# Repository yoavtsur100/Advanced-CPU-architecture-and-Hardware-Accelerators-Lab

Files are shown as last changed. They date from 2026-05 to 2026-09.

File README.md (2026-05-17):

 Advanced CPU Architecture & Hardware Accelerators - VHDL Labs

Welcome to my hardware development repository. This project covers the end-to-end design process of digital systems and processors, from the physical layer to the application layer, implemented in VHDL and validated on FPGA.

## Project Overview
These labs focus on professional hardware design methodologies, emphasizing the full development cycle:
* **Design & Optimization:** Combinational, Synchronous, and Integrated digital systems designed under **PPA (Power, Performance, and Area)** constraints.
* **Verification:** Functional verification, Timing verification, and hardware validation on **FPGA** chips.
* **Computer Architecture:** Deep dive into ISA and Microarchitecture, with a strict separation between **Control Unit** and **Datapath**.

## Development Milestones

## Phase 1: Digital Logic Fundamentals
Implementation of foundational digital systems using VHDL, focusing on synthesis-friendly coding styles and comprehensive Testbench verification.

## Phase 2: CPU Core Development
* **Multicycle Processor:** Designing a separate Control and Datapath architecture.
* **Single-Cycle Processor:** Full implementation and FPGA deployment.
* **V-RISC Pipelined Core:** Development of an N-stage single-threaded pipelined RISC-V processor.

### Phase 3: Final Project - Full MCU System
Design and integration of a complete **Microcontroller Unit (MCU)** on an FPGA, based on a pipelined core. The system features:
* **Peripheral Modules** (IO, Timers, etc.).
* **Interrupt Controller.**
* **Hardware Accelerators (HW Accelerators)** – optimized from the physical layer up to the application software.

---
*Developed as part of the Electrical and Computer Engineering curriculum at Ben-Gurion University.*

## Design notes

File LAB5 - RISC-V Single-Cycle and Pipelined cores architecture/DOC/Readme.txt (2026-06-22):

LAB5 – RISC-V RV32IM Processor Implementation

Advanced CPU Architecture and Hardware Accelerators Lab – 361-1-4693
This project implements a fully functional RV32IM RISC-V processor on a Cyclone V FPGA board (DE10-Lite), in two separate implementations:

-Task 1 – Single-Cycle: Each instruction completes in exactly one clock cycle.
- Task 2 – Pipelined: A classic 5-stage pipeline (IF → ID → EX → MEM → WB) with full hazard detection and resolution.

Both implementations are verified against a RARS golden reference model across four benchmark test programs.

Created by **Yoav Tsur and Elad Lavi**.

Input and Output Description

CLOCK_50_iInput-50 MHz system master clock
KEY0_i-Input  Active-low push-button for synchronous reset (first press releases the CPU from power-up hold) 
SW_i[7:0]- Input -Switches for Signal-Tap trigger address (word address of breakpoint PC) 

clkcnt_o[15:0]` -Output -16-bit clock cycle counter (resets on KEY0, counts from start of execution) 
IFpc_o- Output -Program Counter at the Fetch (IF) stage 
IFinstruction_o- Output -Instruction word at the Fetch (IF) stage 
IDpc_o IDinstruction_o -Output - PC and instruction at the Decode (ID) stage 
EXpc_o EXinstruction_o- Output -PC and instruction at the Execute (EX) stage 
MEMpc_o MEMinstruction_o=Output -PC and instruction at the Memory (MEM) stage 
WBpc_o WBinstruction_o- Output- PC and instruction at the Write-Back (WB) stage 
STRIGGER_o-Output -Signal-Tap trigger: goes HIGH when IFpc[9:2] = SW[7:0] 
FHCNT_o[7:0]- Output - 8-bit flush event counter (counts pipeline flushes due to taken branches) 
STCNT_o[7:0] Output - 8-bit stall cycle counter (counts Load-Use hazard stall cycles) 

Task 1 – Single-Cycle Implementation

All five datapath stages (Fetch, Decode, Execute, Memory, Write-Back) are completed within a single clock cycle. There are no pipeline registers between stages and no hazard handling is required.

VHD Files

cond_compilation_package.vhd
Defines all conditional compilation constants that control the memory configuration and simulation/synthesis mode:
-G_MODELSIM – Selects between ModelSim (1) and Quartus/FPGA (0) mode.
- G_WORD_GRANULARITY` – Selects word-addressed (True) or byte-addressed (False) memory.

const_package.vhd
Defines all instruction-level constants: opcode values, ALU operation codes, and RISC-V instruction format fields used throughout the datapath and control unit.

aux_package.vhd
A VHDL package declaring all component interfaces used across the project (IFETCH, IDECODE, EXECUTE, DMEMORY, etc.), enabling structural instantiation in the core top-level file.

IFETCH.VHD
Implements the Instruction Fetch stage. Contains the Instruction Tightly Coupled Memory (ITCM) instantiated as an Altera altsyncram ROM, pre-initialized from a .hex file. Computes PC+4 via a combinational adder and selects the next PC value using two multiplexers: one for branch/JAL targets and one for JALR targets. The PC register updates synchronously on the rising clock edge.

IDECODE.VHD
Implements the Instruction Decode stage. Contains the 32×32-bit Register File with two asynchronous read ports and one synchronous write port (clocked on the falling edge to enable same-cycle read-after-write). Performs sign-extension of immediate fields for all RISC-V instruction formats (I, S, B, U, J types).

CONTROL.VHD
Implements the combinational Control Unit. Decodes the 7-bit opcode and generates all control signals: RegWrite, MemWrite, MemRead, MemtoReg, ALUSrc, Branch, Jal, Jalr, UpperIm, ALUOp, MULop, and WBSrc. Supports all RV32IM instruction types (R, I, S, B, U, J) including the MUL instruction extension.

EXECUTE.VHD
Implements the Execute stage. Contains the main ALU that performs arithmetic (ADD, SUB, SLT, SLTU), logical (AND, OR, XOR), shift (SLL, SRL, SRA), and comparison operations based on the 5-bit ALUOp control signal. Also computes the branch/JAL target address by adding the sign-extended immediate to the PC. The branch condition (brTaken) is resolved combinationally here. Integrates the multiplier_16bit sub-module for MUL operations.

multiplier_16bit.vhd
Implements a combinational 16-bit×16-bit multiplier supporting the RV32M MUL instruction extension. Uses a two-stage decomposition: splits the 16-bit operands into 8-bit halves, computes four 16-bit partial products (P0–P3), sums the cross-terms (P1+P2), and accumulates all partial products with appropriate bit-shifts to produce a 32-bit result.

DMEMORY.VHD
Implements the Memory stage. Contains the Data Tightly Coupled Memory (DTCM) instantiated as an Altera altsyncram in single-port mode, pre-initialized from a .hex file. Supports synchronous write (on the inverted clock edge) and combinational read. Also selects between the ALU result and the multiplier result based on WBSrc.

RV32I_CORE.vhd
The structural top-level of the single-cycle processor. Instantiates and interconnects all five stage modules (IFETCH, IDECODE, CONTROL, EXECUTE, DMEMORY) using internal signals. Manages the PLL instantiation (active when G_MODELSIM=0) or direct clock bypass (when G_MODELSIM=1). Includes a free-running 16-bit clock counter that resets synchronously and counts cycles from reset release.

FPGA_Top_SingleCycle.vhd
The FPGA top-level wrapper for the single-cycle implementation. Directly maps physical board signals (CLOCK_50, SW0 for reset) to the RV32I_CORE ports. Exposes all internal signals as outputs for Signal-Tap probing and hardware verification.

PLL.vhd
An Altera altpll megafunction-generated component. Takes the 50 MHz board oscillator and divides it to produce a stable lower-frequency internal clock for the processor core. Active only when G_MODELSIM=0 (FPGA synthesis mode).

 Task 2 – Pipelined Implementation

A classic 5-stage in-order pipeline: IF → ID → EX → MEM → WB. Pipeline registers separate each stage. The design includes:
- Load-Use Hazard Detection – inserts one stall cycle (bubble into ID/EX register).
- Control Hazard Resolution – flushes the three instructions after a taken branch (resolved in MEM stage).
- Data Forwarding – forwards EX→EX and MEM→EX paths to eliminate most RAW hazards without stalling.
- Power-Up Reset Latch – holds the CPU in reset until KEY0 is pressed at least once after FPGA configuration.

cond_compilation_package_pipeline.vhd
Same role as in the single-cycle design but for the pipelined version. Key parameters:
- G_MODELSIM – 0 for FPGA synthesis (enables PLL), 1 for ModelSim simulation (bypasses PLL).
- G_ADDRWIDTH / `G_DATA_WORDSNUM` – Must match the depth of the .hex 

const_package_pipeline.vhd
Defines all RISC-V opcode and ALU operation code constants for use throughout the pipeline stages.

aux_package_pipeline.vhd
Declares all pipelined component interfaces for structural instantiation in the core.

IFETCH_pipeline.vhd
Implements the Instruction Fetch (IF) pipeline stage. Contains the ITCM (altsyncram ROM) pre-initialized from a .hex file. Computes PC+4 combinationally and selects the next PC through two multiplexers controlled by Branch_or_jal and Jalr_ctrl. The PC register updates synchronously with stall support via the PCwrite_i enable signal.

IDECODE_pipeline.vhd
Implements the Instruction Decode (ID) pipeline stage. Contains the 32×32-bit Register File with asynchronous reads and a synchronous write port (falling-edge clocked). Performs sign-extension of all immediate formats. Outputs register values and sign-extended immediate to the ID/EX pipeline register.

CONTROL_pipeline.vhd
Implements the combinational Control Unit for the pipeline. Decodes opcode and funct3/funct7 fields to generate all pipeline control signals. When a stall is inserted, control signals are zeroed (NOP bubble).

EXECUTE_pipeline.vhd
Implements the Execute (EX) pipeline stage. Contains the main ALU performing all RV32IM arithmetic, logical, shift, and comparison operations. Selects ALU operands through forwarding multiplexers. Computes the branch/JAL target address. Instantiates the 16-bit multiplier sub-module for MUL support.
DMEMORY_pipeline.vhd
Implements the Memory (MEM) pipeline stage. Contains the DTCM (altsyncram single-port) pre-initialized from a .hex file, with synchronous write and asynchronous read. Generates the Flush_o signal when a taken branch is detected, triggering a 3-cycle flush of the IF/ID/EX pipeline registers.

WriteBack_pipeline.vhd
Implements the Write-Back (WB) pipeline stage. Selects between the DTCM read data and the ALU/multiplier result using multiplexers controlled by MemtoReg and WBSrc. Outputs the final write-back data to the register file.

Forwarding_unit.vhd
Implements the Data Forwarding Unit. Compares the source register addresses (rs1, rs2) of the EX-stage instruction with the destination register addresses (rd) of the MEM-stage and WB-stage instructions. Generates 2-bit forwarding select signals (ForwardA, ForwardB) to route the correct data to the ALU inputs, eliminating most RAW data hazards without stalling.

Stall_cond_unit.vhd
Implements the Hazard Detection / Stall Condition Unit. Detects Load-Use hazards: when the EX-stage instruction is a load (MemRead=1) and its destination register matches a source register of the immediately following ID-stage instruction. When detected, de-asserts PCwrite and IFID_write (freezing IF and ID stages) and inserts a NOP bubble into EX for one cycle.

RV32I_CORE_pipeline.vhd
The structural top-level of the pipelined processor. Instantiates and interconnects all five pipeline stage modules and the two hazard-handling units. Contains all five inter-stage pipeline registers as synchronous processes with synchronous reset. Includes three free-running counters:
- `mclk_cnt_q` – Total clock cycle counter.
- `stl_cnt_q` – Stall cycle counter (increments when stall=1).
- `fhl_cnt_q` – Flush cycle counter (increments when MEM_flush=1).

Also generates STRIGGER_w: goes HIGH when IFpc[9:2] = SW[7:0], used as the Signal-Tap hardware trigger for breakpoint-based verification.

FPGA_Top_pipeline.vhd
The FPGA top-level wrapper for the pipelined implementation. Key features:
- **Power-Up Reset Latch:** A flip-flop that initializes to '0' and latches to '1' upon the first press of KEY0, preventing the CPU from executing on uninitialized memories immediately after FPGA configuration.
- Routes SW_i[7:0] to BPADDR_i for Signal-Tap trigger address selection.

PLL_pipeline.vhd
An Altera altpll megafunction-generated component. Uses a ×1/÷2 configuration to produce a stable 25 MHz internal clock from the 50 MHz board oscillator. Active only when G_MODELSIM=0.

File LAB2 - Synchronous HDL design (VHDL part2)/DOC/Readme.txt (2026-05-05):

Project Overview:
In this laboratory, we will design a synchronous digital system that detects valid sub-series for a given conditional value. We have designed the system top module by using Adder sub-module. The system’s primary goal is to identify sequences where the difference between two consecutive N-bit samples (x[j-1] - x[j-2]) remains constant and matches a specific value determined by the Detection code input. 
Input and Output Description:
* Data Inputs (x): The system samples the value of x (An n-bit wide vector representing the incoming data stream) at every rising edge of clk, provided that ena is high. These samples are stored in a two-stage pipeline to calculate the arithmetic difference.
* clk(clock): The system's primary timing signal. All operations are synchronized to the rising edge of this signal.
* rst (Reset): An active-high control signal. When asserted, it initializes the system by clearing the sampling registers and sequence counter, forcing the Detector output to 0.
* ena (enable): A control signal that governs system operation. If de-asserted ('0'), the system enters a "frozen" state where it ignores new samples and pauses the counter.
* DetectionCode: A selection input that defines the required arithmetic difference for detection. It maps values (0–3) to the expected differences (1–4) according to the project specifications.
* Detection Flag - OUTPUT: This logical signal is 1 only when the system identifies a valid sub-series that meets the difference criteria. It returns to 0 immediately if the sequence is broken or the system is reset.

The VHD file:
AuxPackage.VHD:
* This file contains in the form of a package all the components that we would like to use throughout the laboratory.
Adder.VHD:
* This module implements a generic ripple adder.
Top.VHD:
* This module wraps the entire system and implements a structural and behavioral design hierarchy. We were asked to separate the task into 3 processes:
1. Sampling Process: Responsible for sampling the input data stream x. It uses a two-stage pipeline to store the current and previous samples.
2. Logic & Calculation Process: This stage performs the arithmetic operation using a structural Ripple Carry Adder. It calculates the difference between the samples and compares it against the expected value. A valid signal is asserted if matches.
3. Counting & Detection Process: This process manages a synchronous counter. Only when the enable is '1' and the valid signal is asserted, the counter increments. If the valid signal drops or a reset occurs, the counter is cleared to 0. Once the counter reaches the threshold , the detector output is asserted to 1.

Created by Yoav Tsur and Elad Lavi.

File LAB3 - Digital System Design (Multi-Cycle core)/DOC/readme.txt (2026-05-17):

Multi-Cycle Processor Core in VHDL

This project implements a multi-cycle processor core in VHDL.
The processor is organized around a Control Unit and Datapath architecture, supporting arithmetic, logical, memory access, and branching instructions.

Input and Output Description:
* clk – system clock .
* rst – processor reset.
* ena – processor enable signal.
* done – indicates completion of program execution.(Output) 
* Testbench Interfaces
Additional testbench ports are included for simulation support, allowing:
* Program memory (ITCM) initialization
* Data memory (DTCM) initialization
* Memory read/write access during verification
* Testbench-controlled execution flow. 

Top.vhd 
Top-level integration module connecting the Control Unit (FSM), Datapath.
From the datapath we get the status registers of which instruction we need to perform, and the FSM will output the control data for the datapath to perform the needed task.

Control.vhd 
 FSM-based control unit its purpose is to receive the op code the system needs to perform.
The right control flags will turn on to the datapath and dictating the needed operation.

Datapath.vhd   
Main datapath implementation responsible for data movement between processor components, including register transfers, ALU execution, and memory access operations.  
Implements a shared bus architecture with tri-state buffers for controlled data transfer between modules.

ALU.vhd 
Arithmetic Logic Unit implementing arithmetic and logical operations such as add, sub, OR, AND, and XOR.  
Additionally, generates processor status flags: Negative (N), Zero (Z), and Carry (C).

Adder.vhd
This module implements a generic ripple adder.

OpcodeDecoder.vhd  
Decodes the opcode from IR[15:12] and outputs the corresponding instruction signals to the Control Unit.

RF.vhd 
Register File implementation for general-purpose registers, supporting read and write operations for processor instruction execution.

RegisterA.vhd  
Temporary operand register used in the datapath to store ALU input operands during instruction execution.

RegisterC.vhd
Temporary result register used in the datapath to store ALU output values during instruction execution. Implemented as a master-slave register for synchronized sequential operation.

IR.vhd  
Instruction Register (IR) module responsible for latching instructions fetched from program memory when IRin = '1', and providing decoded instruction fields such as opcode, offset, and immediate values for execution.

ProgamCounter.vhd
Program Counter (PC) module responsible for tracking instruction execution flow by storing the current instruction address and updating it for sequential execution or jump operations.

DFlop.vhd 
Generic D Flip-Flop module providing synchronous data storage with clock and reset control, used throughout the processor’s sequential logic.

progMem.vhd 
Program memory module responsible for storing assembly instructions and supplying the appropriate instruction to the processor according to the current Program Counter (PC) address.

dataMem.vhd  
Data memory module used for processor data storage, supporting read and write access for load and store instructions.

BidirPin.vhd 
Bidirectional interface module implementing tri-state bus connectivity for controlled data transfer between shared processor modules.

aux_package.vhd 
This file contains in the form of a package all the components that we would like to use throughout the laboratory.

Created by Yoav Tsur and Elad Lavi.

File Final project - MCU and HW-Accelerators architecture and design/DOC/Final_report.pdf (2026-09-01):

## FINAL REPORT FOR FINAL PROJECT

## ADVANCED CPU ARCHITECTURE AND HARDWARE

## ACCELERATORS LAB

361.1.4693

## Yoav Tsur 211903406 Elad Lavi 211626551

## 2026 Semester B

## תוכן עניינים

מבוא למערכת הכוללת 3
חלק ראשון - הליבה Core V-RISC 5 תוספת המחלק לליבה כמאיץ חומרתי 9 ולידציה עבור פעולת המחלק 13 חלק שני - Peripherals GPIO 15 ולידציה עבור רכיבי הGPIO 18 חלק שלישי - פסיקות - Interrupts 20 ולידציה עבור רכיבי :Interrupt 26 חלק רביעי - הטמעת המערכת בכרטיס 10DE FPGA 29 חלק חמישי - ניתוח ביצועים 31

## מבוא למערכת הכוללת

במעבדה זו נממש מערכת מורכבת המתבססת על ליבת מעבד הסינגל סייקל ממעבדה מספר 5 ונרחיב אותה למערכת שלמה המבצעת גם חלוקה ושארית, ובנוסף התמודדות עם בקשות פסיקה תוך כדי שגרה שוטפת, תקשורת שוטפת לGPIO וסנכרון בין שעונים בתדרים שונים )CDC). להלן ליבת המעבד לאחר ההרחבה:

ליבה זו מרחיבה את ליבת המעבד סינגל סייקל לתמיכה בפעולת חילוק בין שני מספרים UNSIGNED הדורשת הוספת מאיץ חומרתי ייעודי לשם כך והוספת לוגיקה. בנוסף כפי שניתן לראות מן התמונה, מודול המחלק מוזן משעון שונה divclk ולשם כך נדרש סנכרון בין פעילות המעבד השוטפת המוזנת מן השעון mclk לבין שעון המחלק.
כעת נציג את המערכת הכוללת:

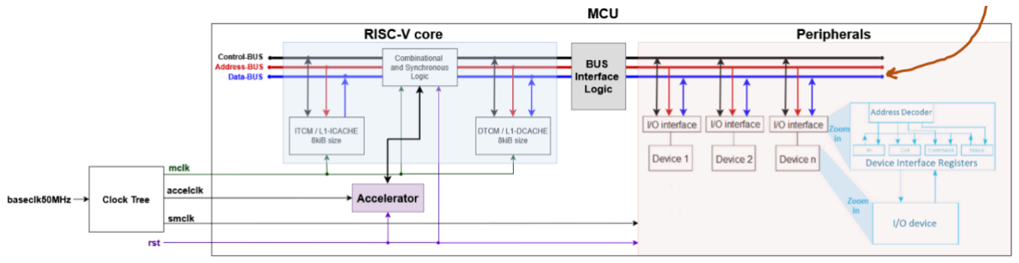
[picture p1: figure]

Figure 1: MCU System uArch

כפי שניתן לראות באיור, המערכת כולה מתוכננת כמיקרו-בקר שלם הכולל הפרדה פיזית בין זיכרון התוכנית לבין זיכרון הנתונים. הקישוריות בין הליבה לבין שאר חלקי המערכת מתבצעת דרך מערכת באסים הכוללת את באס הכתובות, באס הנתונים ובאס הבקרה. דרך קווים אלו, המעבד מנהל את התקשורת מול הזיכרון ומול הלוגיקה המקשרת לרכיבים הפריפריאליים.

אפיק הנתונים הפנימי של הליבה מקושר באמצעות באס נתונים דו-כיווני משותף ברוחב 32 ביט. בנוסף נעשה שימוש ב-buffers state-Tri, באמצעות רכיב BidirPin כאשר אנחנו מווסתים את היציאות של כתיבת נתוני המעבד וקריאת נתוני ה-DTCM אל הבאס, ובכך מונעים Contention Bus.

התקשורת מול רכיבי קלט/פלט )interface O/I )מתבצעת בשיטת O/I Mapped Memory, שבה הרכיבים החיצוניים ממופים כחלק ממרחב הכתובות של זיכרון הנתונים. מרחב כתובות זה מחולק לשני אזורים לוגיים עיקריים: החלק התחתון מוקצה לזיכרון הנתונים הפיזי, ואילו החלק העליון שמור לאוגרים ייעודיים )- SFR Registers Function Special )המשמשים את רכיבי הפריפריה השונים. הגישה לרכיבי ה-GPIO ולזיכרון עצמו נעשית על ידי מפענח כתובות חומרתי, אשר מנתח את הכתובת בת 14 הביטים שמייצר המעבד וקובע בזמן אמת איזה רכיב מופעל.חלוקת מרחב כתובות זה מוצג באיור הבא:

Figure 2: Data Address Space Map

בנוסף לממשק הO/I, המערכת מורחבת על ידי הוספת רכיבים פריפריאליים מתקדמים התומכים בפסיקות, ביניהם טיימר בסיסי בעל יכולות השוואה והפקת אותות PWM, ובקר פסיקות. מנגנון הפסיקות מאפשר למעבד להשהות את שגרת הביצוע השוטפת שלו על מנת להגיב לאירועים חיצוניים בזמן אמת. כאשר מתקבלת דרישת פסיקה מאחד ממקורות הפריפריה, בקר הפסיקות שולח אות בקשה )INTR )למעבד. בתגובה, המעבד משיב באות אישור )INTA )וקופץ לטפל באירוע בהתאם לרמת העדיפות המוגדרת עבורו בטבלת הפסיקות.

לשם ניהול זמנים והפעלה תקינה של כלל תתי-המערכות, מיושם במערכת עץ שעונים. עץ השעונים מקבל שעון בסיס של MHz50 ומפיק ממנו מספר תחומי תדר שונים הנדרשים למודולים השונים: שעון ה-mclk המזין את ליבת המעבד המרכזית, שעון ה-smclk עבור רכיבי הפריפריה, ושעון ה-accelclk המזין את המאיץ החומרתי. חלוקה זו של שעונים בתדרים שונים מחייבת יישום מנגנוני סנכרון על מנת להבטיח העברת נתונים אמינה ולמנוע מצבי מטא-סטביליות.

## חלק ראשון - הליבה Core V-RISC

ארכיטקטורת הליבה הכוללת )IMscMCU32RV): ליבת המעבד ממומשת כמודל VHDL מבני בקובץ vhd.IMscMCU32RV. הליבה משלבת ארכיטקטורת זיכרון מסוג הארוורד. הליבה פועלת כולה בארכיטקטורת מחזור-יחיד למעט הרחבת מאיץ החילוק הרב-מחזורי. כל פקודה רגילה נשלפת, מפוענחת, מבוצעת, ותוצאותיה נכתבות חזרה לFile Register או לזיכרון ה-DTCM בתוך מחזור שעון אחד. נשים לב כי קובץ הבקרה )vhd.control )כולל בתוכו גם את מכונת המצבים לטיפול בפסיקות והתאמת הבקרה והלוגיקה הנדרשת למערכת כולה, כמו כן בוצעו התאמות לשאר חלקי המעבד על מנת לתמוך בזרימה כוללת תקינה כנדרש.

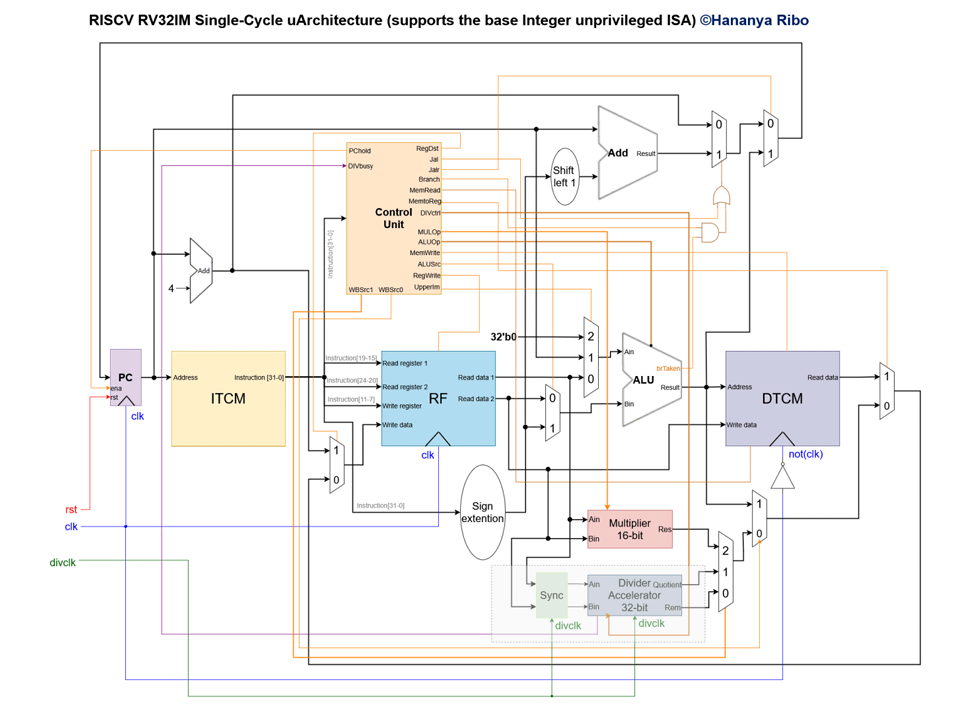
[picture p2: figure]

Figure 3: RISCV RV32IM uArch

קבצי VHD בסיסיים המרכיבים את הליבה:

IFETCH.VHD .1
שלב זה אחראי על יצירת הכתובת הבאה של מונה התוכנית )PC )ושליפת הפקודה )32 ביט( מזיכרון ה-ITCM. בשלב זה ישנם מספר רכיבי חומרה הנמצאים בשימוש: מונה התוכנית )PC): בגודל 32 ביט השומר את כתובת הפקודה הנוכחית. מתעדכן בעליית השעון, אלא אם כן דגל ההשהיה PChold פעיל.
Adder Sequential מחשב את הכתובת הבאה )+4PC )במקביל לביצוע הפקודה הנוכחית, ומכין את כתובת ברירת המחדל לפקודה העוקבת. Multiplexers Address Target בוררים את מקור הכתובת הבאה של ה-PC בהתאם לאותות הבקרה משלב Execute ומיחידת הבקרה.
פסיקה )Target Interrupt): כאשר האות i_ctrl_IntJump פעיל )בזמן קפיצה לשגרת טיפול בפסיקה(, ה-PC מדלג לכתובת הווקטור הנקראת מתוך טבלת הפסיקות )IVT). באמצעות ה ITCM מזהים את ה Instruction שיש לבצע.

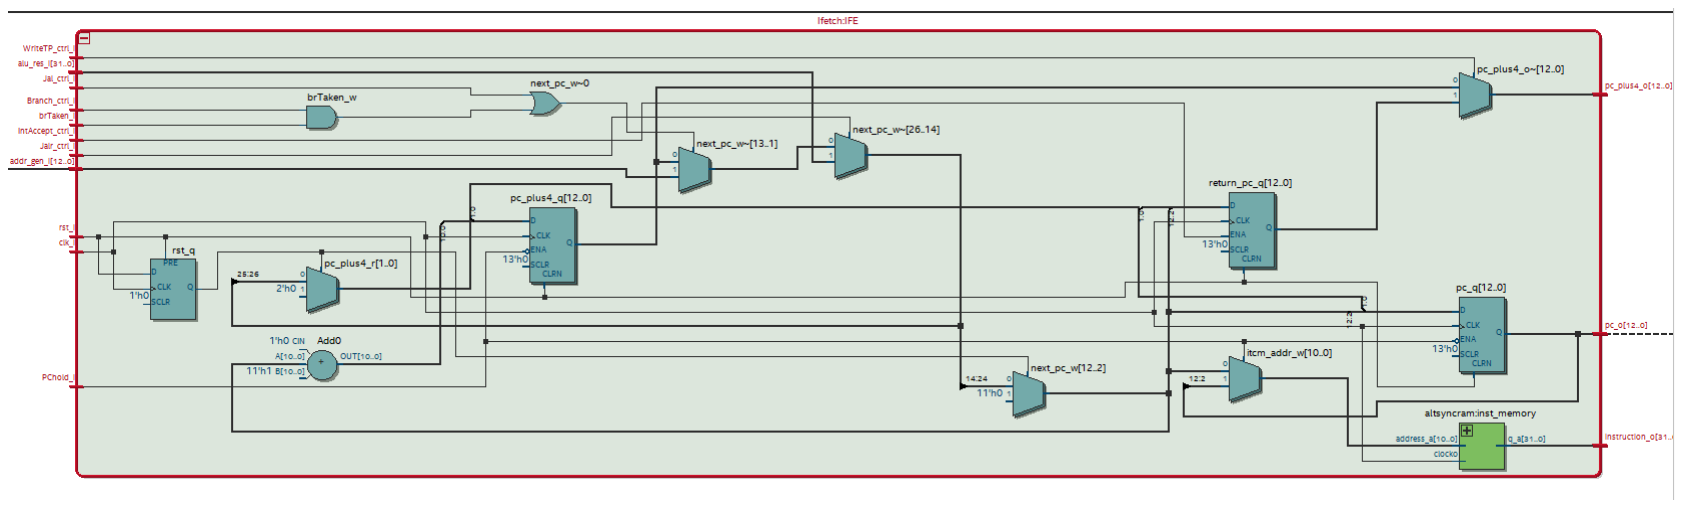
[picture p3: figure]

Figure 4: RV32IM Fetch Unit RTL

IDECODE.VHD .2
שלב זה אחראי על פירוק הפקודה שנשלפה והעברת השדות ליחידת הבקרה )שנמצאת בשימוש בשלב הדיקוד גם כן(, קריאת האופרנדים מתוך ה־File Register והפקת ערך ה־Immediate בהתאם לפורמט הפקודה.
File Register: מכיל 32 אוגרים כלליים בגודל 32 ביט )31x–0x). הקריאה מתבצעת דרך שני פורטי קריאה בהתאם לשדות 1rs ו־2rs של הפקודה. כתיבה לאוגר היעד rd מתבצעת בעליית השעון כאשר Reg ctrl_Write פעיל. האוגר 0x נשאר קבוע בערך .0 Extension Sign / Immediate: המודול מחלץ את שדה ה־Immediate בהתאם לסוג הפקודה ,U ,B ,S ,I J ומרחיב אותו ל־32 ביט תוך שמירה על הסימן. MUX Back-Write: הנתון הנכתב ל־RF נבחר בין תוצאת ה־ALU, נתון שנקרא מה־DTCM או כתובת החזרה +4PC, בהתאם לאותות הבקרה. בקרת פסיקות: הביט 0 באוגר 3x משמש כ־GIE Enable Interrupt Global. בעת כניסה לטיפול בפסיקה הביט מאופס, ובחזרה מהפסיקה הוא נקבע מחדש ל־.1 בנוסף, בעת כניסה לפסיקה ניתן לכפות את 4x כאוגר היעד לצורך שמירת כתובת החזרה.

Figure 5: RV32IM Decode Unit RTL

EXECUTE.VHD .3
שלב זה אחראי על ביצוע הפעולות האריתמטיות, הלוגיות ופעולות ההזזה על האופרנדים. בנוסף, הוא מעריך תנאי קפיצה ומחשב את כתובות היעד.
.ALUה־ | ליחידת | bin_wו־ ain_w | הכניסות | את | בוררים | :Operand Source MUXs
w_ain בורר בין ערך האוגר 1data_read לבין כתובת ה־PC הנוכחית, ו־w_bin בורר בין 2data_read לבין .sign_extend
יחידת ALU: מבצעת את הפעולות בהתאם לאות ctrl ALUOp, כולל פעולות אריתמטיות, לוגיות, הזזה והשוואה.
בין | בוחר | WBSrc1 | האות | ,REMו־ MUL, DIV | בפקודות | תמיכה | לצורך | :M-extension Result MUXs
RESIDUE עבור REM, QUOTIENT עבור DIV, ותוצאת המכפל w_resmul עבור MUL. לאחר מכן, 0WBSrc בוחר בין תוצאת ה־extension-M לבין תוצאת ה־ALU הרגילה )r_res_alu), והתוצאה הנבחרת מועברת דרך o_res_alu להמשך ה־datapath.

Figure 6: RV32IM Execute Unit RTL DMEMORY.VHD .4
מודול זה מממש את זיכרון הנתונים DTCM, שבו מאוחסנים משתני הנתונים של התוכנית. שעון הזיכרון: שעון הכתיבה לזיכרון הוא השעון ההפוך של שעון המעבד )i_clk not <= w_wrclk). לכן פעולת הכתיבה מתבצעת בחזית הנגדית לזו שבה מתעדכנים רכיבי המעבד, וכך ניתנת לכתובת ולנתוני הכתיבה אפשרות להתייצב לפני הכתיבה לזיכרון כיוון שאנחנו "מחלקים את המחזור" לשני חלקים. נתיב כתיבה: כאשר ctrl MemWrite פעיל, הערך wr_data_dtcm נכתב לתא הזיכרון הנבחר על ידי .dtcm_addr
נתיב קריאה: הערך שנמצא בכתובת addr_dtcm מתקבל ישירות ביציאה o_rd_data_dtcm. בהמשך המערכת, אותות הבקרה קובעים מתי נתון זה משמש את המעבד או מועבר ל־DataBUS.

Figure 7: RV32IM Memory Unit RTL

multiplier_16bit.vhd.5
מודול זה מממש מכפל קומבינטורי בגודל 16×16 ביט, והוא משולב בשלב ה־EXECUTE לצורך ביצוע פעולת כפל. המכפיל מקבל את 16 הביטים הנמוכים של שני האופרנדים ומפיק תוצאה בגודל 32 ביט. מכיוון שמדובר במימוש קומבינטורי, החישוב אינו דורש מכונת מצבים או מספר מחזורי שעון. אלגוריתם הכפל: כל אחד מהאופרנדים מחולק לחלק עליון ותחתון של 8 ביט. לאחר מכן מתבצעים ארבעה כפליים מקבילים בגודל 8×8 ביט:
P0=AlowBlow | P1=AlowBhigh, | P2=AhighBlow, | P3=AhighBhigh
התוצאה הסופית מתקבלת מחיבור המכפלות החלקיות לאחר הזזה למקומן המתאים. האות mulOP קובע האם תוצאת המכפל תועבר למוצא rd. כאשר לא מתבצעת פעולת כפל, המוצא מאופס.

Figure 8: RV32IM Multiplier Unit RTL

CONTROL.VHD .6
מודול זה משמש כיחידת הבקרה המרכזית של המעבד. הוא מפענח את הפקודה הנוכחית ומייצר את אותות הבקרה הדרושים לשאר יחידות ה־Datapath, בהתאם לסוג הפקודה ולפעולה הנדרשת. Decode Instruction: הפקודה מפוענחת לפי שדות ה־Opcode וה־Function לצורך זיהוי פעולות
.REMו־ MUL, DIV | פקודות | וכן Jump ,Load/Store, Branch , | ולוגיות | אריתמטיות
Signals Control: בהתאם לפקודה, המודול מייצר את אותות הבקרה כגון ,MemRead ,RegWrite
ואת | הנתונים | מסלול | את | הקובעים | ,ALUOpו־ MemWrite, ALUSrc, MemtoReg, Branch, Jal, Jalr
האותות הנדרשים למוקסים ולכתיבה/קריאה.
,WBSrc1ו־ WBSrc0 ,MULop, DIVctrl | האותות | נוצרים | REMו־ MUL, DIV | עבור | :M-Extension | בקרת
המפעילים את יחידת הכפל או החילוק ובוחרים את התוצאה המתאימה להמשך ה־Datapath. השהיית המעבד בזמן חילוק: פעולת החילוק היא פעולה רב־מחזורית, ולכן ctrl_PChold משמש לעצירת התקדמות ה־PC בזמן שהמחלק פעיל. בנוסף, q_started_div עוקב אחר תחילת פעולת החילוק ומאפשר לבצע Stall כבר במחזור הראשון, לפני ש־DIVbusy עולה, וכן מונע הפעלה חוזרת של המחלק בזמן שהפקודה מוחזקת.
המודול כולל גם את לוגיקת הבקרה הנדרשת לטיפול בפסיקות ולפרוטוקול INTA/INTR, אשר תפורט בנפרד בפרק העוסק במערכת הפסיקות.

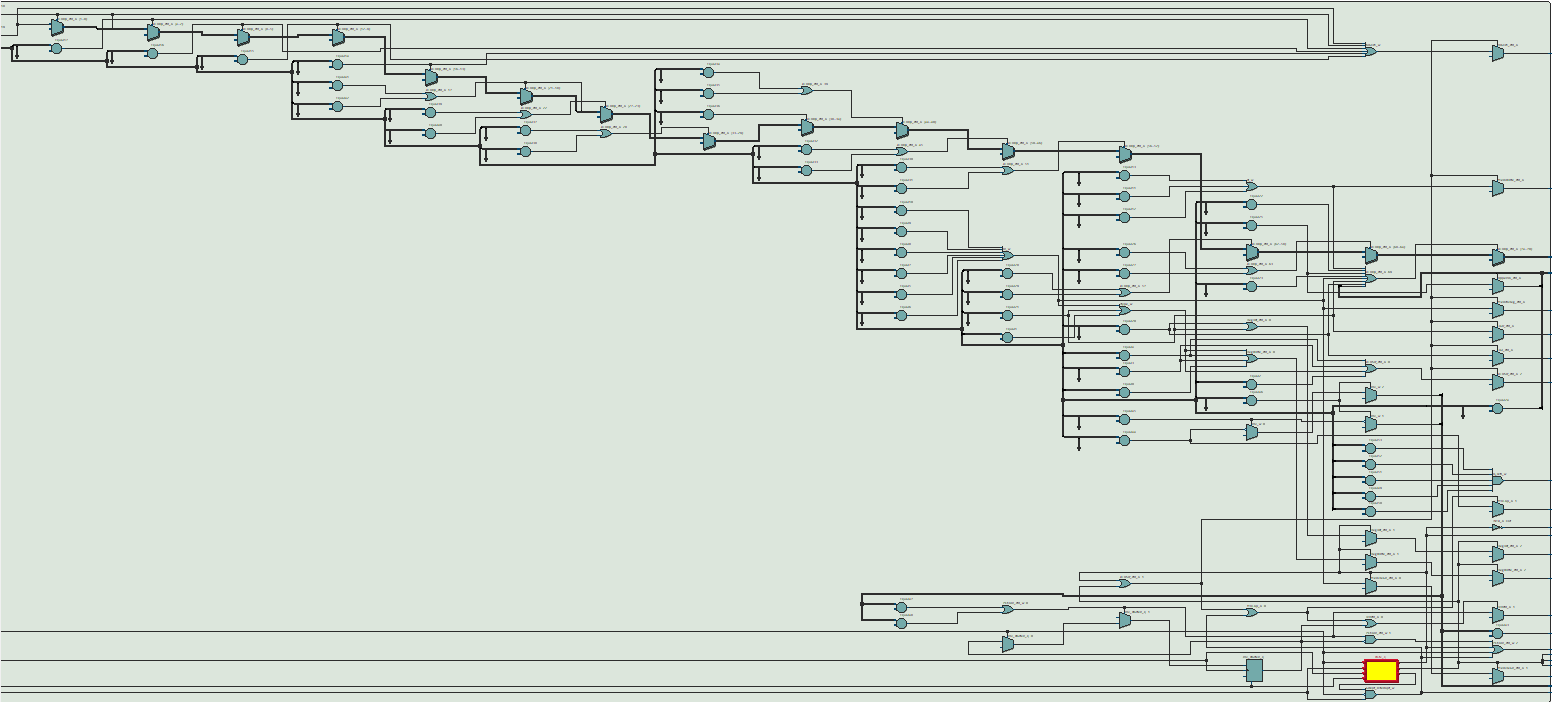
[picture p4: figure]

Figure 9: RV32IM Control Unit RTL

ובנוסף מצורף RTL כללי של הליבה המכיל את כל הרכיבים אשר פירטנו עליהם. כפי שציינו ליבה זאת מתחברת לממשק הTOP באמצעות TriState לצורך מניעת התנגשות על הBUS.

Figure 10: RV32IM Unit RTL

## תוספת המחלק לליבה כמאיץ חומרתי

:divider_32bit.vhd | המחלק | מימוש
בחלק הראשון של הפרויקט נדרשנו לממש מאיץ חומרה לביצוע פעולות חילוק ושארית )DIV ו־REM )עבור מספרים Unsigned, כחלק מהרחבת ליבת ה־IM32RV. המחלק ממומש כ־Accelerator Division Cycle Multi המחובר לליבת המעבד ופועל בתחום שעון נפרד משעון המערכת. עובר אופרנדים בגודל 32 ביט )32=N), פעולת החילוק מתבצעת באופן איטרטיבי לאורך 32 מחזורי DIVCLK.
קלטי המחלק:
Dividend – המספר המחולק.
Divisor – המספר המחלק.
DIVCLK – שעון המאיץ.
Reset – איפוס המודול.
DIVENA – אות Enable המתחיל פעולת חילוק. מוצאי המחלק:
Quotient – מנת החילוק.
Residue – שארית החילוק.
DIVBUSY – אות המציין שהמחלק נמצא במהלך ביצוע פעולה ומשמש את יחידת הבקרה לצורך עיכוב המעבד עד לסיום החישוב
אלגוריתם המחלק:
המחלק מממש אלגוריתם חילוק בינארי איטרטיבי עבור מספרים Unsigned, כאשר בפרויקט זה 32=N. כאשר אות הבקרה DIVENA עולה בזמן שהמחלק פנוי, נטענים אופרנדי ה-Dividend וה-Divisor לרגיסטרים הפנימיים, רגיסטר המנה מתאפס, המונה מתחיל מ0- ואות ה-DIVBUSY עולה ל1- כדי לאותת שהיחידה עסוקה. המימוש החומרתי עושה שימוש ברגיסטר הזזה בגודל N2 ביטים, כאשר מחציתו העליונה מחזיקה את השארית החלקית ומחציתו התחתונה מחזיקה את ביטי ה-Dividend שטרם עובדו. בכל מחזור של שעון ה-DIVCLK מתבצעת איטרציה אחת שבה השארית החלקית מוזזת שמאלה ומצורף אליה הביט הבא של ה-Dividend. הערך המתקבל מושווה ל-Divisor: אם הוא גדול או שווה לו, מתבצע חיסור )התוצאה אינה שלילית( ונוסף הביט 1 למנה, ואחרת לא מתבצע חיסור ונוסף הביט 0 למנה. התהליך חוזר על עצמו במשך 32 איטרציות, ולאחר מכן DIVBUSY יורד ל0- והתוצאות הסופיות זמינות במוצאי ה-QUOTIENT )מנת החילוק( וה-RESIDUE( שארית החילוק(. לאורך התהליך, האות DIVBUSY משמש את יחידת הבקרה של המעבד כדי להשהות את התקדמותו כל עוד פעולת החילוק הרב-מחזורית טרם הסתיימה.

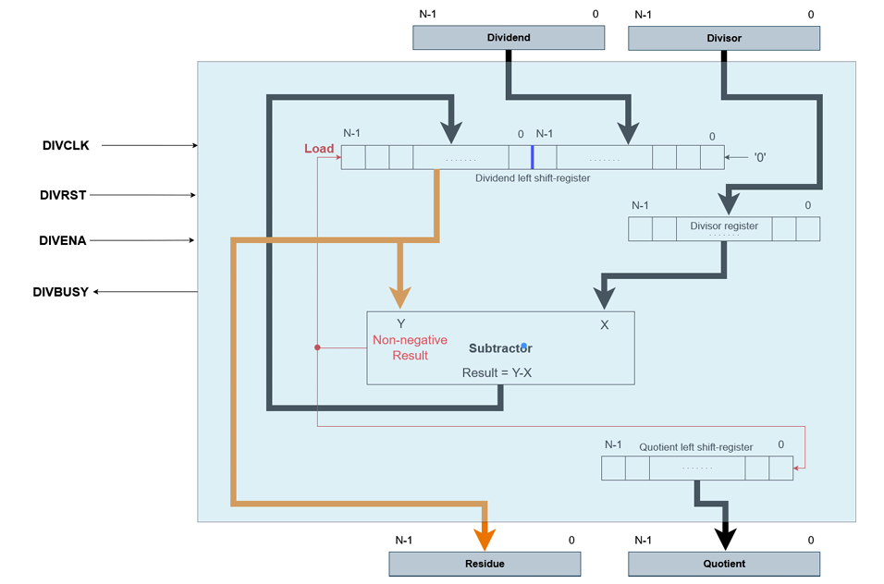
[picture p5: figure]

Figure 11: Multicycle-based architecture of Unsigned Divisor accelerator

מצורף צילום של הRTL עבור מודול ה- bit32Divider:

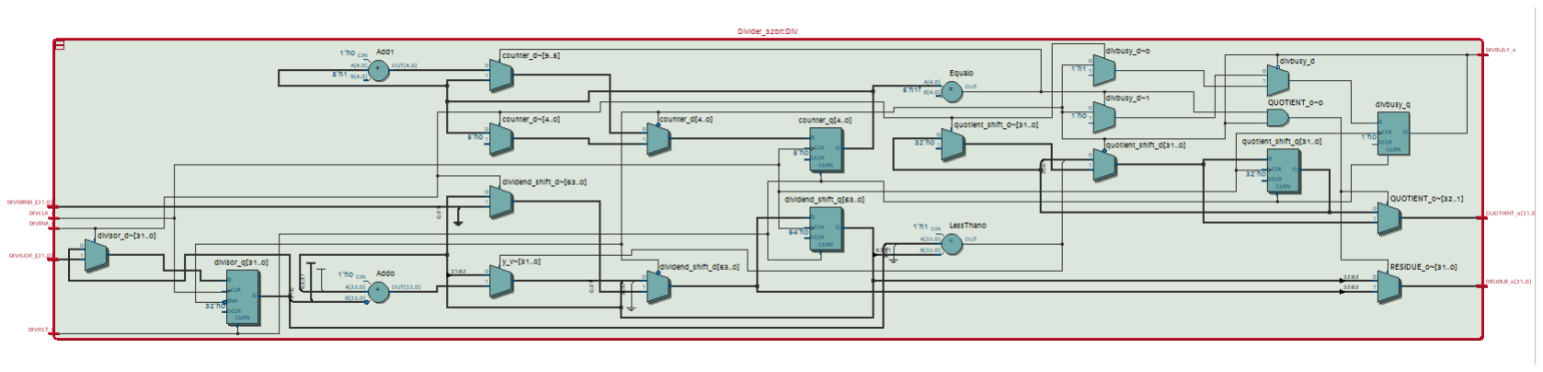
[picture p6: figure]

Figure 12: RV32IM Divider Unit RTL

:sync.vhd מסנכרן
המחלק פועל באמצעות DIVCLK, בתדר שונה משעון המערכת של המעבד. לעומת זאת, האופרנדים המועברים למחלק )Dividend ו־Divisor )מגיעים מליבת המעבד ולכן שייכים ל־Clock Domain של שעון המערכת.
כתוצאה מכך נוצר CDC Crossing Domain Clock. ללא סנכרון, שינוי באחד האופרנדים עלול להתרחש בסמוך לחזית העולה של DIVCLK, ובכך להפר את זמני ה־hold/setup של רגיסטר במחלק ולגרום למצב של Metastability. לכן לפני העברת האופרנדים למחלק הם מועברים דרך מודול Synchronizer.

אופן פעולת המסנכרן
במימוש שלנו כל אחד משני האופרנדים עובר דרך שתי דרגות של רגיסטרים, הפועלות לפי :DIVCLK
Ain_i → Ain_q1 → Ain_q2 → Ain_o Bin_i → Bin_q1 → Bin_q2 → Bin_o הדרגה הראשונה קולטת את האות המגיע מתחום השעון של המעבד ועלולה להיכנס לזמן קצר למצב metastable, ואילו הדרגה השנייה דוגמת את הערך לאחר שניתן לו זמן להתייצב. כך קטן משמעותית הסיכון להעברת ערך לא יציב אל המחלק. המסנכרן מטפל בבעיה של מעבר בין שעונים: CPU clock domain → Synchronizer → DIVCLK domain לעומת זאת, DIVBUSY מטפל בכך שהחילוק לוקח 32 מחזורי DIVCLK. בזמן 1=DIVBUSY יחידת הבקרה משהה את התקדמות המעבד, כדי שה־CPU לא יעבור לפקודה הבאה לפני שתוצאת
. | מוכנה | DIV/REM

Figure 13: CDC (clock domain crossing) synchronizer

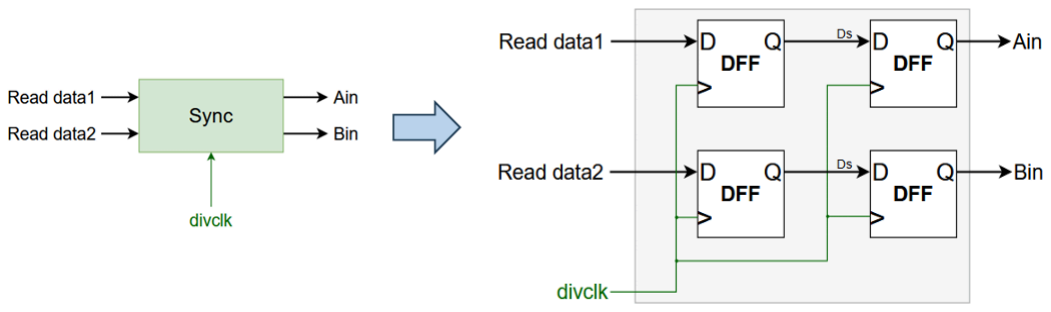
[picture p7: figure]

Figure 14: Synchronizer architecture

מצורף צילום של הRTL עבור מודול ה- Sync:

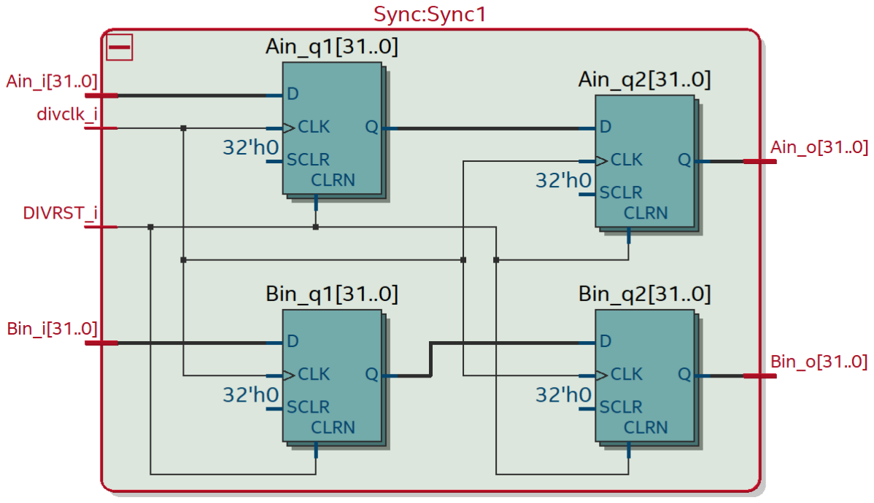
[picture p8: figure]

Figure 15: RV32IM synchronizer Unit RTL

ולדיציה עבור פעולת המחלק
על מנת לבדוק שהמחלק פועל כמו שצריך נדרשנו לבדוק התאמה ופעילות נכונה של המעבד באמצעות טסט שניתן לנו מראש.
הטסט מכיל 131 הוראות מתוכן 11 הוראות הן עבור טעינת הנתונים. שאר ההוראות בנויות מלולאה באורך 8 כך שכל סיבוב של הלולאה מונה כ15 פקודות - 13 פקודות רגילות, פקודת חילוק ופקודת שארית.

Figure 16: Divisor test instruction distribution להלן תוצאות הWaveform במודל סים:

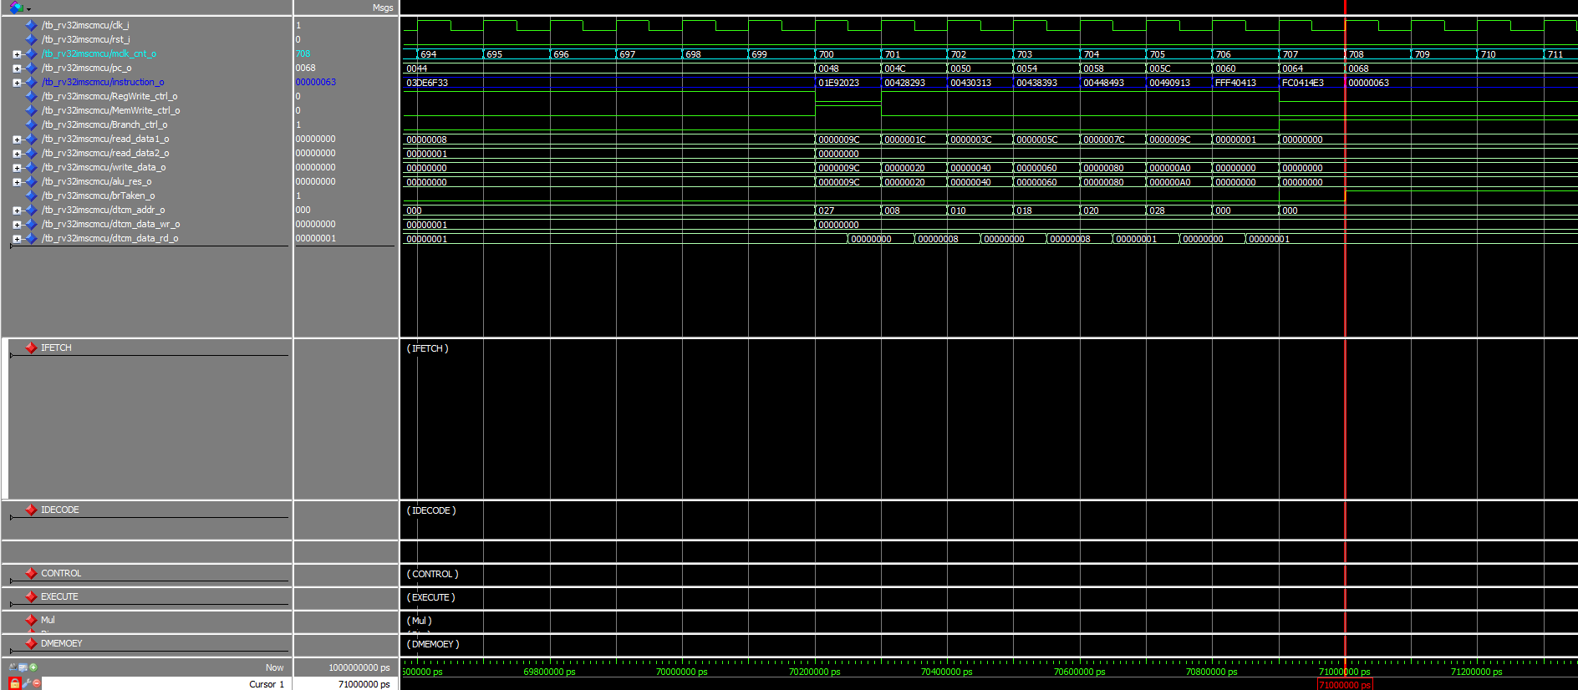
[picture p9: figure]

Figure 17: ModelSim Verification of the Division Accelerator זמן ריצה זה תואם במדויק את המצופה ממבנה הקוד: התוכנית נפתחת ב11- פקודות של טעינת נתונים, אשר כל אחת מהן מתבצעת במחזור שעון יחיד )Cycle Single). לאחר מכן, מתבצעת לולאה החוזרת על עצמה במשך 8 איטרציות. בכל איטרציה של הלולאה ישנן 15 פקודות: 13 פקודות רגילות )הדורשות מחזור שעון אחד כל אחת(, פקודת חילוק ופקודת שארית. מכיוון שפעולות החילוק והשארית מבוצעות על ידי המאיץ הרב-מחזורי, כל אחת מהן עוצרת את המעבד ואורכת 37 מחזורי שעון. מכאן נובע כי כל איטרציה בלולאה דורשת 87 מחזורי שעון )13 + 37 + 37(. סך מחזורי השעון של התוכנית כולה מורכב מ11- מחזורי הטעינה ההתחלתיים בתוספת 8 איטרציות של 87 מחזורים מה שמוביל בדיוק ל707- מחזורי שעון. התאמה מלאה זו מאשרת כי מנגנון הסנכרון וההשהיה של המעבד מול המאיץ פועל כנדרש.

IPC = Instruction/Cycles —-> 131/707 = 0.185
הדבר הגיוני כי אמנם למדנו וראינו במעבדה 5 כי בCycle Single צריך לצאת IPC של ,1 אך מכיוון והוספנו מאיץ חלוקה רב מחזורי הגיוני כי הIPC יצא קטן מ1 מאחר ואנו ממתינים זמן רב.

להלן תוצאות הTap Signal :

Figure 18: STP Validation of the Division Accelerator

ניתן לראות כי גם בבדיקת זמן אמת על FPGA באמצעות TAP Signal קיבלנו תוצאות זהות. נציין כמובן כי הן במודל סים והן בQUARTUS תחת ISMCE נבדקו הזכרונות DTCM לאחר הרצת התוכנית ובוצע השוואה בMoudel Golden מול הRARS לצורך ביצוע נכון ומדוייק של תוצאות הטסט.

## חלק שני - הPeripherals GPIO

בעוד שה־CPU אחראי על שליפה, פענוח וביצוע פקודות, ה־MCU משלב את ליבת המעבד יחד עם זיכרונות והתקנים היקפיים המאפשרים תקשורת עם רכיבי הקלט והפלט של המערכת. במימוש שלנו, הקובץ vhd.SingleCycle_Top_FPGA מהווה את הרמה העליונה של המערכת ומחבר את ליבת IMscMCU32RV לרכיבים הפיזיים בלוח ה־FPGA, כגון המתגים, הלחצנים, הלדים ותצוגות הSeven Segment על גבי ששת צגי הHEX בכרטיס. בפרויקט זה נשתמש ב0Key בתור ריסט המערכת , 1-3Key כבקשות פסיקה ו0-9SW כקלטים. מוצאי המערכת יהיו ב0-9 LED ו 5-0HEX. .Expansion Header GPIO of 2x20 pins יש בנוסף הנחיות מימוש ממשק הGPIO:

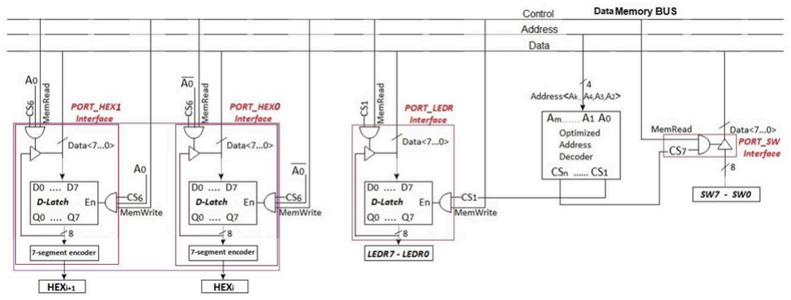
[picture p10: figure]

Figure 19: Basic GPIO peripheral connection using Memory Mapped I/O
בנוסף, ישנו צורך בשימוש של Decoder Address מכיוון שרכיבי ה-GPIO ממומשים בשיטת O/I Mapped-Memory. כלומר, מבחינת ה-CPU, גישה ל-LEDs, ל-HEX או ל-Switches נראית כמו גישה שגרתית לכתובת בזיכרון. לכן נדרש רכיב חומרתי שמקבל את הכתובת שהמעבד מוציא אל הבאס, מנתח אותה, וקובע לאיזה התקן בדיוק הגישה מיועדת. בפועל, המפענח בוחן את ביטי הכתובת ומפיק אות בחירת רכיב )CS - Select Chip )ייעודי עבור ההתקן המבוקש. אות זה, בשילוב עם אותות הבקרה לקריאה )MemRead )או לכתיבה )MemWrite), מבטיח שרק הרכיב הרלוונטי יגיב לפקודת המעבד בעוד שאר הרכיבים בנתק. להלן מיפוי הכתובות לפי רכיבים:

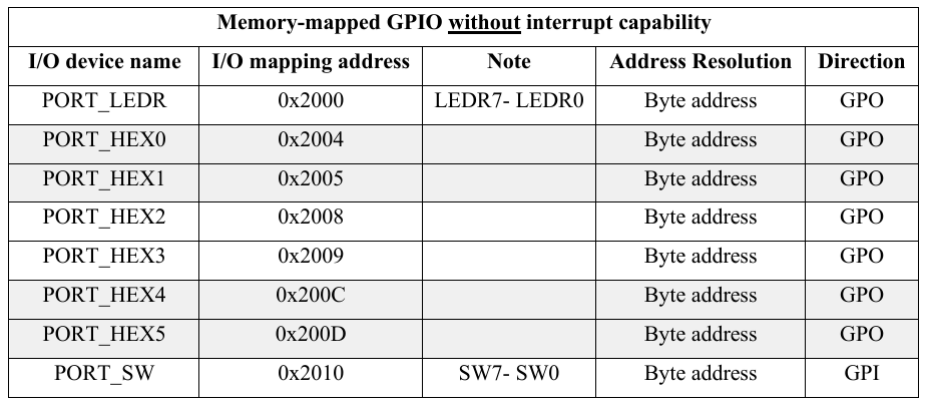
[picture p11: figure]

Table 20: Memory-Mapped Addresses for GPIO Peripherals

קבצי VHD המרכיבים את Peripherals GPIO:

GPIO_peripherals.vhd.1
מודול זה משמש כחוזה בין ליבת המעבד להתקני הקלט והפלט של הלוח באמצעות O/I Mapped-Memory. הוא אחראי על פענוח הכתובות, שמירת ערכי הפלט והעברת ערכי הקלט אל ה־DataBUS. Decoder Address: המודול בודק האם הכתובת נמצאת בתחום ה־F201x0–2000x0 GPIO ומייצר אות Select Chip עבור ההתקן המתאים. הכתובת 2000x0 ממופה ל־LEDR, הכתובות D200x0–2004x0 ממופות לתצוגות 5HEX–0HEX, ו־2010x0 ממופה למתגים SW. עבור זוגות ה־HEX נעשה שימוש גם בביט הכתובת הנמוך )0) i_addr כדי לבחור את התצוגה הספציפית. פעולת כתיבה: כאשר write_mem פעיל, שמונת הביטים הנמוכים של DataBUS נשמרים ברגיסטר הפלט שנבחר על ידי ה־Decoder Address. כך ערכי ה־LEDs וה־HEX נשמרים גם לאחר סיום פעולת הכתיבה. פעולת קריאה: כאשר המעבד קורא מכתובת המתגים, ערך i_pins_SW מורחב ל־32 ביט ומועבר ל־DataBUS. לאחר סיום הקריאה המודול מפסיק לנהוג על ה־bus כדי למנוע התנגשות עם רכיבים אחרים.

Figure 21: GPIO Unit RTL

BidirPin.vhd.2
מודול זה מממש חוצץ דו־כיווני מסוג State-Tri עבור ה־DataBUS המשותף. מטרתו לאפשר למספר רכיבים במערכת להשתמש באותו bus מבלי ליצור התנגשות בין מקורות נתונים שונים. נתיב קריאה: האות Din מחובר ישירות ל־IOpin, ולכן המודול יכול לקרוא באופן רציף את הערך הקיים על ה־bus.
נתיב כתיבה: כאשר 1'=en', הערך Dout מועבר אל IOpin והמודל נוהג על ה־bus. כאשר 0'=en', המוצא עובר למצב Impedance-High, וכך המודול מתנתק מה־bus ומאפשר לרכיב אחר לנהוג עליו. באמצעות מנגנון זה נמנעת Contention Bus, כלומר מצב שבו שני רכיבים מנסים לכתוב בו־זמנית ערכים שונים על אותו קו נתונים.
נציין בנוסף כי יש שימוש במודל זה גם בתוך הליבה וגם ב Controller Interrupt, כלומר כל רכיב אשר מחובר לTOP משתמש במודל זה כדי למנוע התנגשות על הBUS ויצירת CDB.

Figure 22: BidirPin Unit RTL

SevenSegDecoder.vhd .3
מודול זה משמש כמפענח קומבינטורי לתצוגת -7Segment, הממיר ערך הקסדצימלי בגודל 4 ביט )0–F) לתבנית ההדלקה המתאימה של שבעת הסגמנטים. התצוגה פועלת בשיטת Low-Active, כלומר ערך '0' מדליק סגמנט וערך '1' מכבה אותו. בהתאם לערך הקלט, המודול בוחר באמצעות CASE את תבנית ה־seg המתאימה להצגת הספרה או האות ההקסדצימלית.

Figure 23: HEX mapping from Binary vector to Hex digit

Figure 24: Seven Segment Display RTL

ולדיציה עבור רכיבי הGPIO
על מנת לבדוק שרכיבי הGPIO פועלים ומגיבים בהתאם לתוכנית ביצענו בדיקות שלושת הטסטים שקיבלנו. טסט :0
טסט זה בודק את פעולת התקני הפלט של ה־GPIO. התוכנית מבצעת ספירה עולה ב־1 בצורה מחזורית, ומציגה את ערך המונה בנפרד על כל התקני הפלט: LEDR ו־5HEX–0HEX. כלומר כולם מציגים את אותה התוצאה בו זמנית.
כפתור 0KEY משמש לביצוע Reset למערכת והוא גם משמש כטריגר וציר האפס בולידציה.

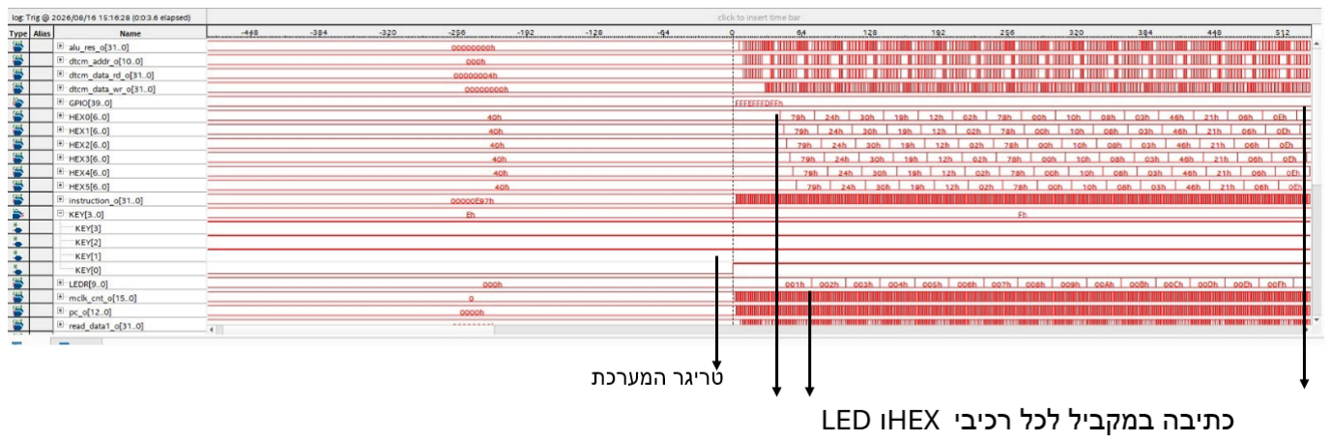
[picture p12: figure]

Figure 25: STP Validation of test0 GPIO

טסט :1
טסט זה בודק את פעולת ה־GPIO גם כקלט וגם כפלט. לפי מצב המתגים SW, התוכנית משנה את כיוון הספירה ומציגה את הערך על LEDR ועל 5HEX–0HEX. הטריגר לטסט זה היה שינוי במצב הSW כאשר 01x0=SW מתבצעת ספירה עולה ב־,1 כאשר 02x0=SW מתבצעת ספירה יורדת ב־,1 ובכל ערך אחר הספירה נעצרת והערך האחרון נשמר בתצוגות. 0KEY משמש ל־Reset של המערכת.

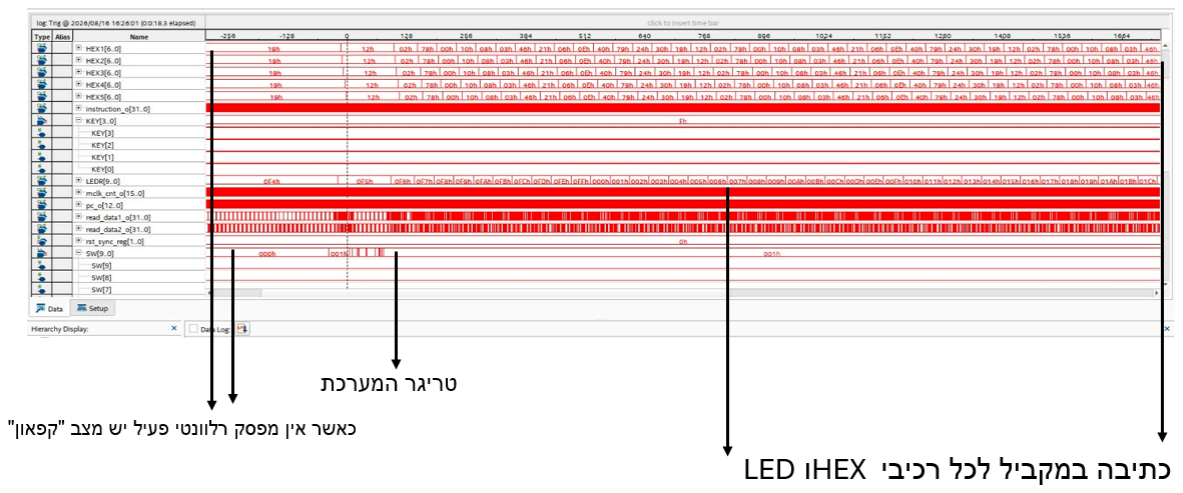
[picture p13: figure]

Figure 26: STP Validation of test1 GPIO

טסט :2
טסט זה בודק את פעולת הקלט והפלט של ה־GPIO באמצעות המתגים והתצוגות. כאשר 01x0=SW מתבצעת ספירה עולה ב־,1 וכאשר 02x0=SW מתבצעת ספירה יורדת ב־.1 ערך המונה מוצג כמספר בן שש ספרות על מערך 0HEX–5HEX ובמקביל גם על 7:0 LEDR. בכל ערך אחר של המתגים הספירה נעצרת והערך האחרון נשמר.
0KEY משמש ל־Reset של המערכת.

Figure 27: STP Validation of test2 GPIO

## חלק שלישי - פסיקות - Interrupts

מערכת הפסיקות מאפשרת להתקנים היקפיים לעצור באופן זמני את רצף הביצוע הרגיל של המעבד ולגרום למעבר ל־Routine Service Interrupt המתאים. במימוש שלנו קיימים ארבעה מקורות פסיקה: ה־Basic Timer ושלושת הלחצנים 3KEY–1KEY. כל מקור מחובר ל־Controller Interrupt, האחראי על שמירת בקשות פסיקה ממתינות, אפשור מקורות הפסיקה, קביעת סדרי עדיפויות ושליחת אות INTR למעבד.

Figure 28: Memory-Mapped I/O addresses of interrupt-capable peripherals
כלל רכיבי הפסיקה וה־Timer Basic ממופים למרחב ה־O/I Mapped-Memory של המעבד. הטבלה מציגה את כתובות הרגיסטרים וההתקנים הרלוונטיים, באמצעות מיפוי זה המעבד יכול לקרוא ולכתוב לרכיבי הבקרה באמצעות פקודות Store/Load רגילות. שורות ה־USART המופיעות בטבלה אינן בשימוש במימוש שלנו, מאחר שבחרנו שלא לממש את בונוס ה־UART.

:Interrupt Vector Table – IVT ה־ IVT הינה טבלה בזיכרון המכילה עבור כל מקור פסיקה את כתובת פונקציית השירות המתאימה )ISR). לכל מקור פסיקה מוגדר ערך TYPE קבוע, המשמש ככתובת הכניסה שלו בטבלת הווקטורים. לפי הגדרת הפרויקט, למקורות שבהם אנו משתמשים קיימים הערכים: 10x0 עבור ה־Timer Basic, 14x0 עבור 1KEY,
.KEY3 | עבור | 0x1Cו־ KEY2 | עבור | 0x18

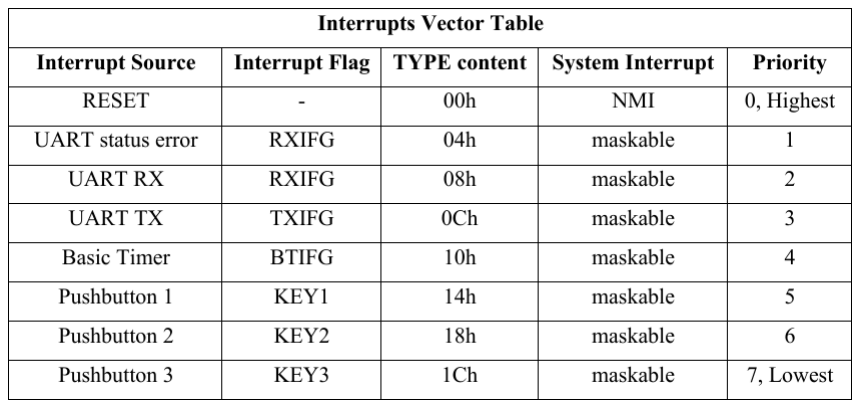
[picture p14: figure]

Figure 29: Interrupts Vector Table חשוב להדגיש כי ה־TYPE אינו כתובת ה־ISR עצמה. ה־TYPE מצביע לכניסה המתאימה ב־IVT, ובאותה כניסה שמורה כתובת ה־ISR:
TYPE = 0x10 → Mem[0x10] → Timer ISR address
TYPE = 0x14 → Mem[0x14] → KEY1 ISR address
TYPE = 0x18 → Mem[0x18] → KEY2 ISR address
TYPE = 0x1C → Mem[0x1C] → KEY3 ISR address
בעת קבלת פסיקה, ה־Controller Interrupt מעביר את ערך ה־TYPE למעבד דרך ה־DataBUS. הערך נשמר ברגיסטר פנימי q_type, ובמחזור הטיפול הבא הוא משמש ככתובת גישה ל־DTCM במקום הכתובת הרגילה שמגיעה מה־ALU. הערך שנקרא הוא כתובת ה־ISR, והוא משמש לביצוע הקפיצה של פונקציית השירות.

קבצי VHD המרכיבים את חלק ה-Interrupts:

InterruptController.vhd.1
מודול זה מממש את בקר הפסיקות )INTC )של המערכת. מטרתו לנהל באופן ריכוזי את בקשות הפסיקה החומרתיות, לסנן אותן, לתעדף אותן ולתקשר מול הליבה לייצור פסיקה מאוחדת )INTR). המודול כולל בתוכו מנגנון Detection Edge: המודול קולט דרישות חומרתיות משלושת לחצני המשתמש )1KEY 2,KEY 3,KEY )ומ-דגל הפסיקה של הטיימר הבסיסי )BTIFG). הלחצנים מזוהים ב-edge Falling, ואילו פסיקת הטיימר מזוהה ב -edge Rising. ניהול רגיסטרים וסינון חומרתי: אוגר ה-IE ממופה לכתובת C202x0 ואוגר ה-IFG לכתובת D202x.0 בהתאם להגדרות הארכיטקטורה המודול מבצע חסימה חומרתית בכתיבה כך שרק ביטים 5:2 ניתנים לעדכון מה-bus, בעוד שביטים 7:6 ו1:0- מקובעים ל-'0' )מיועדים לUART ). בנוסף, מיושם סינון המבטיח כי בקריאת האוגר יתקיים כי דגלי פסיקה ממתינים שאינם מאופשרים יוחזרו תמיד כ-'0'.

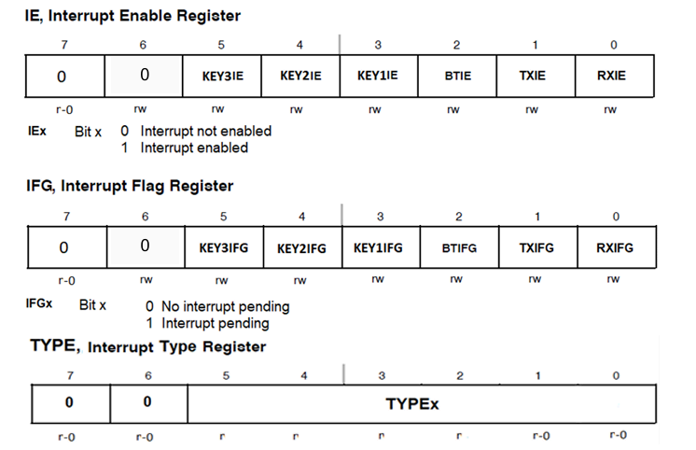
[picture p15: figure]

Figure 30: Interrupt Registers Structure

בהתאם לדרישות הפרויקט קובץ זה אחראי גם על יישום Encoder Priority: תהליך קומבינטורי הבוחן את הדגלים הפעילים לאחר הסינון וקובע את הפסיקה בעלת העדיפות הגבוהה ביותר להגשה )ניתן לראות את פירוט עדיפויות המלא ב29- Table). מבין הפסיקות שאינן NMI, פסיקת טיימר מוגדרת כעדיפות העליונה, ואחריה הלחצנים 1KEY עד 3KEY לפי סדר עולה. במידה וקיימת פסיקה פעילה, ובכפוף לאות האפשור הגלובלי המגיע מהליבה )GIE )שמגיע מהמעבד מועלה אות ה-INTR.

Figure 31: Hardware Logic for Handling Multiple Interrupt Sources

מענה לפסיקה )INTA )ושליטה על ערוץ הנתונים: פרוטוקול אישור הפסיקה נשלט באמצעות האות INTA. כאשר INTA יורד ל-'0', המודול נועל את וקטור סוג הפסיקה הפעיל אל אוגר q_type. במקביל, המודול משתלט על ה-DataBUS הדו-כיווני ודוחף את הוקטור למעבד, תוך עקיפת פעולת קריאת זיכרון סטנדרטית. איפוס אוטומטי: על מנת למנוע כניסה חוזרת לשגרת הISR, המודול דוגם את קו ה-INTA לזיהוי עליית מתח. ברגע סיום המעבר של INTA חזרה ל-'1', מתבצע איפוס חומרתי סינכרוני לדגל הפסיקה הספציפי.

Figure 32: CPU and INTC Handshake and Bus Connections

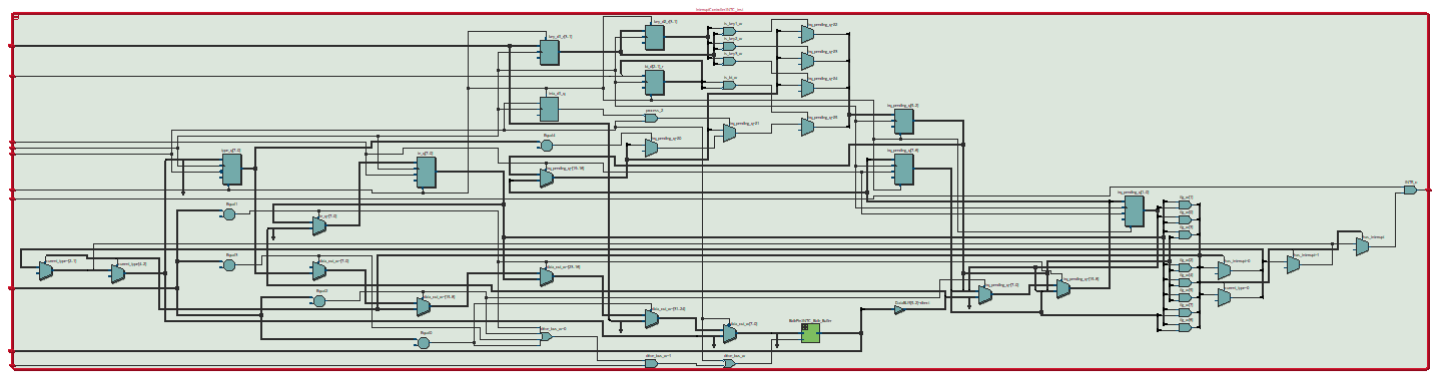
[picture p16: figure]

Figure 33: RTL Interrupt Controller Unit control.vhd.2
ה־FSM שנמצא ביחידת הבקרה מנהל את רצף הכניסה לפסיקה והמעבר ל־ISR. הוא כולל שלושה מצבים: .IntCycle2ו־ IntCycle1 ,Normal Normal: מצב העבודה הרגיל של המעבד. פסיקה מתקבלת כאשר 1 =INTR והמחלק אינו עסוק )0=DIVbusy). במקרה זה interrupt accept עולה, ה־PC נעצר, כתובת החזרה נשמרת וה־FSM עובר ל־1IntCycle.
1IntCycle: במצב זה INTA יורד ל־0 ובכך מאותת ל־Controller Interrupt שהפסיקה התקבלה. במקביל ClearGIE מאפס את GIE כדי למנוע קבלת פסיקות נוספות, וה־Controller Interrupt מציב את ערך ה־TYPE על ה־DataBUS, ממנו הוא נשמר ב־q_type. 2IntCycle: ערך ה־TYPE משמש לגישה ל־Table Vector Interrupt. האות Addr Type Select בוחר את TYPE ככתובת ל־DTCM, והערך הנקרא מ־] TYPE[Mem הוא כתובת ה־ISR. במקביל WriteTP שומר את כתובת החזרה ב־4x, ו־IntJump מבצע את הקפיצה ל־ISR. לאחר מכן ה־FSM חוזר ל־Normal. בסיום ה־ISR מתבצעת הפקודה ) tp(0 0,x jalr. ה־CONTROL מזהה אותה כ־RETI, מפעיל SetGIE ומאפשר מחדש קבלת פסיקות, תוך חזרה לכתובת שנשמרה ב־tp לטובת המשך ריצת התוכנית המקורית במעבד.

Figure 34: Interrupt Handler FSM and Condition Table

BasicTimer.vhd.3
מודול ה־BasicTimer מממש טיימר -32bit המאפשר יצירת אירועים מחזוריים, פסיקות, אות PWM ולכידת ערך המונה בעקבות אירוע חיצוני )Capture). המודול נשלט באמצעות רגיסטרי בקרה הממופים למרחב ה־O/I Mapped-Memory, ולכן המעבד יכול להגדיר את אופן פעולת הטיימר ולקרוא את תוצאותיו באמצעות פקודות Store/Load. המודול מקבל שני קלטי Capture, 1CAPIN ו־2CAPIN, ומוציא את האותות BTIFG המהווה דגל פסיקה אל הController Interrupt ואות PWMout עבור יציאת ה־PWM.

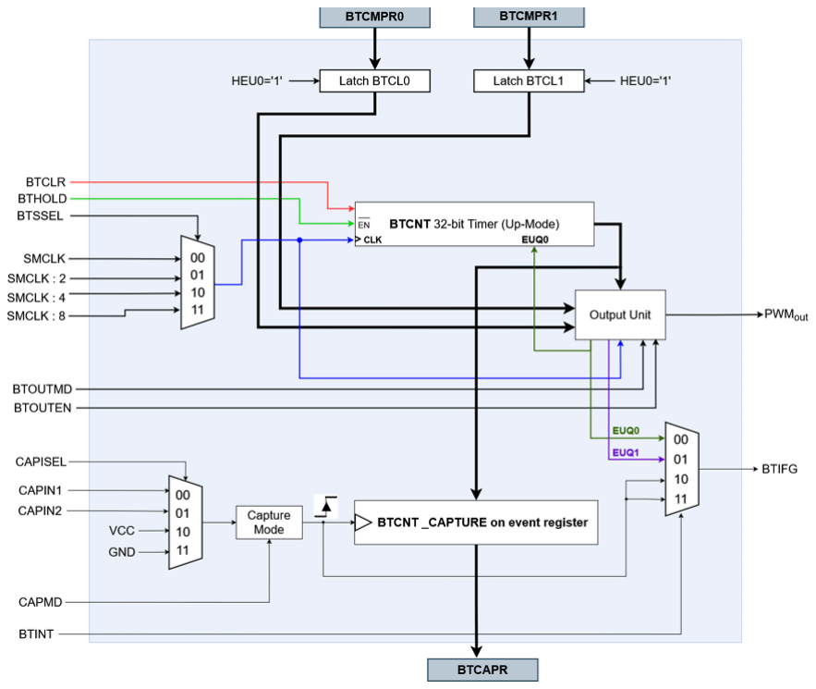
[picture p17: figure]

Figure 35: Basic Timer Functional Diagram

רגיסטרי ה־Timer Basic:
פעולת הטיימר נשלטת באמצעות מספר רגיסטרים. 1BTCTL ו־2BTCTL מכילים את ביטי הבקרה, 0BTCMPR ו־1BTCMPR מחזיקים ערכי Compare ו־BTCAPR שומר את ערך המונה שנלכד במצב Capture. בתוך המודול קיים גם המונה הפנימי BTCNT ושני רגיסטרים פנימיים 0BTCL ו־1BTCL, המשמשים כערכי ההשוואה בפועל.

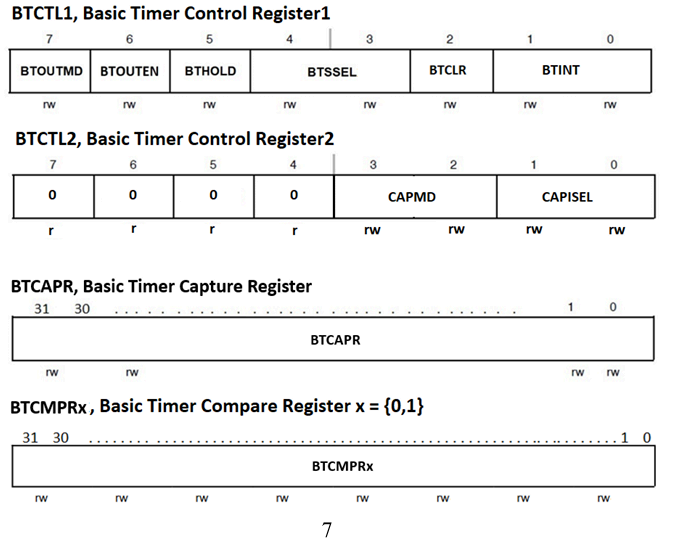
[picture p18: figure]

Figure 36: Bit-level Structure of the Basic Timer Registers

BTCNT הוא מונה -32bit המהווה את ליבת ה־Timer Basic. קצב ההתקדמות שלו נקבע על ידי השדה BTSSEL מתוך 1BTCTL. המודול כולל Prescaler המבצע מניה מחזורית מ־0 עד 7 ומאפשר לבחור בין
timer_tick | מתקבל | SMCLK | עבור | .SMCLK/8ו־ SMCLK/4 ,SMCLK/2 ,SMCLK : | ספירה | קצבי | ארבעה
בכל מחזור שעון, עבור /2SMCLK כאשר ביט ה־LSB של ה־Prescaler הוא ,1 עבור /4SMCLK כאשר שני ביטי ה־LSB הם ,11 ועבור /8SMCLK כאשר ערך המונה הוא .111 בנוסף, BTHOLD מאפשר לעצור את המונה ולשמור את ערכו הנוכחי, ו־BTCLR מאפס את BTCNT ומתאפס בעצמו לאחר ביצוע פעולת האיפוס.

ה־Timer Basic כולל שני רגיסטרי Compare: 0BTCMPR ו־1BTCMPR. הערכים הנכתבים אליהם מועברים לרגיסטרים פנימיים 0BTCL ו־1BTCL, המשמשים להשוואה מול BTCNT. במימוש שלנו ערכי ה־Compare נטענים ל־0/1BTCL כאשר המונה נמצא בערך אפס או לאחר פעולת BTCLR. כאשר BTCNT מגיע לערך ההשוואה המתאים, נוצר אירוע Compare. שני אירועים אלו, 0Compare ו־1Compare, יכולים לשמש הן ליצירת פסיקת Timer והן כחלק ממנגנון יצירת ה־PWM. כאשר מצב Capture אינו פעיל ו־0BTCL מוגדר, 0BTCMPR משמש גם להגדרת מחזור הספירה: לאחר שהמונה מגיע לסוף המחזור הוא חוזר ל־0 ומתחיל מחזור חדש.

יצירת פסיקת :השדה BTINT בתוך 1BTCTL קובע איזה אירוע של הטיימר ייצר את אות הפסיקה BTIFG. ניתן לבחור בין אירוע Compare של 0BTCMPR, אירוע Compare של 1BTCMPR או אירוע Capture. כאשר האירוע שנבחר מתרחש, המודול מייצר פולס BTIFG. פולס זה מועבר ל־Controller Interrupt, אשר שומר אותו כבקשת פסיקה ממתינה ומטפל בו בהתאם לערכי IE, GIE וסדר העדיפויות.

:PWM – Output Compare Mode אחד מתפקידי ה־Timer Basic הוא יצירת אות PWM. במצב זה 0BTCMPR מגדיר את מחזור הספירה, בעוד 1BTCMPR קובע את נקודת שינוי רמת המוצא בתוך המחזור. כך שינוי היחס בין שני ערכי ה־Compare מאפשר לשלוט ב־Cycle Duty של אות ה־PWM. לפי דרישות הפרויקט, השדה BTOUTMD בוחר בין שני מצבי יציאה, ו־BTOUTEN קובע האם ערך PWMout מתעדכן. במימוש קיימים שני מצבים הנקבעים לפי הערכים 1BTCL 0,BTCL:

Figure 37: PWM Signal Generation using Output Compare Mode

:Capture Mode
מצב Capture מאפשר לשמור את ערך BTCNT בדיוק בזמן שמתרחש אירוע חיצוני. השדה CAPISEL מתוך 2BTCTL בוחר את מקור האירוע: 1CAPIN, 2CAPIN, קבוע '1' או קבוע '0'. השדה CAPMD קובע האם לזהות Edge Falling או Edge Rising או Disable עבור מצב ה־Capture. במימוש הקלט הנבחר נדגם באמצעות שני רגיסטרים עוקבים, ועל סמך הערך הנוכחי והקודם מזוהה החזית. כאשר מזוהה האירוע שנבחר, הערך הנוכחי של BTCNT נשמר בתוך BTCAPR. BTINT מוגדר לבחור ב־Capture כמקור הפסיקה, אותו אירוע גם גורם ליצירת BTIFG, ולכן ניתן להפעיל ISR בעקבות אירוע ה־Capture.

ה־Timer Basic מחובר ל־DataBUS המשותף באמצעות ממשק דו־כיווני. בזמן כתיבה המעבד מעדכן את רגיסטרי הבקרה או ה־Compare בהתאם לכתובת שנבחרה. בזמן קריאה, המודל מחזיר את תוכן הרגיסטר המבוקש ורק כאשר read mem פעיל והכתובת שייכת ל־Timer Basic הוא מקבל הרשאה להניע את ה־DataBUS. בכך נמנע Contention Bus מול שאר רכיבי ה־MMIO.

Figure 38:RTL Basic Timer Unit

ולדיציה עבור רכיבי הInterrupt:
על מנת לבדוק שרכיב ה Interrupt פועלים ומגיבים בהתאם לתוכנית ביצענו בדיקות לפי ארבעת הטסטים. שקיבלנו.
טסט :1
טסט זה בודק ביצוע פעולות מתמטיות על מערכים. בלחיצה על 1KEY מוצג איבר ממערך 1 על 0-1 HEX, בלחיצה על 2KEY מוצג איבר ממערך 2 על 2-3 HEX, ובלחיצה על 3KEY מתבצעת ריצה מחזורית המציגה את איברי המערכים ואת תוצאת החילוק )מנה ושארית( ביניהם כך שהתוצאה על 4-5 HEX והשארית מוצגת על שמונת הלדים הימניים בערכה באמצעות בקידוד בינארי.

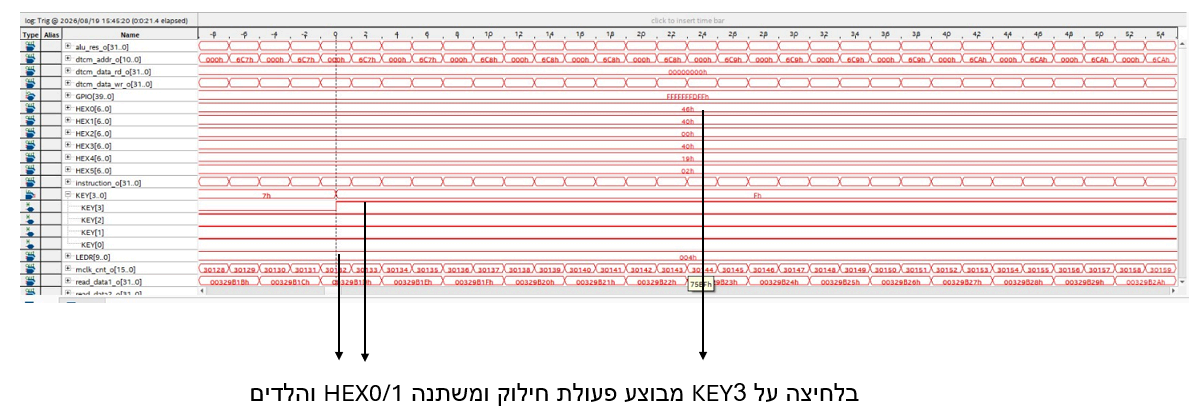
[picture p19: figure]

Figure 39: Signal Tap Validation for Test1

טסט :2
טסט זה בודק פסיקות טיימר קבועות המקדמות מונה כל שנייה. בלחיצה על 1KEY המונה מוצג על צמד ה-HEX הראשון, בלחיצה על 2KEY הוא מוצג על הצמד השני, ובלחיצה על 3KEY על הצמד השלישי.

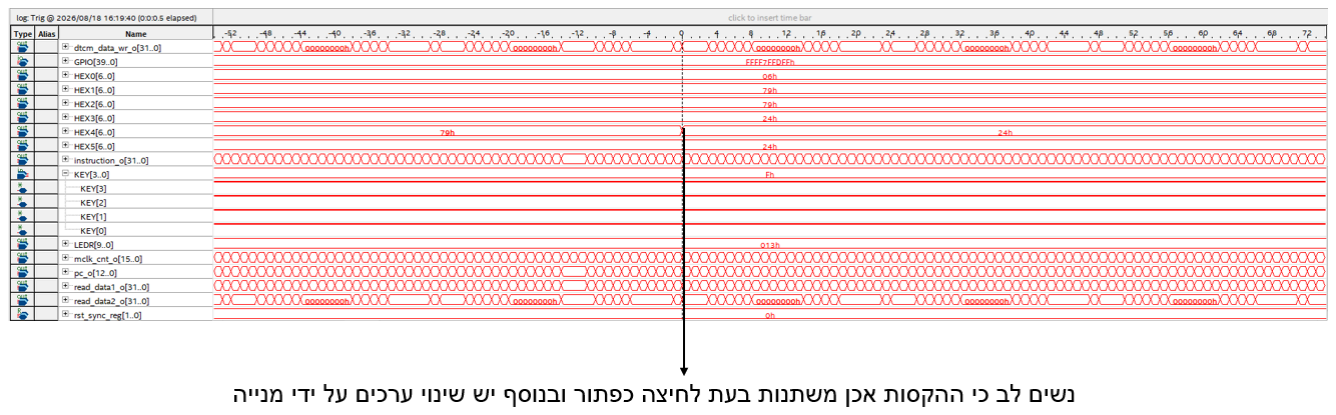
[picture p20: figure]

Figure 40: Signal Tap Validation for Test2

טסט :3
טסט זה בודק שינוי דינמי של תדר פסיקות הטיימר. בלחיצה על 1KEY קצב הפסיקות משתנה ל0.5- שניות, בלחיצה על 2KEY קצב הפסיקות משתנה ל0.25- שניות, ובלחיצה על 3KEY ל0.125- שניות )בכל לחיצה המונה גם מוצג במיקום שונה(.

Figure 41: Signal Tap Validation for Test3

טסט :4
טסט 4 בודק מצבי עבודה שונים ומתקדמים של הטיימר: בלחיצה על 1KEY כל לחיצה מעדכנת ברצף את מרווח הזמן בין פעימות התקדמות המונה)1 שנייה, ,0.5 ,0.25 ו0.125- שניות(. המונה מתקדם ב1- כל הזמן ומוצג על גבי 0-1 HEX. דוגמה ללחיצה על 1KEY וקצב הספירה קטן פי 2

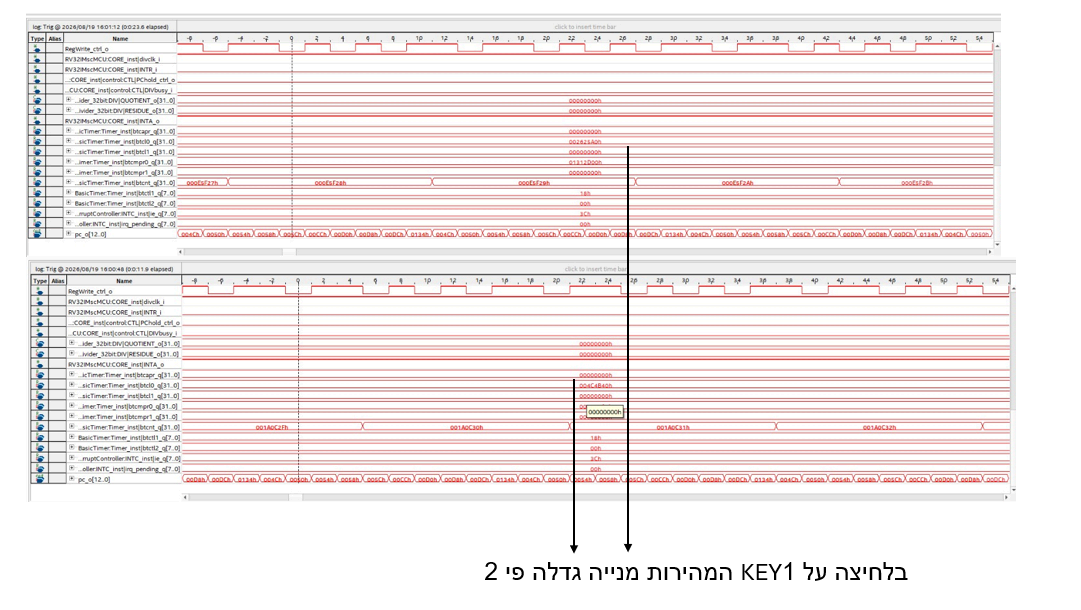
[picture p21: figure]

Figure 42: Signal Tap Validation for Test4 Key1

בלחיצה על 2KEY( מצב יצירת PWM): הטיימר מוגדר למצב השוואה המפיק אות PWM בתדר קבוע של kHz.5 כל לחיצה משנה ברצף את מחזור העבודה )Cycle Duty )של האות בין הערכים: ,50% ,75% ,87.5% ו.93.75%-

דוגמה ללחיצה על 2 KEY בתוכנת הMODELSIM

Figure 43: WaveForm Verification for Test4 Key2 כעת נראה את 4 מצבי הDutyCycle אשר בדקנו במעבדה:

Figure 44:Duty Cycle Verification performed with Oscilloscope

בלחיצה על 3KEY הטיימר מוגדר למצב לכידה למטרת מדידת זמני ריצה של קוד. לחיצות זוגיות מודדות את הזמן שלוקח לבצע פעולת חילוק )Division )בין שני מערכים איבר-באיבר, ולחיצות אי-זוגיות מודדות את הזמן שלוקחת פעולת שארית )Modulo )בין המערכים. בנוסף כמובן אנחנו כותבים את תוצאות הפעולות למערכי הפלט בזיכרון.

Figure 45:ISMCE Verification of Test4 Key3

## חלק רביעי - הטמעת המערכת בכרטיס 10DE FPGA

בשלב זה, לאחר תיאור המודולים המרכזיים המרכיבים את המערכת, ניתן לבחון את אופן שילובם במימוש המלא על גבי ה־FPGA. כלל רכיבי ה־MCU, ובהם ליבת ה־IM32RV, הזיכרונות, רכיבי ה־GPIO, מערכת הפסיקות, ה־Timer Basic ומאיץ המחלק, מחוברים יחד למערכת אחת באמצעות אותות בקרה, Address Bus ו־DataBUS משותף. בנוסף, המימוש כולל מערכת שעונים המפיצה שעונים נפרדים לרכיבי המערכת וחיבור ישיר למשאבי הקלט והפלט הפיזיים של לוח ה־FPGA.

קבצי VHD המרכיבים את המערכת :

FPGA_Top_SingleCycle.vhd.1 מודול ה־Level Top של המערכת ואחראי על שילוב כלל הרכיבים לכדי מערכת אחת הממומשת על גבי לוח ה־FPGA. המודול מבצע Instantiation של ליבת IMscMCU32RV, רכיב ה־GPIO, ה־Interrupt Controller, ה־Timer Basic ורכיבי ה־PLL, ומחבר ביניהם באמצעות אותות הכתובת, אותות MemWrite/MemRead, אותות הפסיקה וה־DataBUS המשותף. בנוסף, המודול מהווה את שכבת החיבור בין המערכת הלוגית לבין רכיבי הלוח הפיזיים. הקלטים SW ו־KEY מחוברים לרכיבי הקלט המתאימים, בעוד LEDR ו־5HEX–0HEX משמשים להצגת תוצאות. קווי GPIO משמשים בין היתר עבור כניסות ה־Capture של ה־Timer Basic ועבור יציאת אות ה־PWM.

נציין כי השתמשנו במנגון אשר מסנכרן את ה Reset לשעון.בעת הפעלת הלוח המערכת נשארת ב־Reset עד ללחיצה הראשונה על 0KEY, ובכך ניתן זמן להתייצבות מערכת השעונים. לאחר מכן, כל לחיצה על
.rst_req_w אות | את | יוצרת | KEY0
מכיוון ש־0KEY הוא קלט אסינכרוני, w_req_rst מועבר דרך שני Flops-Flip עוקבים )reg_sync_rst) המסונכרנים ל־50_CLOCK. המוצא w_rst מתקבל מהשלב השני ומשמש כ־Reset המשותף לרכיבי המערכת. כך שחרור ה־Reset מתבצע בצורה מסונכרנת ומפחית את הסיכון ל־Metastability.

Figure 46: RTL Schematic of the Top-Level FPGA Module

PLL.vhd.2
משמש ליצירת שעוני העבודה של המערכת מתוך שעון הכניסה 50_CLOCK. תדר המוצא נקבע באמצעות הפרמטרים MUL_PLL_G ו־DIV_PLL_G. את ערכי הפרמטרים קבענו כך שתדר העבודה יהיה גבוה ככל האפשר תוך עמידה בדרישות התזמון של המערכת. לצורך כך בוצע Analysis Timing ב־Quartus ונבחן ה־Slack Setup Case-Worst. כל עוד ה־Slack חיובי המערכת עומדת בדרישות התזמון, כאשר ערך חיובי הקרוב ל־0 מצביע על עבודה בסמוך לגבול התדר של המימוש. ב־SingleCycle_Top_FPGA נעשה שימוש בשלושה מופעים של רכיב ה־PLL, היוצרים שלושה מסלולי שעון: MCLK עבור ליבת המעבד, SMCLK עבור ההתקנים ההיקפיים ו־DIVCLK עבור יחידת החילוק.

Figure 47: RTL Schematic of the System PLL Module

## חלק חמישי - ניתוח ביצועים

AREA:
| Logic Elements | Registers | I/O pins | Embedd ed Memory bits | Embedded 9-bit Multipliers | PLL’s
MCU with GPIO | 1696 | 1691 | 107 | 131,072 | 3 | 1
MCU with GPIO and Interrrupt Capability | 2169 | 2059 | 107 | 131,072 | 3 | 1

PERFORMENCE:

| F max | Critical Path | F mclk
MCU with GPIO | mclk:29.29 MHz accclk: 179.6 MHz | ITCM → Decode/Execute logic → DTCM | 29.29 MHz
MCU with GPIO and Interrrupt Capability | mclk:26.96 MHz accclk: 169.72 MHz | ITCM → Decode/Control → Execute (Multiplier/ALU) → Timer → Interrupt Controller → Data Bus → DTCM | 26.96 MHz

POWER:

| Total power consumption | Static power consumption | Dynamic power consumption | I/O power consumption
MCU with GPIO | 442.68 mW | 415.28 mW | 13.77 mW | 13.63 mW
MCU with GPIO and Interrrupt Capability | 442.81 mW | 415.28 mW | 13.92 mW | 13.62 mW

כעת נצרף תמונות מתוכנת הQuartus המוכיחות נתונים אלו:

Figure 48: Area report MCU with Interrupt

Figure 49: Area report MCU without Interrupt

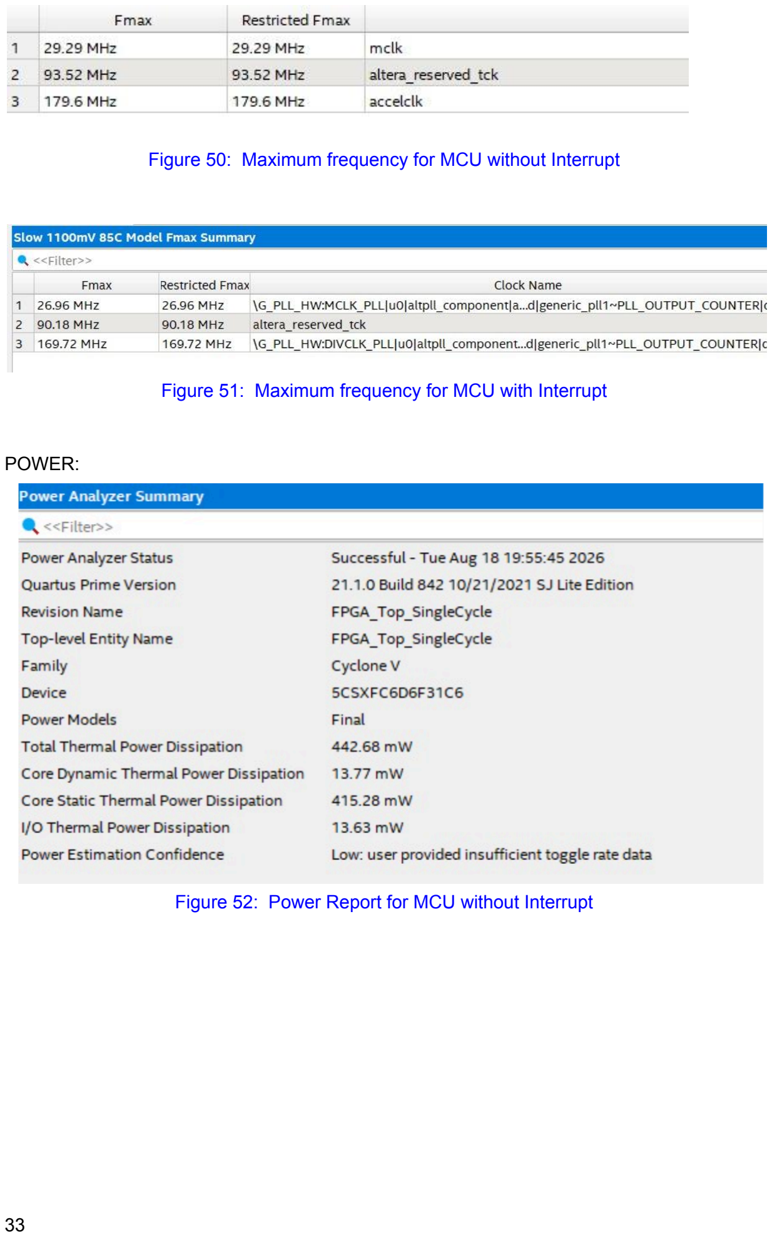
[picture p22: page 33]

Figure 50: Maximum frequency for MCU without Interrupt

Figure 51: Maximum frequency for MCU with Interrupt

POWER:

Figure 52: Power Report for MCU without Interrupt

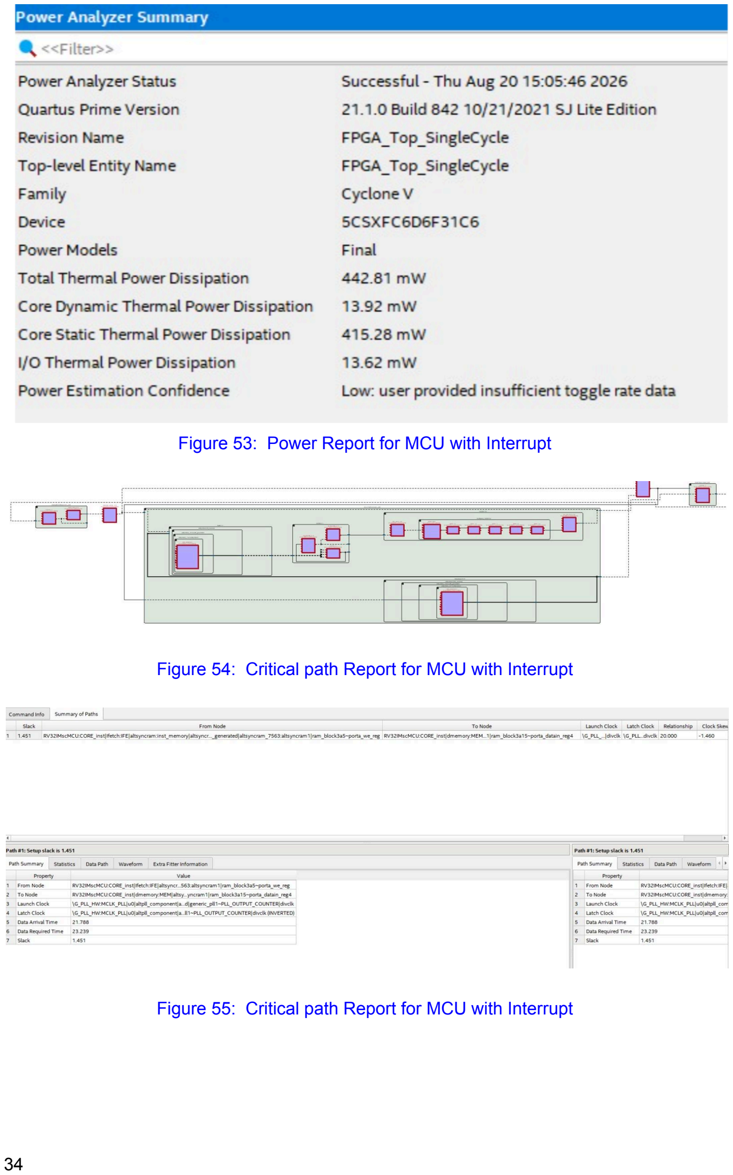
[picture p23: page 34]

Figure 53: Power Report for MCU with Interrupt

Figure 54: Critical path Report for MCU with Interrupt

Figure 55: Critical path Report for MCU with Interrupt

Figure 56: Critical path Report for MCU without Interrupt

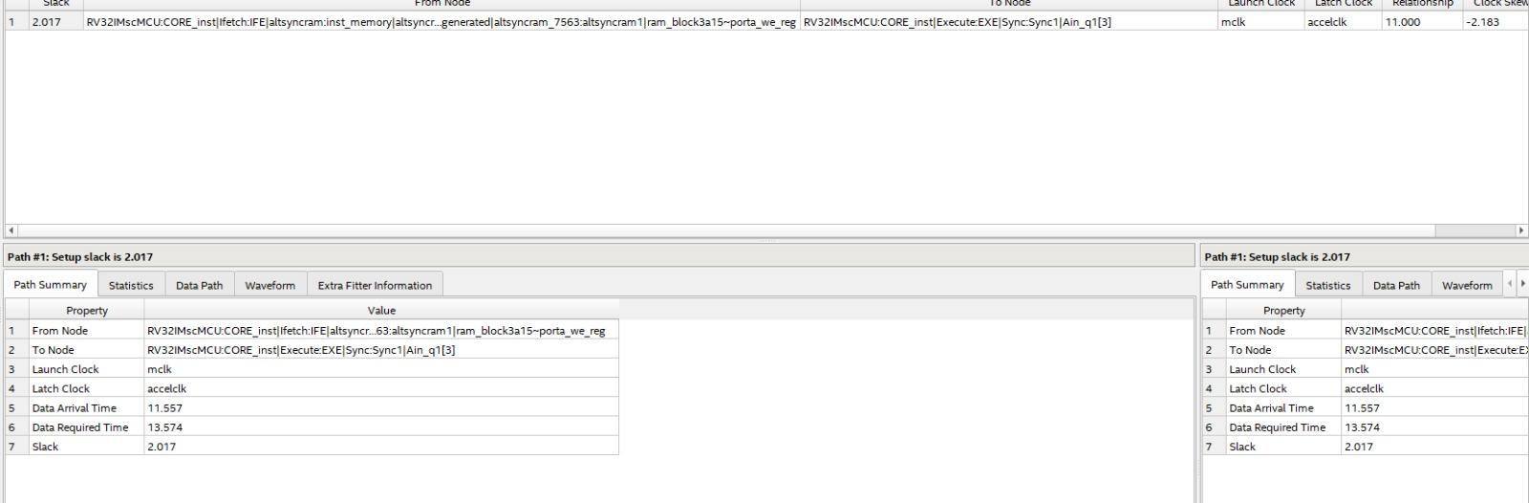
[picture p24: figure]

Figure 57: Critical path Report for MCU without Interrupt

סיכום ביצועים וניתוח השוואתי )Analysis Timing & Performance) הוספת מנגנון הפסיקות )Capability Interrupt )והטיימר למערכת מציגה off-Trade הנדסי בין הרחבת הפונקציונליות לבין ביצועי התזמון, ניצול המשאבים וצריכת ההספק. שילוב התמיכה בפסיקות הוביל לירידה של כ־8% בתדר השעון המקסימלי של ה־MCLK, מ־29.29 MHz ל־26.96 MHz. ניתוח ה־Path Critical ב־TimeQuest מראה כי בגרסה התומכת בפסיקות הנתיב הקריטי עובר דרך שרשרת קומבינטורית ארוכה הכוללת Execute → Control/Decode → ITCM
הלוגיקה | שלבי | ריבוי | .)ALU/Multiplier) → Timer → Interrupt Controller → Data Bus → DTCM
וה־routing לאורך מסלול זה מגדיל את ה־Delay Propagation ולכן מגביל את תדר העבודה המקסימלי. בנוסף, התמיכה בפסיקות ובטיימר הגדילה את ניצול המשאבים ב־473 Elements Logic וב־368 Registers, כתוצאה מהוספת בקר הפסיקות, הטיימר ולוגיקת הבקרה וה־Bus Data הנלווית. בהתאם, נרשמה עלייה קלה בהספק הדינמי מ־13.77 mW ל־13.92 mW, בעוד שההספק הסטטי נותר ללא שינוי בדוח Quartus.

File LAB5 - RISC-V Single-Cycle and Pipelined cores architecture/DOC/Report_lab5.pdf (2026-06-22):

## PREPARATION REPORT LAB5

## ADVANCED CPU ARCHITECTURE AND HARDWARE

## ACCELERATORS LAB

361.1.4693

## Yoav Tsur 211903406 Elad Lavi 211626551

## 2026 Semester B

## תוכן עניינים

חלק ראשון - מעבד הסינגל סייקל 3 ולידציה עבור מעבד IM32RV סינגל סייקל: 5 בדיקת ביצועים עבור מעבד הסינגל סייקל :IM32RV 10 בדיקת ביצועים - סינגלטאפ: 12 חלק שני - מעבד הפייפליין: 13 ולידציה עבור מעבד IM32RV פייפליין: 15 בדיקת ביצועים עבור מעבד הפייפליין :IM32RV 17 בדיקת ביצועים עבור מעבד הפייפליין - סיגנלטאפ: 20

## חלק ראשון - מעבד הסינגל סייקל

בחלק הראשון של מטלה הרחבנו את מעבד הסינגל סייקל הנתון בתמונה הבאה:

figure 1: basic RV32I Single-Cycle uArchitecture זהו מעבד מארכיטקטורת I32 RV-RISCV. בשלב הראשון ביצענו הרחבות על מנת לתמוך בארכיטקטורת מעבד IM32RV הכולל הוספה של פעולת כפל בשלב הEXECUTE וקווי בקרה נוספים ליחידת הבקרה, עפי שמתואר בתמונה הבאה )המעבד סינגל סייקל המורחב(:

figure 2: basic RV32IM Single-Cycle uArchitecture

הוספת יחידת הכפל בוצעה לפי סדר הפעולות הבא, כאשר 1 STAGE וגם 2 STAGE מבוצעים באותו המודול. ניתן לראות את מימוש פעולת ההכפלה בין A לבין B כאשר כל אחד מהם 16 ביט אל רגיסטר 32 ביט בשם RESULT. מצורף החישוב בתמונה הבאה:


figure 3: Multiplication process A*B=RESULT

הארכיטקטורה כשלעצמה מורכבת מחמשת השלבים לביצוע פקודה: ,EXECUTE ,DECODE ,FETCH WB ,MEM. בסינגל סייקל כל פקודה עוברת את כל השרשרת במחזור אחד ולכן 1= CPI =IPC לכל הוראה, ובנוסף אנחנו לא נתקלים במצבי תלות כתוצאה מכך שהמעבד מטפל רק בפקודה אחת בכל עת ולכן אנחנו חוסכים בחומרה. מצד שני הדבר כמובן גורר מסלול קריטי ארוך וכתוצאה מכך תדר השעון יהיה קטן יותר בהשוואה למעבד בעל ארכיטקטורת פייפליין. הממשק לFPGA מתבצע על ידי חיבור של סוויץ' 0 כRST למערכת ושימוש בPLL על מנת לייצר שעון בתדר 25 מגה-הרץ. כפי שמתואר בתמונה הבאה:


figure 4: FPGA User Interface

## ולידציה עבור מעבד IM32RV סינגל סייקל:

על מנת לבדוק את ביצועי המעבד נעבוד עם סימולטור RARS המקמפל ומריץ את התוכנית להפקת דוח ביצועים אל מול השוואה בתוכנת MODELSIM ע"י הרצת TESTBENCH אל מול הפעלה אמיתית על ערכת הFPGA. ביצענו 4 תוכניות לבדיקה שכללה שני מרכיבים: הראשון - התוכן של הזיכרון לאחר ההרצה תוך שימוש בTEXTDIFF. השני - בדיקת הביצועים ע"י השוואת IPC שבחלק הסינגלסייקל נצפה שיצא .1

figure 5: IPC Computation formula עבורנו CPI תמיד יהיה 1 כיוון שבמעבד סינגלסייקל מהגדרתו כל פקודה מבוצעת במחזור שעון בודד. נתחיל בניתוח התוצאות:

TEST1:
דוח ביצועי הRARS:


figure 6: RARS Report for test1 הרצת התוכנית הראשונה לוקחת 133 הוראות. נצרף תיעוד מהמודלסים:


figure 7: ModelSim Report for test1 singlecycle


נשים לב כי התוכנית מסתיימת בכתובת 00000063 ומונה מחזורי השעון גם מצביע על 134 וזאת כי המחזור הראשון הוא עבור אתחול - לכן סך כל הריצה הוא 133 מחזורי שעון. נצרף את התמונה המראה כי התוכנית מסתיימת בהוראה זו:

figure 8: RARS Report for Instruction test1 נשים לב כי הפקודה 00000063 היא בדיוק פקודת הסיום של התוכנית ולכן וידאנו כי התוצאה נכונה. השוואת תוכן:

figure 9: RARS VS ModelSim test1 singlecycle ניתן לראות כי בחלק הזיכרון הרלוונטי ישנה התאמה מוחלטת. TEST2:
בצורה זהה לחלוטין נציג את תוצאות 2TEST:

figure 10: RARS Report for test2


נשים לב כי תוכנית זו דרשה הרצה של 1513 הוראות נצרף את התמונה מהמודלסים:

figure 11: ModelSim Report for test2 singlecycle נשים לב כי גם כאן יצא 1514 מחזורי שעון )1 יותר מהRARS בשל האתחול( כך שהתוצאה תקינה.

figure 12: RARS Report for Instruction test2 ניתן לראות כי התוכנית כמובן מסתיימת בפקודה .00000063 השוואת תוכן: ניתן לראות כי קיימת התאמה מלאה.

figure 13: RARS VS ModelSim test2 singlecycle

TEST3:

בצורה זהה לחלוטין נציג את תוצאות 3TEST:


figure 14: RARS Report for test3 נשים לב כי תוכנית זו דרשה הרצה של 2724 הוראות. נצרף את התמונה מהמודלסים:


figure 15: ModelSim Report for test3 singlecycle נשים לב כי גם כאן יצא 2725 מחזורי שעון )1 יותר מהRARS בשל האתחול( כך שהתוצאה תקינה. ניתן לראות כי התוכנית כמובן מסתיימת בפקודה .00000063 השוואת תוכן: ניתן לראות כי קיימת התאמה מלאה.


figure 16: RARS VS ModelSim test3 singlecycle

TEST4:
בצורה זהה לחלוטין נציג את תוצאות 4TEST:


figure 17: RARS Report for test4 נשים לב כי תוכנית זו דרשה הרצה של 2739 הוראות. נצרף את התמונה מהמודלסים:


figure 18: ModelSim Report for test4 singlecycle נשים לב כי גם כאן יצא 2740 מחזורי שעון )1 יותר מהRARS בשל האתחול( כך שהתוצאה תקינה. ניתן לראות כי התוכנית כמובן מסתיימת בפקודה .00000063 השוואת תוכן: ניתן לראות כי קיימת התאמה מלאה.


figure 19: RARS VS ModelSim test4 singlecycle

## בדיקת ביצועים עבור מעבד הסינגל סייקל IM32RV:

ראשית נציג את הRTL של המעבד:

figure 20: RV32IM singlecycle RTL

ניתן לראות לפי דיאגרמת הRTL כיצד המעבד מבצע שימוש ביחידות הביצוע כמפורט בתחילת הדוח. נציג את הבלוק שהוספנו למעבד - המכפל:

figure 21: RV32IM singlecycle MUL unit
כעת נציג את הדוחות מהQUARTUS עבור נתוני הPPA של מעבד הסינגלסייקל:

figure 22: RV32IM Power report singlecycle


figure 23: RV32IM singlecycle Area report

figure 24: RV32IM singlecycle Performance report ניתן לראות כי יצא תדר מקסימלי של 25.25 מגה-הרץ.

## בדיקת ביצועים - סינגלטאפ:


נראה את ההשוואה באמצעות ISMCE עבור 4TEST:

figure 28: QUARTUS VS RARS test4 singlecycle ניתן לראות כי קייימת התאמה מלאה.

figure 29: SIGNAL TAP on Test 4 singlecycle ניתן לראות כי המונה של השעון נעצר ב4AB0 בהקסאדצימלי שזה 2740 בדצימלי - לכן קיימת התאמה מלאה לRARS.

## חלק שני - מעבד הפייפליין:

בחלק זה של המשימה נרחיב את מעבד הסינגלסייקל מהחלק הראשון לארכיטקטורת פייפליין, מצורף השרטוט המראה את המעבד המיועד:


figure 30: Pipeline RV32IM Architecture כפי שניתן לראות הוא מורכב יותר ממעבד הסינגלסייקל. אופן הפעולה שלו עובד כך שיש לנו את חמשת החלקים שאינם פועלים סנכרונית )למעט הזיכרון והרגיסטרפייל שפועלים בירידת שעון על מנת למקסם יעילות וCPI )ובנוסף ישנם ארבעה חוצצים - רגיסטרים המשמשים חוצצים בין חלקים שונים בעיבוד הפעולה - כך שנשאף למקסם את השימוש בהם בכך שנרצה להכניס בכל מחזור הוראה חדשה כך שכאשר הפייפליין מלא המעבד יעבוד על 5 פקודות בו זמנית. היתרון העצום של מעבד זה הוא שנוכל לעבוד בצורה מקבילית על מספר הוראות בו זמנית מה שגורם לשיפור בתדר של השעון - אם בסינגלסייקל עלינו לחכות עד שכל השלבים יבוצעו ורק לאחר מכן נתחיל הוראה חדשה, כעת התדר נקבע על פי המסלול הקריטי של החלק בביצוע הפקודה הארוך ביותר. החסרון של מעבד זה הוא תוספת חומרה ובקרה - בין עם על ידי הוספת החוצצים ובין על ידי טיפול בHAZARDS.
בעוד שבמעבד סינגל סייקל תמיד 1= IPC, במעבד פייפליין המצב שונה כיוון שלפעמים ישנם מצבי תלות המאלצים אותנו עלינו לטפל בהם על מנת להוציא תוצאות נכונות. במעבד הפייפליין הנ"ל התמודדות עם מצבי התלות בוצעה על ידי מספר מנגנונים: מנגנון FORWARDING - העברת נתון מפקודה מוקדמת לפקודה מאוחרת וזאת עוד לפני כתיבה לזיכרון -כאשר מתאפשר הדבר מתבצע ללא שריפת מחזורי שעון. דוגמה לכך היא מצב שבו אנחנו רוצים לכתוב לרגיסטר מסוים ערך כלשהו והפקודה הבאה רוצה להשתמש בערך של אותו רגיסטר אך הנתון אינו הגיע לזיכרון ולכן מבוצע המעקף.
מנגנון STALL - כאשר ישנה פקודת LOAD כלומר אנחנו רוצים לקרוא מהזיכרון )מבוצע בשלב הרביעי( ופקודה אחריה רוצה להשתמש בנתון הזה, לא נוכל לבצע את המעקף כיוון שיקח סייקל נוסף עד שהערך יהיה מוכן עבור הפקודה החדשה. לכן במקרה כזה נעשה STALL בכך שנעקב את הפקודה הנמצאת ברגיסטר IF ובID ע"י הזרקת אפסים לשלב הEXECUTE הגורמת לביצוע פעולת NOP, בעוד ערכי הרגיסטרים הקודמים נשמרים.

מנגנון FLUSH - מתבצע כאשר קפיצה נלקחת. אם מתברר שפקודת הסתעפות נלקחת עלינו לבטל את הפקודות הקודמות. בארכיטקטורה של מעבד זה העונש עבור חיזוי שגוי הוא 3 מחזורי שעון וזאת כיוון שאנו מגלים את תוצאת ההסתעפות רק בשלב הרביעי - ולכן יש למחוק את שלושת השלבים הקודמים. מצבים אלה גורמים לכך שIPC במעבד פייפליין יהיה נמוך מ.1 ככל שנתקרב ל1 )חסם עליון וזאת אם אין HAZADRS )אזי התכנון של התוכנית ושל הארכיטקטורה שבנינו תהיה טובה יותר.

חישוב הIPC מתבצע ע"י הנוסחה באיור .5 כאשר ההסבר לכך הוא שיש להוריד: 4 עבור מילוי הפייפליין )הפקודה הראשונה תסתיים רק במחזור 5(, מספר הפעמים שבהם היה STALL( שריפת מחזור שעון אחד( ומספר הפעמים בהם היה FLUSH כפול 3 )3= DEPTH).

לצורך בדיקת ההרצה על הערכה דרך הסיגנלטאפ הוגדר הטריגר הבא:

figure 31: SIGNAL TAP trigger

הכתובת שמכניסים היא 8 הביטים העליונים של רגיסטר ההוראה )בעל 10 ביטים( כיוון שפקודות באורך 32 ביט לכן הקפיצות בן ב4 בייטים )גודל מילה(. להלן איור המראה את הממשק לFPGA:


figure 32: FPGA Interface for pipelined RV32IM הממשק למשתמש כולל 8 סוויצ'ים הקובעים את 8 הביטים שישמשו כטריגר עבור הגעת לכתובת הנכונה, 0KEY המשמש כRST המומש בצורה סינכרונית בהתאם להנחיות המעבדה, ושעון מובנה שעבר דרך PLL עבור הזנת המערכת הסינכרונית. המוצאים הם מונה מחזורי השעון וערך הרגיסטרים לפני ואחרי עליית השעון עבור כל שלב של הפקודה. בנוסף מונה STALL ומונה FLUSH, וסינגל טריגר העולה ל1 כאשר סיימנו את התוכנית.

## ולידציה עבור מעבד IM32RV פייפליין:

על מנת לבדוק את נכונות הארכיטקטורה נעבוד עם סימולטור RARS המקמפל ומריץ את התוכנית להפקת דוח ביצועים אל מול השוואה בתוכנת MODELSIM ע"י הרצת TESTBENCH אל מול הפעלה אמיתית על ערכת הFPGA. ביצענו 4 תוכניות לבדיקה שכללה שני מרכיבים: הראשון - התוכן של הזיכרון לאחר ההרצה תוך שימוש בTEXTDIFF. השני - בדיקת הביצועים ע"י השוואת הCOUNTER INSTRUCTION לחישוב הCLKCOUNTER פחות מחזורי השעון המבוזבזים כפי שפורט לעיל. התוכניות זהות לתוכנות עבור מעבד הסינגל סייקל ולכן דוח הסימולטור לא ישתנה. נזכיר כי עבור טסט 1 יצא כי התוכנית מונה 133 הוראות. להלן התוצאה מהMODELSIM עבור טסט :1


figure 33: Test1 for pipelined RV32IM נשים לב כי IFPC מגיע לכתובת הסיום במחזור 166 )6A00 בהקסה( כאשר היה על המעבד לבצע קפיצה מC007 ל0070 ולכן עליו לנקות באמצעות FLUSH( ניתן לראות כי עולה ל1 במחזור 166(. כפי שהוסבר לעיל ה"עונש" הוא 3 מחזורים ולכן נסיים ב169 מחזורים. חישוב: -169)4+8+8*3( = .133 כאשר מונה הFLUSH ומונה הSTALL שניהם שווים .8 להלן התוצאה מהMODELSIM עבור טסט 2 )הסימולטור כזכור 1513 הוראות(:


figure 34: Test2 for pipelined RV32IM נשים לב כי IFPC מגיע לכתובת הסיום במחזור 1914 כאשר היה על המעבד לבצע קפיצה מC007 ל0070 ולכן עליו לנקות באמצעות FLUSH( ניתן לראות כי עולה ל1 במחזור 1914(. כפי שהוסבר לעיל ה"עונש" הוא 3 מחזורים ולכן נסיים ב1917 מחזורים. חישוב: -1917)4+100+100*3( = .1513 כאשר מונה הFLUSH ומונה הSTALL שניהם שווים .100

להלן התוצאה מהMODELSIM עבור טסט 3 )הסימולטור כזכור 2724 הוראות(:


figure 35: Test3 for pipelined RV32IM נשים לב כי IFPC מגיע לכתובת הסיום במחזור 3619 כאשר היה על המעבד לבצע קפיצה לCC00 ולכן עליו לנקות באמצעות FLUSH( ניתן לראות כי עולה ל1 במחזור 1914(. כפי שהוסבר לעיל ה"עונש" הוא 3 מחזורים ולכן נסיים ב1917 מחזורים. חישוב: -3622)4+0+298*3( = .2724 כאשר מונה הFLUSH ושווה 298 ומונה STALL שווה ל.0 להלן התוצאה מהMODELSIM עבור טסט 4 )הסימולטור כזכור 2734 הוראות(:


figure 36: Test4 for pipelined RV32IM שים לב כי IFPC מגיע לכתובת הסיום במחזור 3643 כאשר היה על המעבד לבצע קפיצה לC004 ולכן עליו לנקות באמצעות FLUSH( ניתן לראות כי עולה ל1 במחזור 3643(. כפי שהוסבר לעיל ה"עונש" הוא 3 מחזורים ולכן נסיים ב3646 מחזורים. חישוב: -3639)4+0+303*3( = .2734 כאשר מונה הFLUSH ושווה 303 ומונה STALL שווה ל.0

## בדיקת ביצועים עבור מעבד הפייפליין IM32RV:


ראשית נציג את הRTL של מעבד הפייפליין:

figure 37: RV32IM pipeline RTL
ניתן לראות כי הוא משתמש במודולים של כל חמשת השלבים המחוברים זה לזה. נציג את דוח הAREA:

figure 38: RV32IM pipeline AREA summary כעת נציג את ביצועי הPERFORMANCE ונשים לב כי קבלנו תדר מקסימלי הגדול כמעט פי 3 לעומת מעבד הסינגל סייקל!

figure 39: RV32IM pipeline maximun frequency


נציג את הRTL של המערכת ממבט על:

figure 40: RV32IM pipeline FPGA RTL נשים לב כי דיאגרמת הRTL הזו מייצגת במדויק את הממשק של המשתמש אל מול ערכת הפיתוח העושה שימוש בתכנון המעבד, כמו כן ניתן לראות כיצד אות האיפוס החיצוני והאסינכרוני )הלחיצה על הכפתור( עובר תהליך של דגימה וסנכרון דו-שלבי לשעון המערכת הראשי. סנכרון זה מבטיח כי אות הריסט שיגיע לליבת המעבד יהיה סינכרוני לחלוטין.

נציג את דוח הPOWER:

figure 41: RV32IM pipeline power summary

SINGLECYCLE VS PIPELINE | ביצועים | השוואת

מצורפת טבלה המשווה בין ביצועי המעבדים )PPA):


figure 42: RV32IM pipeline VS singlecycle

שטח )Area): המעבר לפייפליין הגדיל את כמות הרכיבים הלוגיים ב3%- בלבד )מ1533- ל1579-( בשל הוספת יחידות הבקרה והמעקפים. מנגד, נרשם גידול של כ45%- בכמות הרשמים )מ1321- ל1924-( עקב הוספת 603 רשמי חוצץ )Registers Pipeline )הנחוצים להפרדת חמשת שלבי העיבוד.

ביצועים )Performance): התדר המקסימלי זינק פי .2.9 שיפור דרמטי זה נובע מקיצור המסלול הקריטי; במקום לעבור דרך כל המעבד במחזור יחיד, המסלול מוגבל כעת בין חוצץ לחוצץ, כאשר המסלול האיטי ביותר נקבע מעליית השעון באוגר WB/MEM ועד לכתיבה ב-File Register בירידת השעון.

הספק )Power): ההספק הסטטי נותר זהה כי הוא תלוי בסיליקון של ה-FPGA. לעומת זאת, ההספק הדינמי עלה ב31%- בשל תדר העבודה הגבוה יותר.

## בדיקת ביצועים עבור מעבד הפייפליין - סיגנלטאפ:

טסט :1

figure 43: SIGNAL TAP on Test1 pipeline ניתן לראות כי סיגנל הטריגר עולה ל1 כאשר מונה השעון מגיע ל169 מה שמתאים במדויק לבדיקה שהרצנו בMODELSIM עם אותו חישוב מול הRARS. טסט :2

figure 44: SIGNAL TAP on Test2 pipeline שוב רואים כי הטריגר עולה ב1913 באופן תואם. טסט :3

figure 45: SIGNAL TAP on Test3 pipeline ניתן לראות כי הטריגר עולה במקום במחזור .3622 טסט :4


figure 46: SIGNAL TAP on Test4 pipeline

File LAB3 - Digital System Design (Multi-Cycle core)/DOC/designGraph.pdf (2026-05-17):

# FSM Design Graph of the Control Unit:


- לריסט ניתן להגיע רק כאשר קו ריסט עולה ל.1
- מצב done_S מצב אינסופי, כאשר מגיעים אליו נשארים בו תמיד.

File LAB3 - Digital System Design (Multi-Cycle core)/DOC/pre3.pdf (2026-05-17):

## PREPARATION REPORT LAB3

## ADVANCED CPU ARCHITECTURE AND HARDWARE

## ACCELERATORS LAB

361.1.4693

## Yoav Tsur 211903406 Elad Lavi 211626551

## 2026 Semester B

## מבוא

במעבדה זו מימשנו מעבד רב־מחזורי בשפת VHDL, המבוסס על הפרדה בין יחידת בקרה )Unit Control )לבין מסלול נתונים )Datapath). מטרת המעבדה הייתה לתכנן מערכת המסוגלת להריץ קוד Assembly נתון, לבצע פקודות אריתמטיות ולוגיות, גישות לזיכרון, ו-פקודות קפיצה מותנות ולא מותנות.

המערכת בנויה ממספר רכיבים עיקריים: יחידת בקרה המבוססת על FSM, מסלול נתונים הכולל
פקודות | עבור | וזיכרונות | ,ALU, Register File, Program Counter, Instruction Register
ונתונים. יחידת הבקרה מקבלת מה־Datapath חיווי לגבי סוג הפקודה והדגלים הרלוונטיים, ובהתאם לכך מפיקה את אותות הבקרה הדרושים לביצוע כל שלב במחזור הפקודה.

בנוסף למימוש המעבד, נדרשנו לבצע סימולציה מבוססת קבצים. בתחילת הסימולציה ה־Testbench טוען את תוכן זיכרון הפקודות ואת תוכן זיכרון הנתונים מקבצים בינאריים שנוצרו מקוד אסמבלי. לאחר סיום ריצת התוכנית, כאשר אות ה־done עולה, ה־Testbench קורא את תוכן זיכרון הנתונים וכותב אותו לקובץ פלט. קובץ זה משמש להשוואה מול הפלט הצפוי.

במסגרת העבודה נבדקה תקינות המערכת באמצעות מספר תוכניות Assembly שונות, שכל אחת מהן בוחנת פעולות שונות של המעבד, כגון חיבור, חיסור, פעולות לוגיות, גישה לזיכרון, וקפיצות מותנות. תהליך האימות בוצע באמצעות ModelSim, תוך שימוש בגלים, מעקב אחר מצבי ה־FSM, בדיקת ערכי רגיסטרים וזיכרון.

בנוסף להרצת תוכניות בדיקה שסופקו במסגרת המעבדה, חלק מהמשימות דרשו כתיבה ופיתוח של תוכניות אסמבלי ייעודיות לצורך בדיקת תקינות המעבד ומימוש פקודות שונות.

המעבד שמומש בפרויקט זה מבוסס על ארכיטקטורת סט הפקודות )ISA )שהוגדרה במסגרת המעבדה. הטבלה הבאה מציגה את הפקודות הנתמכות, פורמט הפקודות, ואופן פעולתן.


מימוש יחידת הבקרה התבצע באמצעות FSM מסוג Mealy, יחידה זו אחראית על הפקת אותות הבקרה בהתאם למצב הנוכחי של המכונה ולקלטים הרלוונטיים, כגון סוג הפקודה ודגלי המצב.

יחידת ה־Datapath ממומשת בצורה מקבילית, כך שבהינתן אותות הבקרה המתקבלים מיחידת הבקרה, מתבצעות הפעולות הנדרשות עבור מחזור הביצוע הנוכחי של הפקודה.

להלן המערכת:


המערכת מקבלת שני קבצי טקסט לצורך אתחול הזיכרונות:
- קובץ בשם txt.ITCMinit – מכיל את הוראות התכנית )instructions )שברצוננו להריץ, ומשמש לאתחול זיכרון הפקודות )ITCM / Memory Program).
- קובץ בשם txt.DTCMinit – מכיל את הנתונים הראשוניים הנטענים לזיכרון הנתונים, לפי סדר כתובות הזיכרון, ומשמש לאתחול זיכרון הנתונים )Data .)Memory / DTCM

בנוסף, המערכת מקבלת אותות בקרה הכוללים: clk – אות השעון של המערכת
rst – אות איפוס המערכת
ena – אות הפעלה המאפשר את ריצת המעבד

בסיום הרצת התוכנית, המערכת מעלה את הדגל done, המעיד על סיום הביצוע. לאחר מכן, תוכן זיכרון הנתונים )DTCM / Memory Data )נכתב לקובץ טקסט txt.DTCMcontent .

## Control Unit:

מהווה את הרכיב האחראי על ניהול רצף הביצוע של הפקודות במעבד ועל תיאום הפעולות בין רכיבי המערכת השונים. תפקידה המרכזי הוא לפרש את סוג הפקודה המתקבלת מה־Datapath, לעקוב אחר מצב הביצוע הנוכחי, ובהתאם לכך להפיק את אותות הבקרה הדרושים להפעלת רכיבי המעבד. המימוש של יחידת הבקרה התבצע באמצעות מכונת מצבים סופית )FSM )מסוג Mealy המסונכרנת לאות השעון. בחירה זו מאפשרת לקביעת היציאות להתבסס הן על המצב הנוכחי של המכונה והן על הקלטים המתקבלים בזמן אמת, כגון סוג הפקודה ודגלי המצב )C ,Z ,N). יחידת הבקרה מקבלת מה־Datapath מידע לגבי הפקודה הנוכחית והסטטוס של פעולות קודמות, ובהתאם לכך מחליטה על מעבר בין המצבים השונים )כגון ,Fetch WriteBack ,Memory ,ALU ,Decode ו־Done), תוך הפקת אותות הבקרה המתאימים לכל שלב במחזור הביצוע של הפקודה.


הקווים
האדומים הם היציאות מ-CONTROL אל ה- DATAPATH ואילו הכחולים הם הפוך.
קווי הTB הם בצבע ירוק.

הFSM מכיל מספר סוגי פקודות בין היתר כתוצאה מהסוגים השונים של ההוראות המצורפות Rtype,Jtype,Itype

להלן הFSM:


להלן שמונה המצבים:
.1 מצב Reset- מצב האתחול של המערכת, אליו מגיעים כאשר אות הבקרה rst עולה ל־.1 במצב זה המערכת מאופסת ומוכנה להתחלת ריצת התוכנית. .2 מצב Fetch - במצב זה מחושבת כתובת הפקודה הבאה לביצוע באמצעות ה־Program Counter, ומתבצעת קריאת הפקודה המתאימה מזיכרון הפקודות. .3 מצב Decode- פיענוח הפקודה ב Datapath ושליחה ליחידת הבקרה ש-בהתאם לכך יודעת איזו הוראה לבצע וכך איזה דגלים לעלות. עבור מצבי Rtype ו- st,ld מעבירים מידע מ-Bus אל רגיסטר A. עבור פעולת Move כותבים ל-File Register וחוזרים אל מצב Fetch. עבור מצבי Jtype מעדכנים את הPC בהתאמה וחוזרים לFetch. .4 מצב Alu- במצב זה מתבצע החישוב הנדרש ביחידת ה־ALU בהתאם לסוג הפקודה, תוצאת הפעולה נשמרת ברגיסטר C.
.5 מצב C- במצב זה עבור פעולה מסוג Rtype כותבים ל - File Register וממשיכים למצב Fetch , עבור פעולת Ld, הולכים למצב Back Write ועבור פעולת st הולכים אל מצב .Memory
.6 מצב Memory- בבמצב זה מתבצעת כתיבה לזיכרון הנתונים )Memory Data), ולאחר מכן חזרה למצב Fetch
.7 מצב Back Write- במצב זה מתבצעת כתיבת הנתון שהתקבל מזיכרון הנתונים אל ה־File Register, בהתאם לכתובת היעד של הפקודה. .8 מצב Done- צב סופי אינסופי, אליו מגיעים עם סיום ריצת התוכנית. במצב זה המערכת מעלה את אות done, אשר מאותת ל־Testbench כי ניתן לקרוא את תוכן זיכרון הנתונים לצורך בדיקת תקינות

## Data Path:

מהווה את החלק במעבד האחראי על ביצוע הפעולות בפועל בהתאם לאותות הבקרה המתקבלים מיחידת הבקרה. יחידה זו כוללת את הרכיבים המרכזיים של המעבד, כגון ה־ALU, ה־Register File, רגיסטרים פנימיים, ה־Counter Program, זיכרון הפקודות וזיכרון הנתונים. ממומש בארכיטקטורת Bus משותף עם שימוש ב־Buffers State-Tri, המאפשרים העברת מידע מבוקרת בין רכיבי המערכת השונים. בהתאם לאותות הבקרה, היחידה מבצעת פעולות כגון טעינת פקודות, קריאה וכתיבה לרגיסטרים, ביצוע חישובים אריתמטיים ולוגיים, גישה לזיכרון, ועדכון מונה הפקודות )PC )כחלק מתהליך הרצת התוכנית.


פירוק הפעולות בIR:


כדי להמחיש את אופן פעולת ה־Datapath, נבחן את ביצוע הפקודה: rc ,rb ,ra add מחזור 1 – Fetch:
בשלב זה מתבצעת קריאת הפקודה מזיכרון הפקודות בהתאם לערך הנוכחי של ה־Program .Counter
1 = IRin → טעינת הפקודה ל־Register Instruction 1 = PCin → עדכון ה־PC לכתובת הבאה
PC + 1 | בחירת | → PCsel = 00
בסיום שלב זה הפקודה נמצאת ב־IR ומוכנה לפענוח.

מחזור 2 – Decode:
בשלב זה מתבצע פענוח הפקודה. ה־Decoder Opcode מזהה שמדובר בפקודת ADD, ויחידת הבקרה מגדירה את אותות הבקרה המתאימים.
במקביל:
קריאת rb מתוך File Register העלאתו ל־Bus טעינה ל־A Register שימוש באותות:
RFout = 1
RFaddr_rd = 01
Ain = 1

ALU Execution – 3 מחזור
בשלב זה:
rc נקרא מתוך File Register מועבר ל־Bus ה־ALU מקבל:
Register Aמ־ | ראשון | operand
operand שני מה־Bus
שימוש באותות:
Cin = 1
RFout = 1
RFaddr_rd = 10
ALUFN = ADD

:Write Back – 4 מחזור

בשלב האחרון:
תוצאת החישוב מ־C Register מועברת ל־Bus נכתבת ל־File Register בכתובת ra. שימוש באותות:
Cout = 1
RFin = 1
RFaddr_wr = 10
לאחר מכן חוזרים למצב Fetch.

## Top:

יחידת ה-TOP הינה היחידה העוטפת את המערכת כולה מקצה לקצה. ביחידה זו אנו מפעילים את שני המודולים המפעילים את המערכת כולה תחת מרכז שליטה אחד. תפקיד היחידה היא לבצע תוכניות שלמות על המעבד הכוללות שימוש מגוון בISA. הרצת התוכנית למעבד כוללת שלושה חלקי פעולה. הראשון - לקרוא את הנתונים מקובץ בינארי ולטעון את התוכנית לזיכרון התוכנית ואת המידע לקובץ הזיכרון. לאחר מכן בחלק השני המעבד לוקח את הפיקוד ומבצע את התוכנית )כלומר בשלב זה 0 = ACTIVE_TB )ולאחר סיום הרצה )המעבד מזהה את OPCODE של הפעולה DONE הנכללת בISA )אנו עוברים לשלב האחרון שהוא לכתוב את הפלט לקובץ.

יחידת הTOP מתוארת ע"י התמונה הבאה - המעטפת הסגולה וסינגלי הTB מזינים את היחידת הבקרה ואת יחידת הdatapath.


## תוצאות הסימולציה:

נחלק את תוצאות הסימולציה לשלושה: סימולציה עבור ה- Control ,סימולציה עבור ה- Datapath וסימולציה עבור המערכת כולה. סימולציה עבור ה- Control:
במהלך סימולציה זו נראה את אופן מעבר המצבים של מספר פעולות וכמות המחזורים הנדרשת לצורך ביצוע הפעולה.
פעולת Add:


ניתן לשים לב כי מרגע עליית add ל1- )מסומן בתכלת( נכנסים למצב Fetch ולוקח 4 מחזורי שעון עד סיום הפעולה, ניתן לשים לב לקווי הבקרה כמו למשל IRIN אשר עולה ל1- בשלב ביצוע הFetch לצורך טעינת הIR.

פעולת load:


ניתן לשים לב כי פעולה מסוג זה לוקחת 5 מחזורי שעון Back Write,C,Alu,Decode,Fetch ניתן לרשום למשל כי בשלב ה- WriteBack קו ה-RFIN עולה ל1- מאחר וטוענים מידע אל ה-.Register File

פעולת done:


ניתן לשים לב כי פעולה זאת לוקחת למעשה 3 מחזורי שעון Done,Decode,Fetch . ברגע Done זהו מצב סיום של המערכת ולכן קווי הבקרה אינם בשימוש. אמנם הסימולציה מבוצעת עד 4500 ns אך בעיקרון מצב זה הוא אינסופי ונשארים בו עד אשר מבצעים ריסוט למערכת.

סימולציה עבור ה-Path Data:
mov r1 4,mov r2,8,add r3 r2 r1,jnc 4 : | הפקודות | ביצוע

שלב ראשון טעינת הפקודות לפי סדר ביצועתם:

מקודד לפי ה-IR.


שלב שני ביצוע פקודה ,4 1r mov

ניתן לראות בRF כי בשורה מספר 1 נמצא הערך .4 בנוסף הPC מתקדם ב.1-שלב שלישי ביצוע פקודת 8 2r mov

ניתן לראות בRF כי בשורה מספר 2 נמצא הערך .8 בנוסף הPC מתקדם ב.1-שלב רביעי ביצוע פקודת 1r 2r 3r add

ניתן לראות בRF כי בשורה מספר 3 נמצא הערך .12 בנוסף הPC מתקדם ב.1-

שלב חמישי ביצוע פעולת 4 jnc


ניתן לראות כי PC אכן עולה ב4- מאחר וקו הבקרה jnc עלה לצורך ביצוע הפעולה, מאחר ולא היה carry בפעולה האחרונה שבוצעה.

נציין בנוסף כי ניתן לראות לאורך כל הסימולציה את הערך על ה-Bus.

סימולציה עבור המערכת כולה: ב-סימולציה זו נרצה לאתחל את קבצי ה txt המתאימים, כלומר את קובץ ה Instruction וקובץ אתחול
Mem Data. לאחר אתחול זה, נוכל להריץ סט פקודות בהתאם לקובץ ה פקודות שנכנסו מותאמות לISA.נבדוק האם הפקודות מתבצעות כראוי. אופן הבדיקה האם הבדיקות התבצעו כראוי הוא הן על ידי מבט על ההדפסות המתבצעות במהלך התוכנית והן על ידי בדיקת קובץ ה txt של הDataMem במוצא.

נדגים מתוך דיאגרת הגלים את אופן ביצוע הפעולה 7R8,R8,R ADD


נתמקד במרווח בין שני הסמנים בצד ימין. נתן לראות ראשית שהפעולה לוקחת 4 מחזורי שעון כמצופה. נראה כי בשלב הDECODE הסיגנל o_add עולה ל1- לוגי כלומר אנו מזהים פעולת חיבור. ניתן לראות כי בתחילת הפעולה F3 =7R ו0=8R. בסיום הפעולה סינגל הo_add יורד ל0-לוגי והערך F3 נטען אל 8R - כלומר פעולת החיבור עברה בהצלחה ואנו עוברים לפעולה הבאה. בנוסף ניתן לראות בקו הסגול את הPC שעולה ב1- בכל פקודה )אלא אם זו פקודת הסתעפות( כנדרש.
נעבור לפקודה הבאה -11 JNC:


שוב נתמקד באיזור בין שני הסמנים. ראשית נשים לב שפקודת הסתעפות לוקחת כ2 מחזורי שעון. בפקודה זו מה שמעניין אותנו זה להזיז את כתובת הPC קדימה או אחורה כנדרש בתוכנית אם דגל הCARRY שווה ל.0 בורוד ניתן לראות שדגל הCARRY שווה ל0 ולכן JNC שווה ל1 ואנו מבצעים הסתעפות. ניתן לראות את כתובת הPC משתנה מ13 ל08 ובצורה דצימלית השינוי הוא מ19 ל8 כלומר מינוס 11 כנדרש. בעליית השעון הבאה המעבד יתחיל אכן מפקודה .8 הפקודה האחרונה שנראה היא פקודת STORE -) 2R(0 8R ST


נשים לב כי פקודה זו לוקחת כ5- מחוזרי שעון. נרצה בפקודה זו לאחסן את ערך 8R בכתובת אותה מחזיק הערך של 2R. ניתן לראות כי 244 = 8R וE000 = 2R כלומר נרצה לאחסן בכתובת זו את .244 ניתן לראות כי הדבר אכן מצבע כצפוי - במחזור הרביעי בפקודה הBUS מעביר את הכתובת לטעינה ובמחזור החמישי הבאס מעביר את הערך הרצוי לתא הזיכרון ובעליית השעון הבאה הערך נשמר ומתחילה פקודה חדשה.

בנוסף מצורף הפלט של תוכניות מספר 5,6 אשר נמצא בקובץ DTCMcontent בכל אחת מתיקיות Output אשר בתיקיית 5/6EX.
פלט תוכנית מספר :6

ניתן לשים לב כי המעבד פועל במדויק. 14 השורות הראשונות הינן ערכי המערך. השורה ה15- הינה סכום ערכי המערך האי זוגיים והשורה האחרונה היא סכום ערכי המערך הזוגיים )בכתיב HEX).

פלט תוכנית מספר :5

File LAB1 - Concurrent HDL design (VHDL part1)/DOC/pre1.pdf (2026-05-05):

## PREPARATION REPORT LAB1

## ADVANCED CPU ARCHITECTURE AND HARDWARE

## ACCELERATORS LAB

361.1.4693

## Yoav Tsur 211903406 Elad Lavi 211626551

## 2026 Semester B

## מבוא

במעבדה זו חווינו התנסות ראשונה עם שפת תיאור החומרה VHDL.
Code Structure, Data Types,Operators and Attributes,Concurrent עם | התעסקנו
.Code,Design Hierarchy ,Packages and Components במעבדה זו, תכננו מודול המכיל את שלושת תת-המודולים הבאים:
- מודול מחבר/חיסור גנרי בין שני וקטורים Y ו-X בגודל n סיביות .
- מודול גנרי המבוסס על גודל n סיביות של Shifter-Barrel( ברירת המחדל היא 8=n).
- לוגיקה בוליאנית הפועלת על וקטורים X וY לפי סיביות. להלן המערכת שנרצה לממש:


המערכת שלנו למעשה מקבלת 3 כניסות:
- וקטור X
- וקטור Y
- ALUFN שזהו וקטור באורך 5 שקובע את סוג הפעולה שמתבצעת.

כאשר ]4:3]ALUFN שווה ל- "01" המודול הנבחר הוא מודול AdderSuber. כאשר ]4:3]ALUFN שווה ל- "11" המודול הנבחר הוא מודול Logic. כאשר ]4:3]ALUFN שווה ל- "10" המודול הנבחר הוא מודול Shifter.

בנוסף כל מודל יכול לבצע מספר פעולות שהן תלויות ב]2:0]ALUFN. המערכת שלנו מוציאה :


- וקטור ALUOUT שזהו וקטור תוצאה בין וקטור X לוקטור Y לפי הפעולה שנבחרה לעשות
- 4 דגלים , V,C,Z,N כאשר N מסמן אם התוצאה שלילית, Z אם התוצאה היא 0 , C אם יש Carry ו-V אם קיים Overflow בתוצאה )מקרה זה רלוונטי רק עבור המודול .)ADDER/SUB
בנוסף כאשר ALUFN יהיה ערך לא מוגדר נדאג שהתוצאה תהיה מיידית 0 ובהתאם לכך הדגלים.

להלן ה-ISA של המערכת:

## מודול AdderSub

הסבר תיאורטי:
מודול זה הינו אחד משלושת המודולים בשכבה התחתונה ותפקידו הוא לבצע פעולות אריתמטיות הנקבעות לפי I_ALUFN( שלושת הביטים LSB שלו(. המודול מבצע את כל חמשת הפעולות ע"י שימוש במחבר אדווה הממומש באמצעות FA בסיסי ומוציא כתוצאה את פלט הפעולה ,סיבית נשא


מצורף באיור הבא:

נשים לב כי מוגדר בכניסה למחבר האדווה גם קו בקרה CONT_SUB. מתוך הסתכלות על שלושת הסיביות LSB של I_ALUFN נראה כי עבור פעולות חיבור נרצה כי קו הבקרה יהיה 0 ועבור פעולות חיסור או משלים נרצה שקו הבקרה יהיה '1'. זה הגיוני כיוון שעבור פעולות חיסור במספרים SIGNED נבצע את הפעולה ע"י שימוש בשיטת המשלים ל.2- כך שאנו הופכים את הסיביות של הוקטור X ומוסיפים בחיבור הראשון 1 = Cin. את הקו הבקרה קבענו לפי XOR של שלושת הסיביות כיוון שעבור מספר '1' אי זוגי תוצאת ה XOR הינה 1 ועבור מספר '1' זוגי תוצאת ה XOR הינה 0 וזה מתאים במדויק עבור המקרים שלנו כפי שמצורף בתמונה הבאה מתוך ההוראות.


את מימוש כל הפעולות במודל זה ביצענו ע"י לולאה שמשתמשת בסינגל reg מסוג וקטור של ביטים באורך n עבור שמירת ערך ה Cin וה Cout בצורה גנרית לכל גודל של וקטור. מצורף, איור הממחיש את דרך פעולת מחבר האדווה עבור הפעולות האריתמטיות נרצה לבצע:


נפרט על הפעולות:
פעולת addition simple: במקרה זה אנו מחשבים את תוצאת החיבור של X+Y ולכן נשתמש במחבר האדווה בצורה ישירה ונשים לב כי קו הבקרה 0 אינו משנה את הוקטור X כיוון שXOR עם 0 משאיר וקטור כמו שהוא.
פעולת subtracting: במקרה זה אנו מבצעים חיסור ע"י X-Y. בפעולה זו קו הבקרה הינו 1 והוא משמש כמהפך ע"י שער XOR לוקטור X וגם ככניסת סיבית Cin לחיבור הראשון של מחבר האדווה וכך אנחנו
מממשים לפי הגדרה את פעולת החיסור במספרים signed. פעולת Negative: במקרה זה נרצה לקחת את וקטור הכניסה X ולהחזיר בתוצאה וקטור שערכו יהיה -X.
נממש זאת בדומה לחיסור רגיל ע"י שיטת המשלים ל2 כאשר נגדיר את וקטור הכניסה Y למחבר האדווה להיות וקטור שכולו אפסים. פעולת increment double: בפעולה זו נרצה לממש את הפעולה +2Y ונוכל לעשות זאת כמו ע"י חיבור רגיל כאשר נגדיר את הוקטור X בכניסה למחבר האדווה להיות בעל ערך '2' בצורה בינארית. פעולת decrement double: כמו בפעולת החיבור כאשר נגדיר את הוקטור X להיות בעל הערך '-2' נקבל את תוצאה -2Y.

תוצאות הסימולציה:
כעת נרצה להריץ סימולציה עבור המודול הזה שתכלול מספר מקרים בסיסיים יחד עם מקרי קצה שיכולים להתקיים כך שבכל אחד מהמקרים ביצענו השוואה בין מה שהתקבל לבין התוצאה הנכונה שחושבה על ידינו המקרים שנלקחו בחשבון הם: חיבור עם וללא carry,חיסור, היפוך, כניסה ALU לא מוגדר. להלן תוצאות הסימולציה בתצוגת DEC:


ניתן לראות היכן שהחץ הצהוב כי הALU מוגדר להיות 010 שזוהי פעולת NEG ואכן ניתן לראות כי X הוא 20 ואילו התוצאה היא .-20 מקרה נוסף לצורך הדוגמה: כאשר הALU הוא 011 הפעולה היא +2Y ואכן ניתן לראות כאשר -13=Y התוצאה היא .-11

## מודול SHIFTER:

הסבר תיאורטי:
מודול זה הינו המודול השני מתוך שלושת המודולים בשכבה התחתונה ותפקידו לבצע שתי פעולות אפשריות כתלות בשלושת סיביות ה LSB של וקטור הכניסה I_ALUFN. הפעולות האריתמטיות נרצה לבצע הינן הזזה ימינה והזזה שמאלה של וקטור הכניסה Y כאשר אנחנו בוחרים את כמות ההזזות כתלות בK הסיביות הLSB של וקטור הכניסה X. כיוון ההזזה נקבע ע"י ה LSB של וקטור הכניסה I_ALUFN כאשר '0' מסמן הזזה שמאלה ו'1' מסמן הזזה ימינה. כאשר אנחנו מזיזים את הוקטור Y שמאלה אנחנו משרשרים אפסים בצד ימין כ-כמות ההזזות. באופן סימטרי עבור הזזות ימינה. מצורף תיאור גרפי של המודול:

הסבר אופן הפעולה: על מנת לממש את השיפטר הגדרנו סיגנל D1Dx1 MATRIX בגודל +1K )המקום ה-0 זה וקטור Y לפני ההזזות( כאשר כל תא במטריצה מייצג את הוקטור Y לאחר ההזזה ה-i מתוך K הזזות.
בנוסף הגדרנו וקטור המשמש כזיכרון לתוצאת הcarry. הלולאה פועלת בצורה הבאה: בכל שלב אנחנו מזיזים את הוקטור Y שעבר -1i שלבי הזזות כמות של 2^i הזזות ימינה/ושמאלה שאליו משורשרים אפסים כ-כמות ההזזות וזאת כתלות בביט הI ה LSB של הוקטור X. אם הביט הנ"ל הוא 0 אין צורך להזיז בכלל את הוקטור ונוכל להעתיקו באופן זהה למקום הבא במטריצה. אם הביט הוא '1' אזי נבצע את ההזזות. בנוסף אנחנו כותבים לוקטור הcarry את הביט האחרון שאותו הוצאנו מתוך וקטור Y.
בסיום הלולאה נקבל את הוקטור שעבר את מספר ההזזות כתלות בערך הדצימלי של K הסיביות הLSB של X ואת הcarry.
מצורף איור הממחיש את פעולת ההזזה:


תוצאות הסימולציה:
כעת נרצה להריץ סימולציה עבור המודול הזה שתכלול מספר מקרים בסיסיים יחד עם מקרי קצה שיכולים להתקיים כך שבכל אחד מהמקרים ביצענו השוואה בין מה שהתקבל לבין התוצאה הנכונה שחושבה על ידינו המקרים שנלקחו בחשבון הם : הזזה ימינה, הזזה שמאלה וכניסה ALU לא מוגדרת. להלן תוצאות הסימולציה בתצוגה בינארית:


ניתן לראות כי במקרה הראשון למשל כי עבור 000 ALU בוצעה הזזה שמאלה לוקטור Y. הוקטור Y הינו .11111101 ואילו 3=K וX ב 3 הסיביות האלו : 101 נבצע 5 הזזות שמאלה ולכן וקטור התוצאה הינו : ,10100000 בנוסף ה-COUT עלה ל1 כי יש carry. דוגמה נוספת עבור ALU לא מוגדר ניתן לראות כי וקטור התוצאה הוא וקטור אפסים וה COUT .

## מודול LOGIC:

מודול זה הינו המודול השלישי בשכבה התחתונה ותפקידו לבצע כ7 פעולות לוגיות מובנות בשפת VHDL בין הוקטורים X וY כתלות בשלושת הביטים ה LSB של וקטור הכניסה I_ALUFN. מימשנו את המודול באמצעות MUX המשתמש ב3- ביטי הבקרה כדי לבחור אחת מתוך 7 פעולות שונות כאשר הכניסה השמינית מנוצלת למניעת מצבים לא מוגדרים וזאת ע"י איפוס המוצא.

תוצאות הסימולציה:
כעת נרצה להריץ סימולציה עבור המודול הזה שתכלול מספר מקרים בסיסיים יחד עם מקרי קצה שיכולים להתקיים כך שבכל אחד מהמקרים ביצענו השוואה בין מה שהתקבל לבין התוצאה הנכונה שחושבה על ידינו
המקרים שנלקחו בחשבון הם: כל אחת מהפעולות הקיימות ב ISA ובנוסף ALU לא תקין. להלן תוצאות הסימולציה בתצוגת בינארית:


ניתן לראות היכן שהקו הצהוב כי עבור 010=ALU מוגדרת הפעולה AND. ואכן עבור 00010100=X ו 11110111= Y התוצאה היא : .00010100 דוגמה נוספת כאשר ה000 ALU ביצענו NOT לY ואכן עבור 11111101= Y התוצאה הינה: .00000010

## מודול TOP:

הסבר תיאורטי:

מודול זה הינו המודול אשר עוטף את המערכת כולה. הוא מקבל את וקטורי הכניסה Y,X ואת וקטור הכניסה I_ALUFN ומעביר לתת-מודול המתאים את הוקטורים Y,X יחד עם שלושת הביטים ה LSB של I_ALUFN. בנוסף בחלק זה טיפלנו בעניין הדגלים שהמערכת מוציאה כתלות בתוצאה המתקבלת מ-הפעולה המתאימה. על מנת לשמור על צריכת הספק נמוכה נרצה שרק המודל המתאים יבצע את הפעולות ואילו שאר המודולים לא יבצעו פעולות ולכן השתמשנו בשערי AND על מנת להעביר את הוקטורים Y,X רק לסיגנלים הדרושים לביצוע הפעולה )כלומר למודול המתאים(. בכל אחד מהפלטים השתמשנו ב MUX ע"י שימוש בSELECT- WITH כדי להעביר את התוצאה הרלוונטית ל ALUOUT בהתאם לקוד הפעולה. הסבר עבור הדגלים:
דגל Z: דגל זה שווה ל1 עבור וקטור תוצאה שכולו אפסים, מימשנו את הלוגיקה באמצעות השוואה של וקטור התוצאה לוקטור אפסים שהגדרנו בעצמנו. דגל C: דגל זה שווה ל1 במידה ויש carry, דבר שיכול לקרות רק עבור מודולים AdderSubו-Shifterולכן במקרה שאלו היו המודלים דגל C היה שווה ל carry שהוגדר כתוצאה מתת המודול הרלוונטי.
בכל מקרה אחר דגל C שווה ל'0' כיוון שאין Carry. דגל N: דגל זה שווה ל1 במידה וביט הMSB של התוצאה שווה ל'1' לכן הגדרנו אותו כך באופן ישיר. דגל V: דגל זה מייצג האם פעולת חיבור או חיסור מייצרת "גלישה" כלומר תוצאה שאינה יכולה לקרות וקרתה כתוצאה ממספר מוגבל של ביטים. מצורף התנאים שיכולים לגרום ל-Overflow:


ע"י שימוש בלוגיקה בוליאנית , טבלת אמת הגענו למשוואות הבאות היוצרות Overflow כאשר אנחנו מנצלים את ידיעת קוד הפעולה לכך שנוכל להתחשב במקרי גלישה בפעולות חיבור וחיסור בנפרד:


תוצאות הסימולציה:
כעת נרצה להריץ את הסימולציה עבור המערכת הכוללת שניתנה לנו דרך המודל tb ref1. vhd להלן תוצאות הסימולציה:

לאחר הרצת הTB שניתן לנו מראש ייצרנו קובץ LST , את הקובץ הזה ואת הקובץ LST שניתן לנו מראש השווינו בתוכנה TextDiff לצורך מציאת הבדלים. מאחר והכל ירוק ניתן להבין כי ההרצות אכן זהות ולכן ניתן לראות כי עבור הTB שנכתב לנו מראש עבור בדיקת מקרים מסוימים הקוד שלנו עובד כנדרש. בנוסף הנה קובץ WAVE שבו ניתן לראות את תוצאות הסימולציה לTB שאותו אנחנו כתבנו, הוא מכיל
למעשה מקרים מכל המודלים האפשריים הכולל מקרי קצה.

ניתן לראות בתמונה את תוצאות הסימולציה. למשל היכן שהחץ הצהוב הALU בתצורת DEC הוא 8 שזה למעשה 01000 שזהו מודל Addsub פעולת חיבור בין הוקטורים X ו Y. לכן, עבור 00000100=X כלומר 4 ועבור 11111101=Y כלומר -3 בשיטת משלים ל 2 התוצאה הינה 1 ובצורת ביטים ניתן לראות כי הוקטור הוא .00000001 בנוסף ניתן לראות בתמונה כי הורם דגל Carry.

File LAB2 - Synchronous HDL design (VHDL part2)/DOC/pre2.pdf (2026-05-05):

## PREPARATION REPORT LAB2

## ADVANCED CPU ARCHITECTURE AND HARDWARE

## ACCELERATORS LAB

361.1.4693

## Yoav Tsur 211903406 Elad Lavi 211626551

## 2026 Semester B

## מבוא

במעבדה זו תכננו ומימשנו מערכת דיגיטלית סינכרונית בשפת תיאור חומרה VHDL לגילוי רצפים )Detector Sequence). המערכת נועדה לזהות תתי-סדרות בתוך זרם נתונים של דגימות כאשר הקריטריון לזיהוי הוא הפרש חשבוני קבוע בין דגימות עוקבות. מימוש המערכת מתבסס על שילוב בין תיאור מבני )Structural )לתיאור התנהגותי )Behavioral), תוך שימוש ברכיב Adder גנרי לביצוע חישוב ההפרשים בשיטת המשלים ל.2- המערכת דוגמת את כניסת הנתונים באמצעות שרשרת פליפ-פלופים המסונכרנת ע"י שעון CLK. המערכת מפרידה בין שלב חישוב ההפרש לבין תהליך הספירה אשר מבוצע על ידי מונה פנימי המתקדם רק כאשר קיים התנאי של Enable פעיל וההפרש בין דגימות עוקבות תואם לקוד הגילוי שנבחר. תכנון זה מבטיח כי אות הגילוי )detector) יעלה ל-'1' לוגי רק לאחר זיהוי רצף תקין. בנוסף המערכת כוללת אות איפוס )Reset )המבטיח חזרה למצב התחלתי תקין. התכנון בוצע תוך שימוש בגנריות על מנת להתאים לכל רוחב של דגימות הנתונים ולכל רצף שנבחר וזאת ללא צורך בשינוי הלוגיקה המרכזית של המערכת. להלן דיאגרמה המייצגת את מימוש המערכת:


בנוסף מצורפת טבלה המגדירה את ההפרשים המתאימים בין כל זוג דגימות בהתאם לDetction code הנכנס למערכת:


## מודול TOP

מודל זה הינו המודל אשר עוטף את המערכת כולה. הוא מקבל וקטור כניסה X ברוחב גנרי של N ביטים המייצג את זרימת הנתונים שעליהם נרצה לבצע את פעולת המערכת, מספר integer המוגדר להיות בין 0 לבין 3 שנקרא Code Detecion הנועד לקבוע את ההפרש הרצוי בין דגימות עוקבות )נשים לב כי לפי הטבלה הוא שווה תמיד להפרש בין שתי הדגימות הקודמות פחות 1( ובנוסף מקבל שלושה קווי בקרה : Enable ,Reset ,Clock. המערכת מוציאה כפלט קו Detector שמסמן האם אנחנו נמצאים במצב שבו יש לנו רצף תקין וחוקי של הפרשים עוקבים בין דגימות. בהתאם לדרישות המשימה, המודל נכתב באמצעות שלושה תהליכים )Processes )נפרדים המאפשרים מימוש מקבילי ויעיל בחומרה: להלן תיאור קצר על החלוקה לתהליכים:
.1 תהליך הדגימה: אחראי על דגימת זרם נתוני הקלט x. התהליך משתמש ב 2 FlipFlop המחוברים בטור כדי לאחסן את שתי הדגימות האחרונות מהעבר. תהליך זה הינו סינכרוני לשעון ומתבצע רק כאשר קו הבקרה ena נמצא ב'1' לוגי. .2 תהליך לוגיקה וחישוב: שלב זה מבצע את הפעולה האריתמטית של חישוב ההפרש באמצעות Adder Carry Ripple בשיטת המשלים ל.2- לאחר מכן הוא משווה את התוצאה לערך הצפוי )Code Detecion). במידה וקיימת התאמה, מופעל Signal Valid. השימוש ברכיב Adder גנרי בודד עבור כל פעולות החישוב במערכת מהווה פתרון חסכוני במיוחד. .3 תהליך ספירה: תהליך זה מנהל מונה סינכרוני. המונה מתקדם רק כאשר האות המאפשר )Enable )הוא '1' ואות התקפות )Valid )פעיל. אם אות Valid נופל או שמתבצע איפוס )Reset), המונה מתאפס מיידית ל.0- ברגע שהמונה מגיע לסף המוגדר מוצא הגלאי )Detector )משתנה ל.1-
הפרדת המערכת לשלושה תהליכים נפרדים מאפשרת מימוש מקבילי בחומרה, כך שפעולות הדגימה, החישוב והספירה מתבצעות בו-זמנית בכל מחזור שעון. בחירה זו משפרת את יעילות המערכת ומבטיחה תגובה מהירה בזמן אמת לשינויים בזרם הנתונים.

התהליך הראשון -תהליך הדגימה:


תחילה נציין כי זהו תהליך סינכרוני אשר הגדרנו לו רשימת רגישויות שכוללת Reset, Clock. ניתן לשים לב שהגדרנו 2 סיגנלים 2ff1,ff שהם למעשה שימשו לנו כרכיבי הזכרון, הFlipFlop של המערכת.
במידה והקו בקרה Reset עולה ל 1- אנחנו מאפסים את רכיבי הזכרון. דאגנו שלרכיבי הזכרון תבוצע השמה רק כאשר יש עליית שעון ובנוסף קו הבקרה Enable שווה ל.1-

התהליך השני - תהליך חישוב ההפרש והשוואה לקוד הגילוי:

בשונה מתהליכי הדגימה והספירה הסינכרוניים, תהליך זה ממומש בלוגיקה קומבינטורית ללא שימוש במילה השמורה process, מה שמאפשר חישוב מיידי של הנתונים. למעשה, בתהליך זה אנחנו מבצעים בדיקה אם ההפרש בין שתי הדגימות השמורות לנו מקיים את התנאי הרלוונטי ל Code Detection שנקלט במערכת, כפי שמצויין בתמונה למעלה של הטבלה. לצורך בדיקת ההפרש השתמשנו במודל הADDER שניתן לנו מראש. כדי לבצע חיבור דאגנו לבצע פעולה לוגית של שלילה על הוקטור b אשר הוא המספר המחסר ולהכניס 1= Cin כנשא. אחכ הגדרנו סיגנל עזר שנקרא Valid אותנו הגדרנו להיות 1 כאשר תוצאת החיסור תואמת בדיוק להפרש הנדרש.

התהליך השלישי - ניהול המונה והפקת אות הגילוי


תהליך זה למעשה פוצל לשני חלקים משלימים על מנת להבטיח ביצועים אופטימליים ותגובה מהירה של המערכת:
.1 עדכון המונה: חלק זה אחראי על ניהול המונה הפנימי בסנכרון לשעון המערכת ולקו האיפוס האסינכרוני )Reset). המונה סופר את רצף הביטים התקינים המגיעים מהסיגנל Valid. פעולת הספירה מותנית בסיגנל Enable פעיל; כאשר הוא נמוך, המונה "קופא" ושומר על ערכו. במידה וסיגנל ה-Valid יורד ל-'0' )שבירת הרצף( או שמתקבל אות איפוס, המונה חוזר מיידית ל.0-
.2 הפקת אות הגילוי: עדכון אות המוצא detector מתבצע מחוץ לתהליך הסינכרוני באמצעות פקודת select-with קומבינטורית. בחירה זו נובעת מהרצון למנוע השהיה )Delay )של מחזור שעון נוסף.אם היינו מעדכנים את ה-detector בתוך ה-process, הערך היה משתנה רק בעליית השעון הבאה לאחר הגעת המונה לערך המטרה. הוצאת התנאי אל מחוץ לתהליך מבטיחה תגובה בזמן אמת.

## תוצאות הסימולציה:


במשימה קיבלנו שלושה קבצי TB שנכתבו מראש אותם התבקשנו להריץ על הTOP אותו אנו כתבנו ולהשוות את קבצי הLIST בתוכנה TextDiff להלן התוצאות של שלושת ההרצות: ההרצה נבדקה עבור סימולציה לאורך של 4 מיקרו שניות. תוצאות הרצת 1TB:

נציין כי אמנם לעומת שאר הבדיקות לא מופיע רקע ירוק המסמן שאין טעויות אך מבדיקה קפדנית אין הבדלים בין קבצי הlist והתוצאות אכן זהות.

תוצאות הרצת 2TB:

תוצאות הרצת 3TB:

## :TB_top

בנוסף התבקשנו לכתוב TB משלנו שיבדוק את הTOP אותו כתבנו. הכללנו מקרה קצה ומיזגנו מקרים אפשרים כדי לבדוק אם מוצא המערכת אכן מתקבל כפי שצריך. למעשה בדקנו 4 מקרים שונים : .1 המקרה הראשון הוא למעשה מצב בו הכל תקין, בדיקה שאכן מוצא המערכת נהיה 1 כאשר יש רצף תקין שגדול מ-m(במקרה שלנו 7=m ו8=n אך נדגיש כי המערכת תתמוך בכל פרמטרים תקינים שנכניס(. בדקנו כי מוצא המערכת ישאר 1 מרגע קיום התנאי עד אשר הספירה תתאפס או Code Detecion ישתנה. להלן תוצאות הבדיקה בתצורת WAVE:


נשים לב כי תוצאות הסימולציה מדויקות. קיים עיכוב של שני מחזורי שעון מרגע הפעלת המערכת ועד תחילת הספירה הנובע מהצורך למלא את שרשרת הפליפ-פלופים על מנת לאפשר לרכיב הAdder לחשב הפרש תקין. לכן רק במחזור ה10- המוצא של המערכת יעלה ל.1 דבר זה מתאים במדויק לדרישות המערכת.

.2 המקרה השני שבדקנו הוא מצב בו קו ה-Enalbe" נופל" וערכו משתנה ל0- במהלך הספירה. במצב זה לפי Process מספר 3 יש השהייה ואין בדיקה עד אשר הEnable חוזר להיות .1 בנוסף אנחנו לא ממשיכים לדגום ערכים חדשים אל תוך הפליפ-פלופים. בדקנו מה קורה לאחר מכן כאשר הX ממשיך להשתנות בערכו ולגדול. למרות שEnable שווה ל0- ואיך זה ישפיע על המערכת כאשר הקו בקרה יעלה חזרה ל.1-להלן תוצאות הבדיקה בתצורת WAVE:


נשים לב כי תוצאות הסימולציה מדוייקות. ברגע שEnable יורד ל0- ישנה עצירה בבדיקת קיום התנאי וגם בתהליך הדגימה לכן המערכת "קופאת" אבל ערכי X בtestbench ממשיכים להשתנות אך למעשה לא נדגמים והמערכת אינה פועלת עליהם אלא שומרת את הערכים הישנים. כתוצאה מכך, כאשר הEnable עולה ל1- מבוצעת בדיקה בין 12= X ל 6=X. מאחר וההפרש לא מקיים את התנאי עבור Code Detecion ששווה ל1- מתאפס המונה.

.3 המקרה השלישי אותו בדקנו הוא מה קורה כאשר הX קופץ באופן פתאומי לערך אחר, התנאי נשבר לפעם אחת ולאחר מכן חוזר להיות תקין, איך זה משפיע על ספירת הרצף ומוצא המערכת.
להלן תוצאות הבדיקה בתצורת WAVE:


נשים לב כי תוצאות הסימולציה מדוייקות, ברגע שX עולה לערך 25 ההפרש בין 2 הדגימות הוא 10 ולא 3 כפי שCode Detection ציפה לראות. הספירה למעשה מתאפסת, ומתחילים לספור מחדש עד אשר הרצף יהיה גדול ממש מ-m. ניתן לשים לב כי לקראת סוף הדוגמה זה אכן קורה ונשים לב כי לאחר 8 בדיקות חדשות של הפרשים המוצא עולה ל'1' לוגי כצפוי.

.4 המקרה הרביעי והאחרון הוא מצב בו קו הבקרה "איפוס" )Reset )מופעל, נבדוק איך זה משפיע על הספירה ומוצא המערכת. להלן תוצאות הבדיקה בתצורת WAVE:


נשים לב כי תוצאות הסימולציה נכונות. אילולא קו הבקרה reset היה משתנה , היינו מקבלים רצף תקין באורך הגדול מ-m ומוצא המערכת היה משתנה ל.1-מאחר וReset עלה ל1 הספירה התאפסה והספירה החלה מחדש.

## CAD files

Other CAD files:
Final project - MCU and HW-Accelerators architecture and design/Quartus/RV32IMscMCU/stp1.stp
LAB4 - FPGA, Quartus, Timing & Power Analysis, and Validation/Quartus/stp2.stp
LAB5 - RISC-V Single-Cycle and Pipelined cores architecture/Quartus/RV32IM_sc/stpSingleCycle.stp
LAB5 - RISC-V Single-Cycle and Pipelined cores architecture/Quartus/RV32IM_pipeline/stp1.stp

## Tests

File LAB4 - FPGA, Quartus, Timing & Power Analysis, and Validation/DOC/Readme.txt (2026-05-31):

LAB4 - FPGA based Digital Design

This project implements a digital system with an I/O interface on a DE10-Lite FPGA board. The system is organized around a configurable Arithmetic Logic Unit (ALU) and a Pulse Width Modulation (PWM) controller, supporting asynchronous data loading via latches and real-time visualization on 7-segment displays. 

Input and Output Description
* CLK_50MHZ – System master clock.
* KEY –4  Pushbuttons for asynchronous data loading and system reset (Active Low).
* SW – 10 Input switches for data operands, ALUFN command selection, and multiplexer control.
* LEDR – Output LEDs displaying the current ALUFN opcode and internal processor status flags.
* HEX0 to HEX5 – 7-segment displays indicating the active input bytes and ALU computation results.
* GPIO9 – Dedicated serial output pin for the generated PWM signal.

The VHD file:
LOGIC.VHD:
* Performs bitwise logic operations (AND, OR, XOR, etc.) between X and Y based on ALUFN[2:0].

SHIFTER.VHD:
* This module performs according to the ALUFN input a barrel-shifter based shift, where if ALUFN[2:0] = 000 then we will shift to the left and if ALUFN[2:0] = 001 we will shift to the right. 
We decided to implement the module by going through all k layers (where k=log_2⁡n) and for each layer we will perform a shift accordingly so that if the bit in the relevant layer in X is 0 we will not perform a shift and then the origin of the layer will be the same as the entry and otherwise we will perform a shift according to the layer.

AdderSub.VHD: 
* This module performs Math operation between the input vectors X and Y according opcode ALUFN[2:0]. It operates by using it’s sub-module FA (full-adder) to operate ADD/SUB/NEG/DOUBLE INC/DOUBLE DEC operations.
 Note that the ADDER/SUBTRACTER is performed by Y+X or Y + (Not (X)).
 DOUBLE INC/DOUBLE DEC performed on the input Y vector only by changing X vector value for ‘2’ value in decimal and then using the same adder/subtracter. 
 NEG operation is performed on the input X vector by using Y vector as zero vector and subtracting X vector.
 
FullAdder.VHD:
* This is the basic building block used by the AdderSub module. It receives X, Y and Cin bits and outputs the Sum and Cout bits.

AuxPackage.VHD:
* This file contains in the form of a package all the components that we would like to use throughout the laboratory.

top_ALU.VHD:
* This module wraps the entire system and implements a structural design hierarchy. It receives the input vectors X, Y and the control signal ALUFN to manage the data flow between sub-modules. Based on the operation code ALUFN[4:3], the Top module selects which functional unit is active: "01" for Adder/Subtractor, "10" for Shifter, or "11" for Logic. The module is responsible for multiplexing the results from the various units into a single output vector, ALUout, and generating the status flags Z, N, C, and V based on the operation's outcome.
*  To achieve lower power consumption, the design includes logic gates at the inputs of the sub-modules. These gates ensure that signals make transitions only when the specific module is selected by ALUFN[4:3], preventing unnecessary switching activity.

PWM.vhd:
* A 16-bit timer/counter-based Pulse Width Modulation (PWM) generator. It supports dynamic mode changes (MODE) , enabling pulse generation in Set/Reset, Reset/Set, and Toggle configurations. The total PWM period is determined by the Y register value , while the duty cycle is controlled by the X register value. 
pll.vhd:
*  A hardware clock management wizard-generated component based on Altera's altpll megafunction. It takes an incoming 50 MHz oscillator clock source and divides it down to generate a stable, locked 2 MHz internal system clock for the design. 

SevenSegDecoder.vhd: 
* A combinational decoder that converts a 4-bit hexadecimal nibble into the corresponding 7-segment display code. It uses active-low logic to properly drive and illuminate the hex displays on the FPGA board. 

SystemTop.vhd:
*  The system-level structural wrapper that integrates the core functional logic of the project. Depending on the selection bits of the ALU function input (ALUFN), it routes and masks input signals to drive two main subsystems in parallel: an 8-bit Arithmetic Logic Unit (top_ALU) for data processing and a 16-bit Pulse Width Modulation (PWM) generator. 

FPGA_Top.vhd:
*  The top-level entity of the design implemented on the FPGA board. It interfaces directly with the physical hardware I/O, including switches (SW) , push-buttons (KEY) , LEDs (LEDR) , and seven-segment displays (HEX0-HEX5). It manages clock distribution via the PLL and includes an asynchronous latch process to load input data into the X and Y registers based on button and switch combinations. 
insert the data to the SystemTOP (the design of the LAB).

Created by Yoav Tsur and Elad Lavi.

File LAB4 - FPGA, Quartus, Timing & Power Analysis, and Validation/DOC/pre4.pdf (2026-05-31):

## PREPARATION REPORT LAB4

## ADVANCED CPU ARCHITECTURE AND HARDWARE

## ACCELERATORS LAB

361.1.4693

## Yoav Tsur 211903406 Elad Lavi 211626551

## 2026 Semester B

## תוכן עניינים

## Contents

# מבוא

במעבדה זו למדנו להשתמש ביכולות של תוכנת Quartus ובפרט לבצע סינתזה עבור מודלים שפיתחנו בעבר במעבדה הראשונה בבניית יחידת הALU ובנוסף לייצר סדרת פעולות שונות של PWM בעל CYCLE DUTY לבחירתנו באמצעות טיימר וחלוקת שעון וטעינת ערכים ברזולוציה של 16 ביט. את הסינתזה ביצענו על גבי
.standard 10DE | כרטיס | של FPGA V Cyclone

הDESIGN שלנו למעשה בנוי כך שהמלבן העליון )היחידה האריתמטית לוגית( מגיעה ישירות מהמעבדה הראשונה ואליו הוספנו תכנון בVHDL של בלוק נוסף - רכיב סינכרוני התומך בשלושה מצבי פעולה ליצירת אותות ריבועיים PWM.

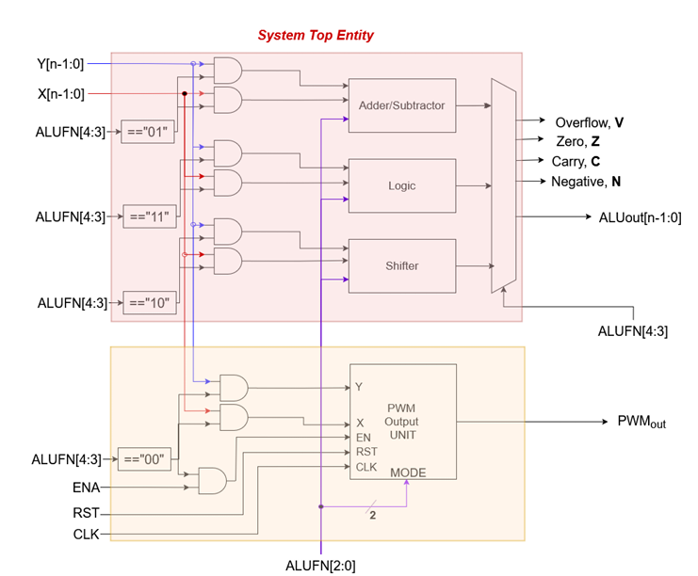
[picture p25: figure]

figure 1: System Top sketch

רכיב הUnit Output PWM בנוי כך :

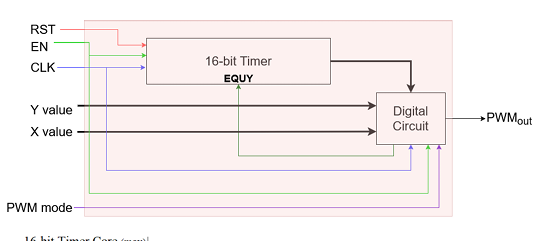
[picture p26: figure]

figure 2: Timer operation sketch

כאמור היחידה תומכת ב3 מצבי פעולה ליצירת הגלים המרובעים המוצגים בתמונה הנ"ל:

figure 3: Timer modes

האותות נוצרים למעשה ע"י טיימר הפועל בין 0 לערך של רגיסטר Y היכול להכיל עד 16 ביטים. כאשר המונה מגיע לערך של Y נדלק הסיגנל EQUY כך שאנו מאפסים את המונה ומתחילים ספירה מחדש. לצורך קביעת הדיוטי סייקל אנו משתמשים ברגיסטר X. נפרט על שלושת אופני הפעולה: מצב ראשון - reset/set: במנייה מ0 עד לערך של X המוצא הוא ,0 מX ועד Y המוצא הוא .1 כך הדיוטי סייקל הוא למעשה Y/X( כפול 100 לאחוזים(. מצב שני - set/reset: זהו המצב המשלים של המצב הראשון והדיוטי סייקל שלו יהיה 1 פחות Y/X. מצב שלישי - toggle: במצב זה אנו משנים את המוצא בכל פעם שאנו מגיעים לערך X כך שיש לנו במצב יציב מחזור שלם )מX עד לX בפעם הבאה( לעלייה ובדומה לירידה. כך שלמעשה אנו עובדים תמיד בדיוטי סייקל של 50 אחוז ללא תלות בערכי X וY והמימוש הוא מימוש של חלוקת תדר ב.2

מצורף תמונה של ה ISA הכוללת החדשה שנדרשנו כאשר נציין כי במצב PWM אנו עובדים עם וקטורים באורך 16 ואילו בשאר המצבים וקטורים באורך .8

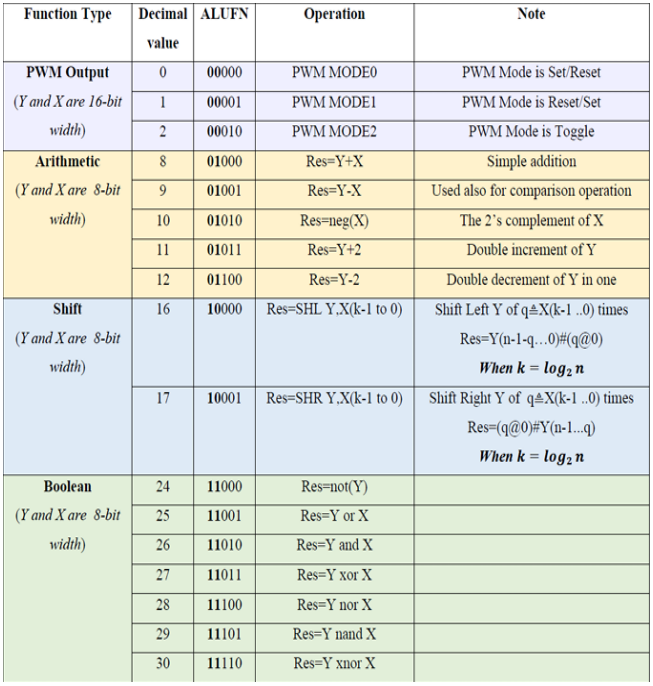
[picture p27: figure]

figure 4: System ISA - includes ALU & PWM operations

להלן המערכת כולה הצרובה על הFPGA:

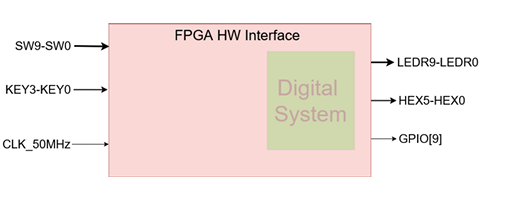
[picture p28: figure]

figure 5: FPGA Hardware user interface

באמצעות הכפתורים והמתגים אנו בוחרים את סוג הפעולה שיש לעשות. הכניסות למערכת הינן 10 סוויצ'ים ו4 כפתורי פוש LOW ACTIVE. שמונת הסוויצ'ים הנמוכים מיועדים לטעינת ערכים לX וY. הסוויץ התשיעי משמש כENA למצב PWM והסוויץ האחרון משמש כבורר עבור הPWM כיוון שנצטרך לטעון עבורם 16 ביטים כלומר 8 בכל פעם. את המוצאים של המערכת אנו רואים בשני אופנים שונים. את ערכי Y X אנו רואים בHEX - 0 HEX .3 את המוצא מהALU( עבור פעולות PWM המוצא תמיד יראה 0 כנדרש( אנו רואים בHEX - 4 HEX .5 את ששת נורות הLCD הצגנו בעזרת דיקודר שהגדרנו כיוון שעלינו לחווט את המוצא )ערך של 8 ביטים שנדרש להציג ב2 ספרות בייצוג הקסאדצימלי( באמצעות 7 ביטים המייצגים את הLCD כמצורף בתמונה הבאה:

figure 6: 7 bit decoder to led output

הכפתורי BUTTONS PUSH נועדו על מנת לאפשר ממשק עם הלוח עצמו. שני הכפתורים הנמוכים משמשים כENA לטעינת ערכים לX וY. כפתור מספר 2 הינו להעברת קוד הפעולה מתוך הISA וכפתור מספר שלוש משמש כENA לפעולות PWM. לצורך החיווטים בתוכנת QUARTUS השתמשנו ב USER MANUAL לערכת DE.10- להלן השרטוט המתאר את החיבורים:

figure 7: FPGA interface against Digital System

# בדיקות ביצועים

.1רכיב אסינכרוני ALU:
בדיקה זו נעשתה על מנת לבדוק ביצועים ראשוניים של ה ALU שפיתחנו במעבדה הראשונה אך הפעם בשילוב של סינתזה על גבי כרטיס FPGA אמיתי. מכיוון שהמערכת שפיתחנו הינה א- סינכרונית, כלומר ללא שעון, נצטרך לחבר למערכת רגיסטרים סינכרוניים בכניסה ולמוצא המערכת על מנת לבצע אנליזה בזמן.

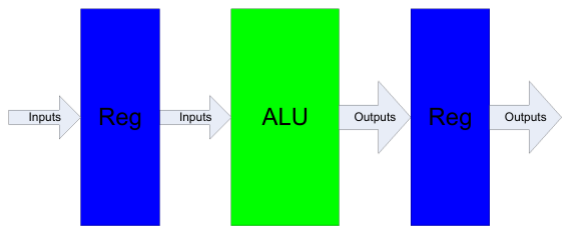
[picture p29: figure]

figure 8: ALU padded with registers for measurements לצורך כך, יצרנו קובץ חדש העוטף את המערכת ברגיסטרי כניסה ויציאה על מנת לחשב את המסלול הקריטי ואילוצי התזמון. כזכור המסלול הקריטי הקובע את התדר המקסימלי של המערכת נקבע על ידי הזמן הארוך ביותר שלוקח למידע לזרום מכניסה ליציאה, כלומר במקרה של המעגל הקומבינטורי מדובר בזמן שלוקח למידע לעבור החל מעליית השעון ועד להגעה יציבה לפני עליית השעון הבאה במסלול הארוך ביותר בתוך הALU.
להלן תוצאת החישוב של התדר המקסימלי:

figure 9: ALU maximum frequency measurement

להלן תוצאות מדוח Area של ה-ALU:

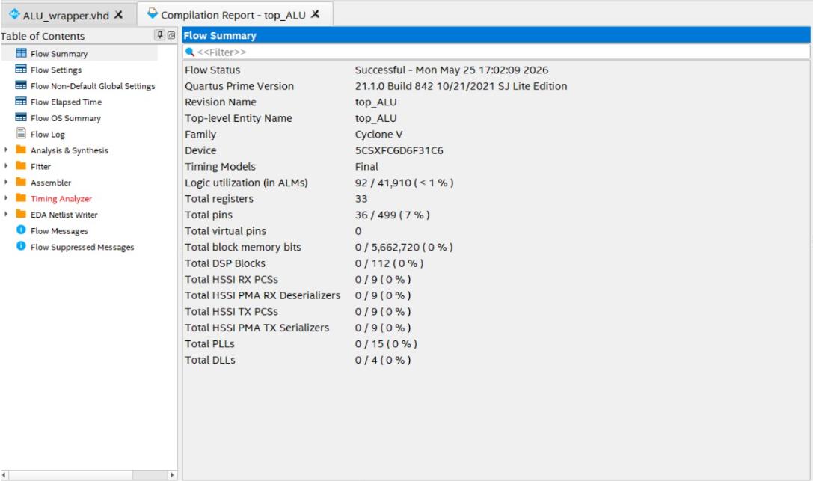
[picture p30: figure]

figure 10: ALU Area measurement

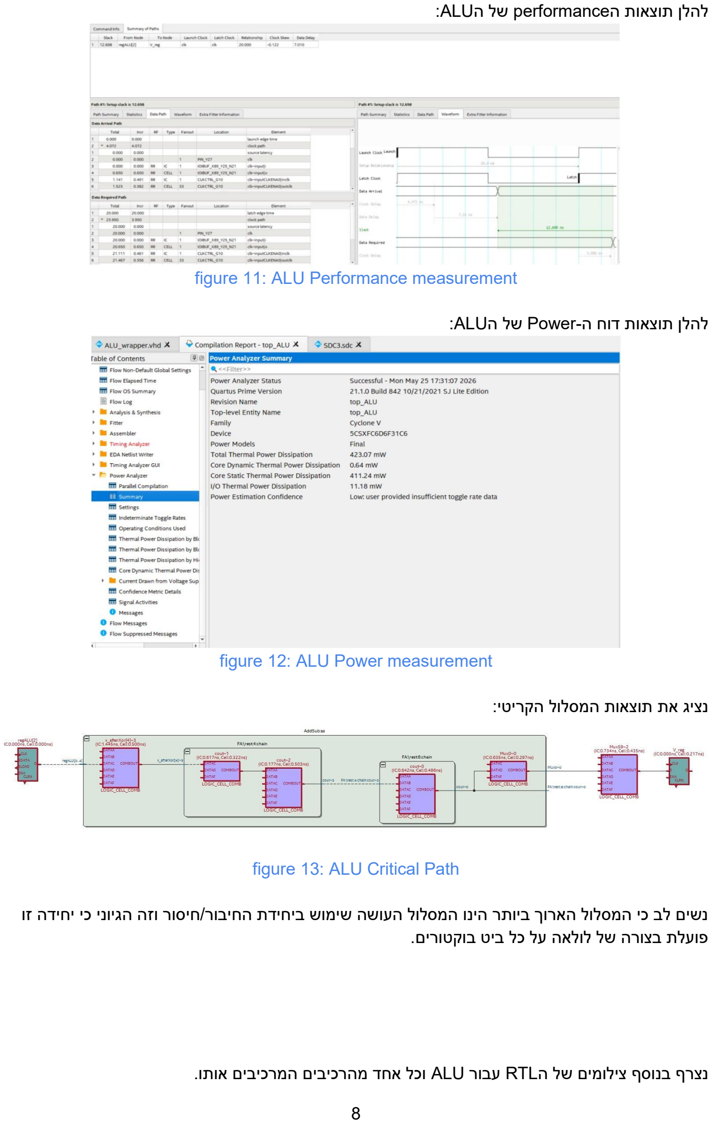
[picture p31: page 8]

להלן תוצאות הperformance של הALU:

figure 11: ALU Performance measurement

להלן תוצאות דוח ה -Power של הALU:

figure 12: ALU Power measurement

נציג את תוצאות המסלול הקריטי:

figure 13: ALU Critical Path

נשים לב כי המסלול הארוך ביותר הינו המסלול העושה שימוש ביחידת החיבור/חיסור וזה הגיוני כי יחידה זו פועלת בצורה של לולאה על כל ביט בוקטורים.

נצרף בנוסף צילומים של הRTL עבור ALU וכל אחד מהרכיבים המרכיבים אותו.

צילום של RTL של ה -TOP_ALU:

figure 14: ALU Top RTL Diagram

צילום של RTL של ה -SUB/ADDER: נשים לב כי הוא משתמש בבלוקים של רכיב הFA בתוך לולאה.

figure 15: ALU AdderSub Module RTL Diagram נשים לב כי ישנם 8 מוקסים ביציאה וזאת כתלות בקוד הפעולה נוציא רק את :Logic-של ה RTL צילום של תוצאת הפעולה התואמת לקוד

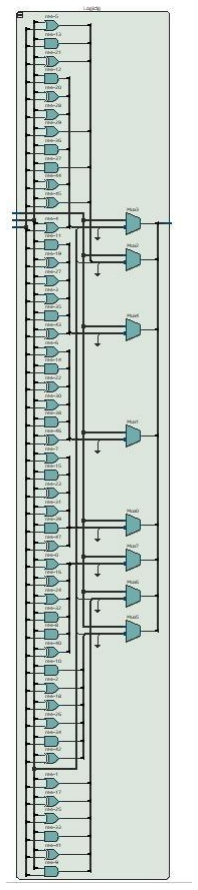
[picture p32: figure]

figure 16: ALU Logic Module RTL Diagram

צילום של RTL של ה -Shifter:

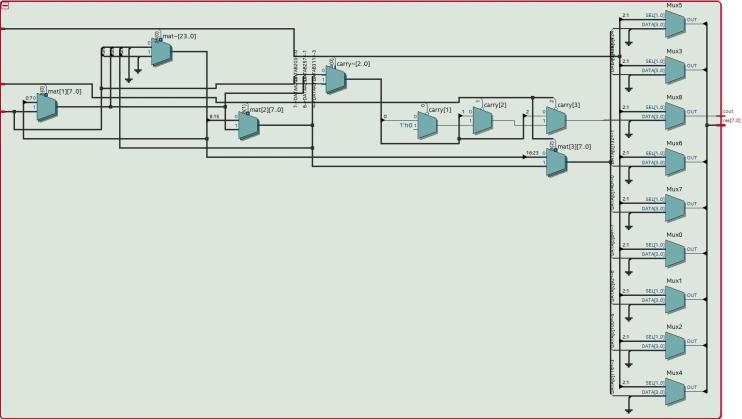
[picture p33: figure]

figure 17: ALU Shifter Module RTL Diagram

צילום של RTL של ה -FA: מממש בצורה ישירה לפי שערים לוגים את פעולת הFA.

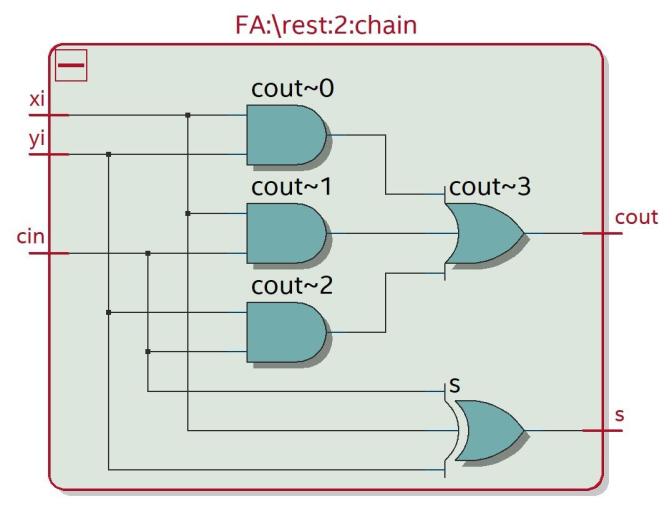
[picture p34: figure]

figure 18: FA Module RTL Diagram
.2חלק סינכרוני PWM:
כעת נציג את הביצועים של החלק הסינכרוני של המערכת - יחידת הPWM. כיוון שהטיימר הוא מעגל סינכרוני בעצמו לא נדרש לרפד ברגיסטרים את המערכת על מנת למדוד את המסלול הקריטי. להלן תוצאות עבור חלק זה:
תחילה Fmax:

figure 19: maximum frequency for PWM unit נשים לב כי תדר יחידה זו מהיר משמעותית מהחלק הקומבינטורי וזאת כי הלוגיקה הנדרשת לביצועה פשוטה בהרבה כך שהמסלול הקריטי קצר יותר וכתוצאה מכך היחידה יכולה לפעול בתדר גבוה יותר.
להלן תוצאות מדח הArea של ה- PWM:


figure 20: Area measurement for PWM unit להלן תוצאות הperformance של הPWM:


figure 21: Performance measurement for PWM unit להלן תוצאות דח ה-Power של הPWM:

figure 22: Power measurement for PWM unit

נצרף בנוסף צילום של הRTL עבור PWM:

figure 23: RTL for PWM unit

:The PPA characterization of the digital system , | הנתונים | של | סיכום | להלן


figure 24: Summary report PPA for entire System

.3דוחות של המערכת כולה :
תדר מקסימלי:

figure 25: maximum frequency for entire System

מסלול קריטי: בתמונה השנייה מופיע בכחול מודגש במסלול הקריטי

figure 26: Critical Path from node to node


figure 27: Critical Path sketch נתוני הספק:


figure 28: Power measurement for entire System

צילום של הRTL של המערכת כולה:

figure 29: RTL Diagram for entire System

# סימולצייה בSIM Model :

להלן צילומי מסך עבור הסימולציה של המערכת כולה המאחדת את החלק של ה -ALU והחלק של ה- PWM דוגמה ראשונה:
ניתן לראות כי עבור קוד ALU 00001 נוצר PWM במצב SET/RESET( הסיגנל הסגול(. ניתו לראות כי עבור y, 5=x =10 נוצר PWM עם DC של .50%


figure 30: ADD operation shown in TestBench
דוגמה שנייה:
ניתן לראות כי עבור קוד ALU 00010 נוצר PWM במצב Toggle(הסיגנל הסגול(. ניתן לשים לב כי הפעולה הקודמת הינה 01000 שזה חיבור בין X ל Y ואכן ניתן לראות שהתוצאה ,15 נציין כי פעולות אריתמטיות המשתמשות ב ALU מבוצעות ב-מחזור שעון אחד ולכן בסימולציה זה נראה כי התוצאה מיידית.


figure 31: Toggle operation shown in TestBench
להלן צילום מסך מסימולציה TOP_FPGA הממחישה את השילוב של המערכת הדיגטלית ביחד עם הממשק למשתמש שכולל לחצנים, סוויצ'ים ותצוגה. ניתן לראות בדוגמה זאת כי קוד הפעולה הוא 01000 שזוהי פעולת חיבור בין x ל y . גם כאן Y 5=X=.10
ניתן לראות את השינוי בסינגל SW כדי להכניס את הערכים האלו בבינארי, נשים לב כי SW9 נשאר 0 מאחר ואנו רוצים בפעולה אריתמטית וקטורים באורך של 8 ביט בלבד. ניתן לראות כי הסינגל המייצג את הלחצנים )KEYS )משתנה כל פעם בהתאם להכנסת X ו Y לALU, כאשר KEY0 מאפשר להכניס לY ו KEY1 מאפשר להכניס לX ואילו X2 טוען את הפקודה עצמה. נציין כי הלחצנים הם במצב של Low-Active כלומר כאשר הם נלחצים הם משתנים מ 1 ל .0 לאחר לחיצה על KEY2 ושינוי הוקטור ל 1011- נשים לב כי התוצאה נהיית 15 ואילו הלדים שלנו משתנים בהתאמה.
לדים 9-5 מציגים את קוד הפעולה עצמה, לדים 0-3 מציגים את ארבעת הדגלים ואילו לד 4 חסר שימוש ולכן מופיע באדום בסימולציה.


figure 32: ADD operation shown in TestBench including user interface

# ורפיקציה חומרתית Tap Signal:

נרצה לבצע וריפיקציה של החומרה על ידי Tap Signal של ה- Quartus. נתפוס בזמן אמת את מצב הסיגנלים של הרכיב, ובהתאם לסיגנל שאותו נרצה לתפוס, ברגע שהסיגנל ישתנה למה שאנחנו רוצים נקבל את תוצאות הסיגנלים שנדפיס למסך. לצורך כך בדקנו 3 פעולות אחת מכל סוג. מקרה ראשון פעולת sub/Adder: ביצענו פעולת חיבור בין המספרים 1 ו .5


figure 33: ADD operation shown on FPGA ניתן לראות כי אכן התוצאה היא ,6 ואילו בלדים 9-5 אכן מציגים את קוד פעולת החיבור : .01000 להלן צילום מ-Tap Signal:


figure 34: ADD operation shown on SignalTap in Quartus ניתן לראות כי בלחיצה על KEY 2 הנתונים משתנים, הלדים משתנים בהתאמה, לוחות הHEX משתנים גם כן.

פעולת Shifter:
ביצענו פעולת הזזה שמאלה SHL , כלומר שווה לערך להכפלה ב2 את Y, מאחר וY שווה 5 נרצה לראות תוצאה של 10 וזה אכן מה שקיבלנו , A שזה 10 בייצוג הקסדצימלי.


figure 35: SHL operation shown on FPGA להלן צילום מTap Signal:


figure 36: SHL operation shown on SignalTap in Quartus

גם כאן הטריגר הוא KEY2 ולחיצה עליו משנה את הנתונים, הלדים משתנים בהתאמה וככה גם ALUOUT ומסכי הHEX .

מקרה שלישי פעולת Logic:
ביצענו פעולת OR בין ב 1 ל ,2 ולכן נרצה לראות בתוצאה את המספר .3


figure 37: OR operation shown on FPGA הפעולה OR לפי ה- ISA היא 11001 וזה אכן מה שמוצג בלדים ,9-5 אין שום דלג שאמור להדלק ולכן דגלים 0-3 נשארים כבויים.
נצרף תמונה מ -Tap Signal:


figure 38: OR operation shown on SignalTap in Quartus גם כאן הטריגר הוא KEY2 ולחיצה עליו משנה את הנתונים, הלדים משתנים בהתאמה וככה גם ALUOUT ומסכי הHEX .

### בדיקת PWM במעבדה:

בנוסף בשביל לבוא מוכנים למעבדה ולמטלת זמן אמת ולצורך בדיקה כי מטלת הכנה עובדת בצורה מקסימלית ניגשנו למעבדה על מנת לבדוק כי PWM אכן עובד בציוד המעבדה ולא להסתמך רק על TB. מקרה ראשון Reset/Set:
הגדרנו את X וY , נציין כי SW9 למעלה כי היינו צריכים וקטור באורך .16

figure 39: SET/RESET mode operation shown on FPGA
מאחר וX קטן פי 4 מY ואנחנו במצב זה נרצה לראות Cycle Duty של .75%

figure 40: SET/RESET mode operation shown on Oscilloscope נבחין כי הנתונים אכן נכונים. מקרה שני Toggle:
הגדרנו את X וY , נציין כי SW9 למעלה כי היינו צריכים וקטור באורך .16

figure 41:Toggle mode operation shown on FPGA בToggle הCycle Duty צריך להיות תמיד 50% ובנוסף בלי קשר לפי נתוני X ו Y צריך להיות ככה.

figure 42:Toggle mode operation shown on Oscilloscope

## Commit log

2026-05-31 Complete Lab 4 implementation and validation files
    [stp2.stp]
2026-06-22 Add complete LAB5 folder
    [stp1.stp, stpSingleCycle.stp]
2026-09-01 Add final project: MCU and HW-Accelerators architecture and design
    [stp1.stp]
